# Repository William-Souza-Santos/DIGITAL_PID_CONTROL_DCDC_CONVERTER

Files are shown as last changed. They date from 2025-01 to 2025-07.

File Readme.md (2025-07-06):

# ⚡ FUZZY CONTROL APPLIED TO A BIDIRECTIONAL BUCK-BOOST DC-DC CONVERTER

This project presents the design and implementation of a four-switch bidirectional buck-boost DC-DC converter, featuring a fuzzy logic-based digital control system. The converter is designed for embedded and automotive power applications, ensuring stability, precision, and adaptability in bidirectional energy management.

---

## 🔍 Circuit Overview

<p align="center">
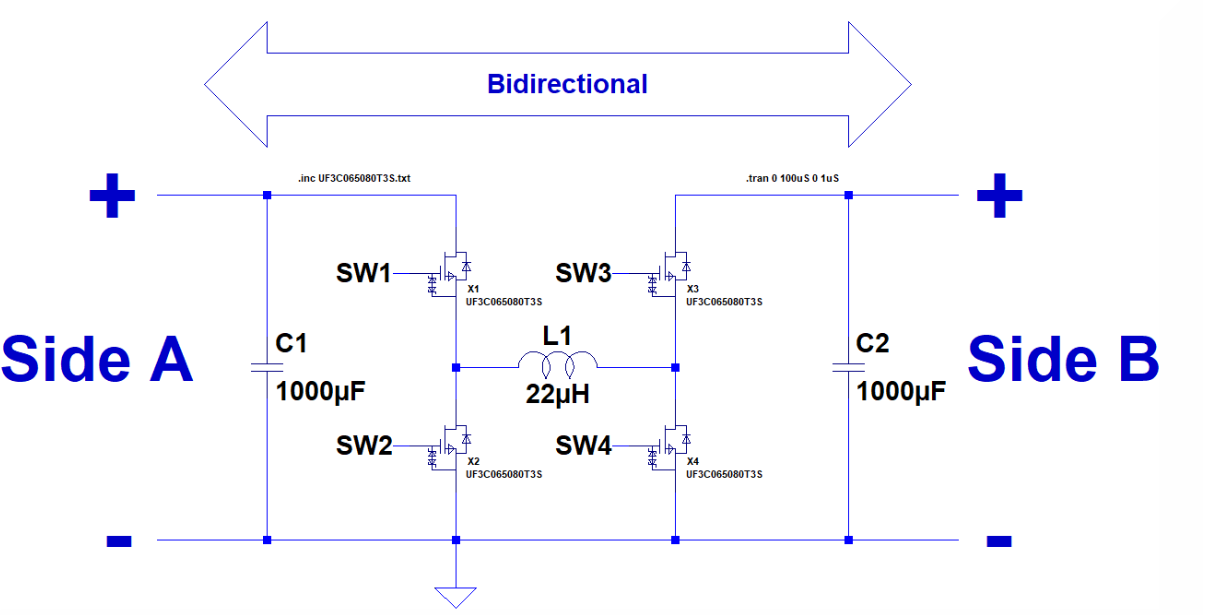
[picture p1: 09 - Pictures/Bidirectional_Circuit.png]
  
</p>

---

## 🔧 Project Highlights

- Implementation of a non-linear fuzzy logic controller to dynamically regulate the converter's duty cycle.
- Simulations conducted in **MATLAB/Simulink** and **Proteus**, covering both open-loop and closed-loop control strategies.
- Embedded firmware developed for the **ATmega328P** microcontroller to enable real-time control.
- Complete **PCB design**, including schematic capture, PCB layout, and 3D visualization.

---

## 🎯 Objective

To design and validate a high-efficiency bidirectional DC-DC converter capable of operating in buck, boost, and buck-boost modes, maintaining stable output voltage under varying load and input conditions.

---

## 🚗 Motivation: Automotive and Beyond

The primary motivation for this project lies in the growing demand for reliable DC-DC power converters in **automotive systems**, where multiple ECUs operate at different voltage levels. A bidirectional buck-boost converter ensures safe and efficient energy flow between these modules and energy storage systems such as batteries or supercapacitors.

Although tailored for automotive use, the converter is also applicable to:

- 🔋 Battery Management Systems (BMS)  
- ☀️ Renewable Energy Systems  
- 🏭 Industrial Automation  
- ✈️ Aerospace Power Electronics  

---

## 🧪 Simulation: Circuit in Proteus

<p align="center">
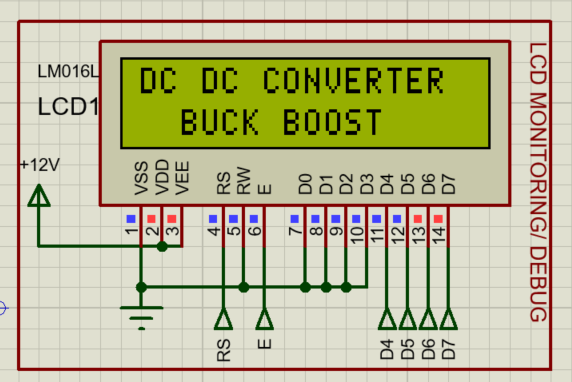
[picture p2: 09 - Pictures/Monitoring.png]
  
</p>

<p align="center">
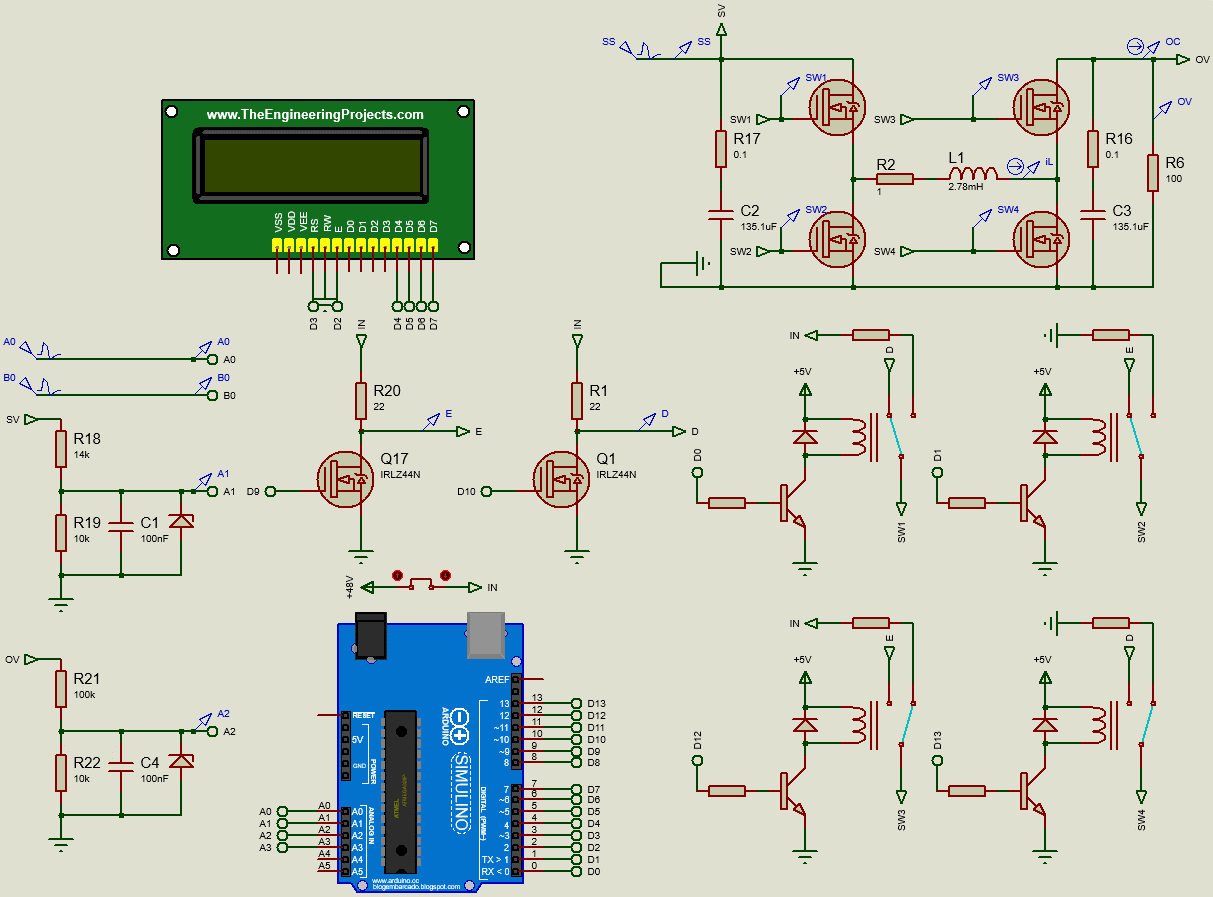
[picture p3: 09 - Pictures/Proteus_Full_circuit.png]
  
</p> 

---

## 📝 Theoretical Foundations

<p align="center">
  <strong>Operating Modes</strong><br>
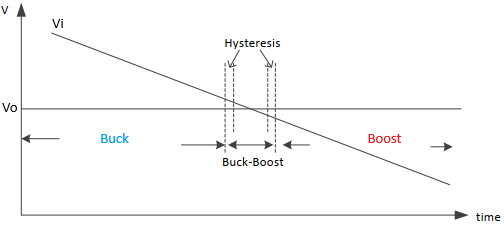
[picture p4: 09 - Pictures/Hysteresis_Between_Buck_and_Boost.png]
  <br>
</p>

<p align="center">
  <strong>BUCK</strong><br>
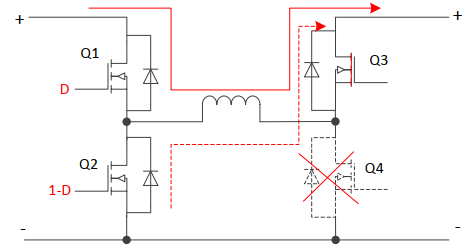
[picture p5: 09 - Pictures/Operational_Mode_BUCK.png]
  <br>
</p>

<p align="center">
  <strong>BUCK-BOOST (Transition Mode)</strong><br>
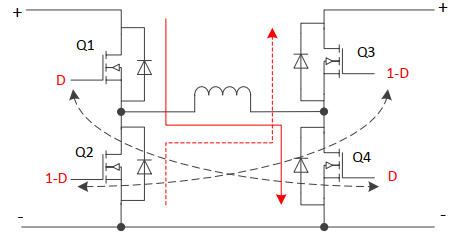
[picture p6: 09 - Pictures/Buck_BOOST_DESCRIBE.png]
  <br>
</p>

<p align="center">
  <strong>BOOST</strong><br>
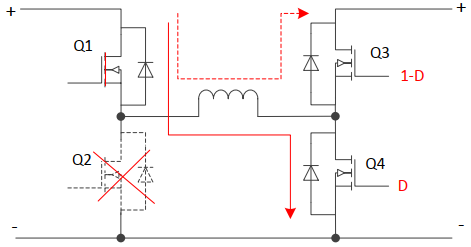
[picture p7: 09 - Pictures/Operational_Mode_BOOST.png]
  <br>
</p>

---

## 📝 Theoretical Foundations (Table Operating)

<p align="center">
  <strong>A-B OPERATING</strong><br>
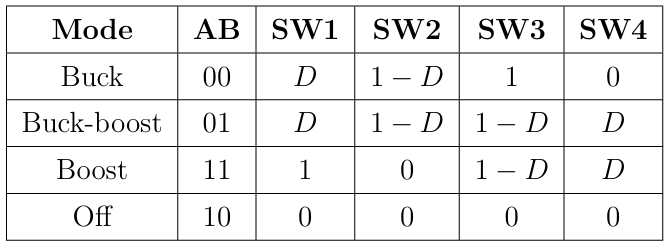
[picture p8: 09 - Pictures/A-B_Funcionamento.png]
  <br>
</p>

<p align="center">
  <strong>B-A OPERATING</strong><br>
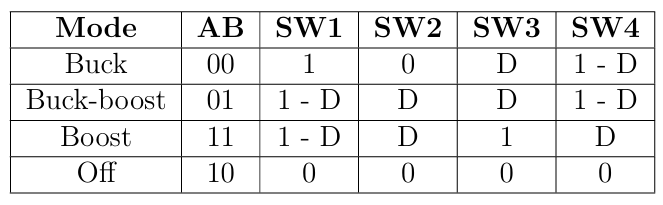
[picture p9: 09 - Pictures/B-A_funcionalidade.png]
  <br>
</p>

---

## 🔁 Bidirectional Operation (Open-Loop Tests)

<p align="center">
  <strong>A → B (Boost Mode)</strong><br>
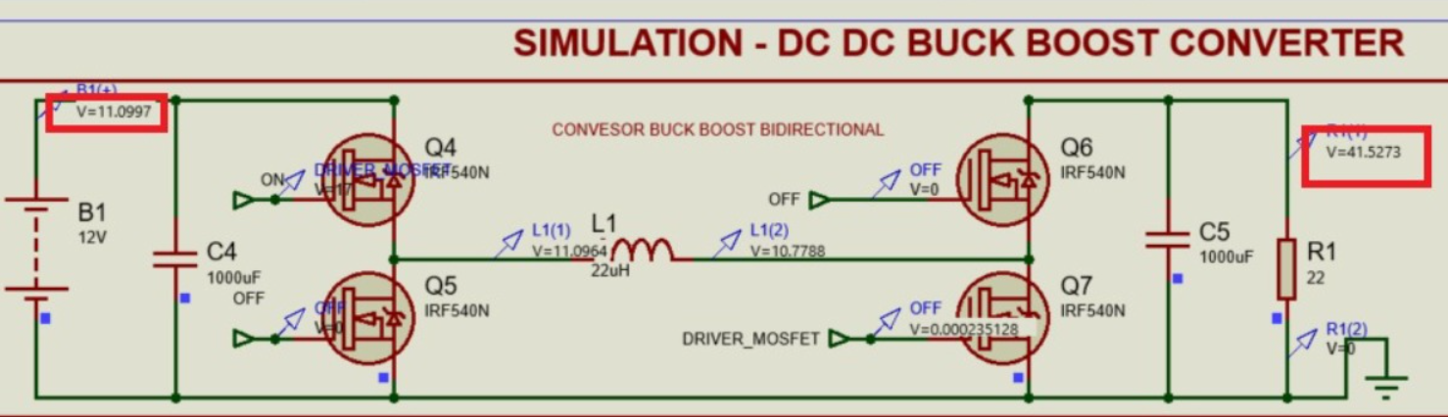
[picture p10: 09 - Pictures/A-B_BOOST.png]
  <br>
</p>

<p align="center">
  <strong>A → B (Buck Mode)</strong><br>
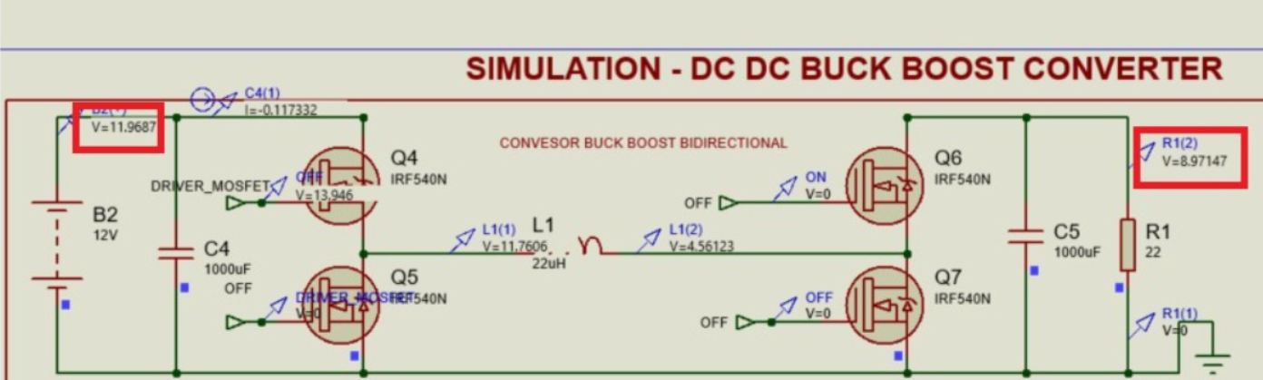
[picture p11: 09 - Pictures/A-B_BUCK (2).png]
  <br>
</p>

<p align="center">
  <strong>B → A (Boost Mode)</strong><br>
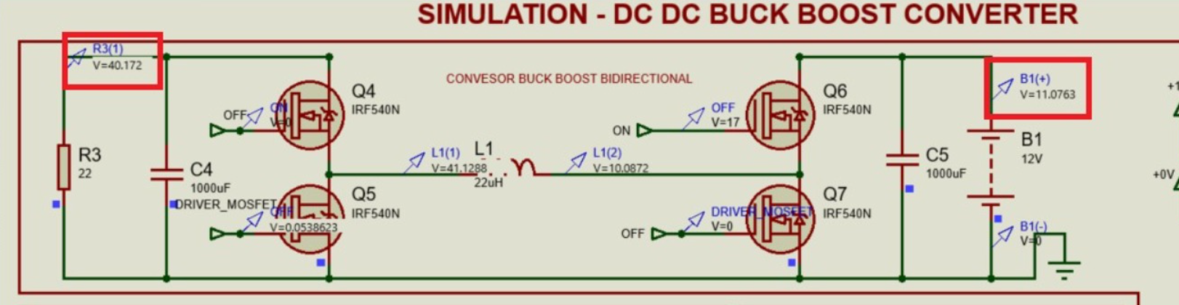
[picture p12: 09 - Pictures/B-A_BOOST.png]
  <br>
</p>

<p align="center">
  <strong>B → A (Buck Mode)</strong><br>
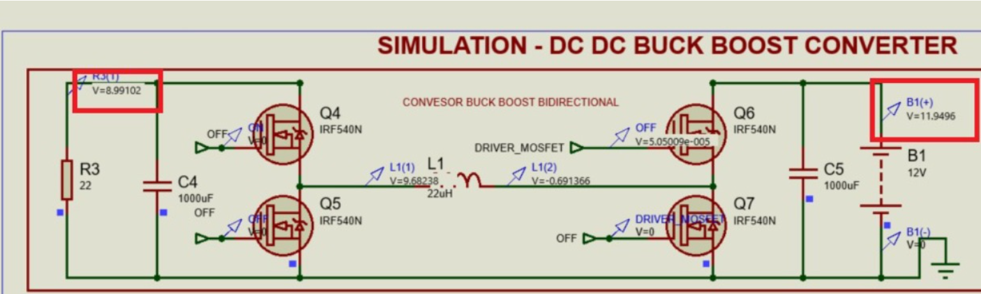
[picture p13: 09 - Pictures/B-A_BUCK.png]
  <br>
</p>

<!--
## 📉 Theorical Fundamentation and Transition Mode

<p align="center">
  <strong>Buck Waveform</strong><br>
  <img src="09 - Pictures/Curve_buck.bmp" width="800"><br>
</p>

<p align="center">
   <strong>Boost Waveform</strong><br>
  <img src="09 - Pictures/Curves_Boost.bmp" width="800">
</p>
-->

---
## 🖥️ Choosing a Microcontroller

<p align="center">
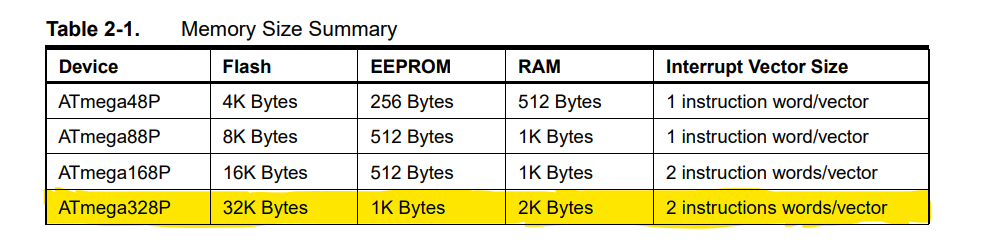
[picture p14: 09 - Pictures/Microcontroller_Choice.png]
  <br>
</p>

---

## 🤖 Fuzzy Control System (Closed-Loop in Simulink)

<p align="center">
  <strong>Closed-Loop Control Model</strong><br>
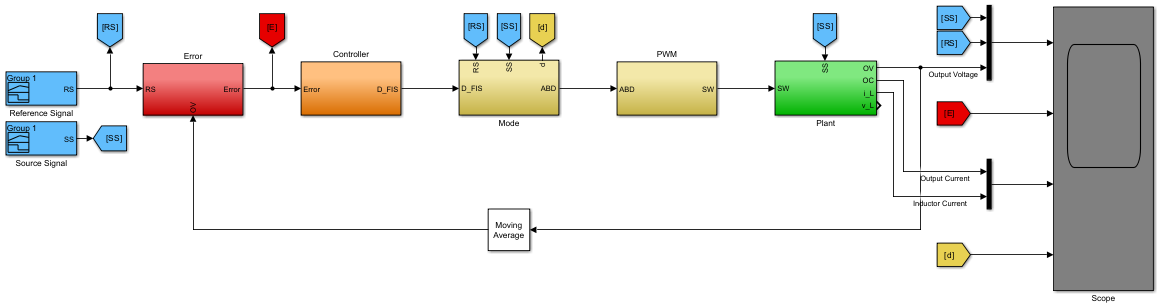
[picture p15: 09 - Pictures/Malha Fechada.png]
  <br>
</p>

---

## 🧩 Schematic

<p align="center">
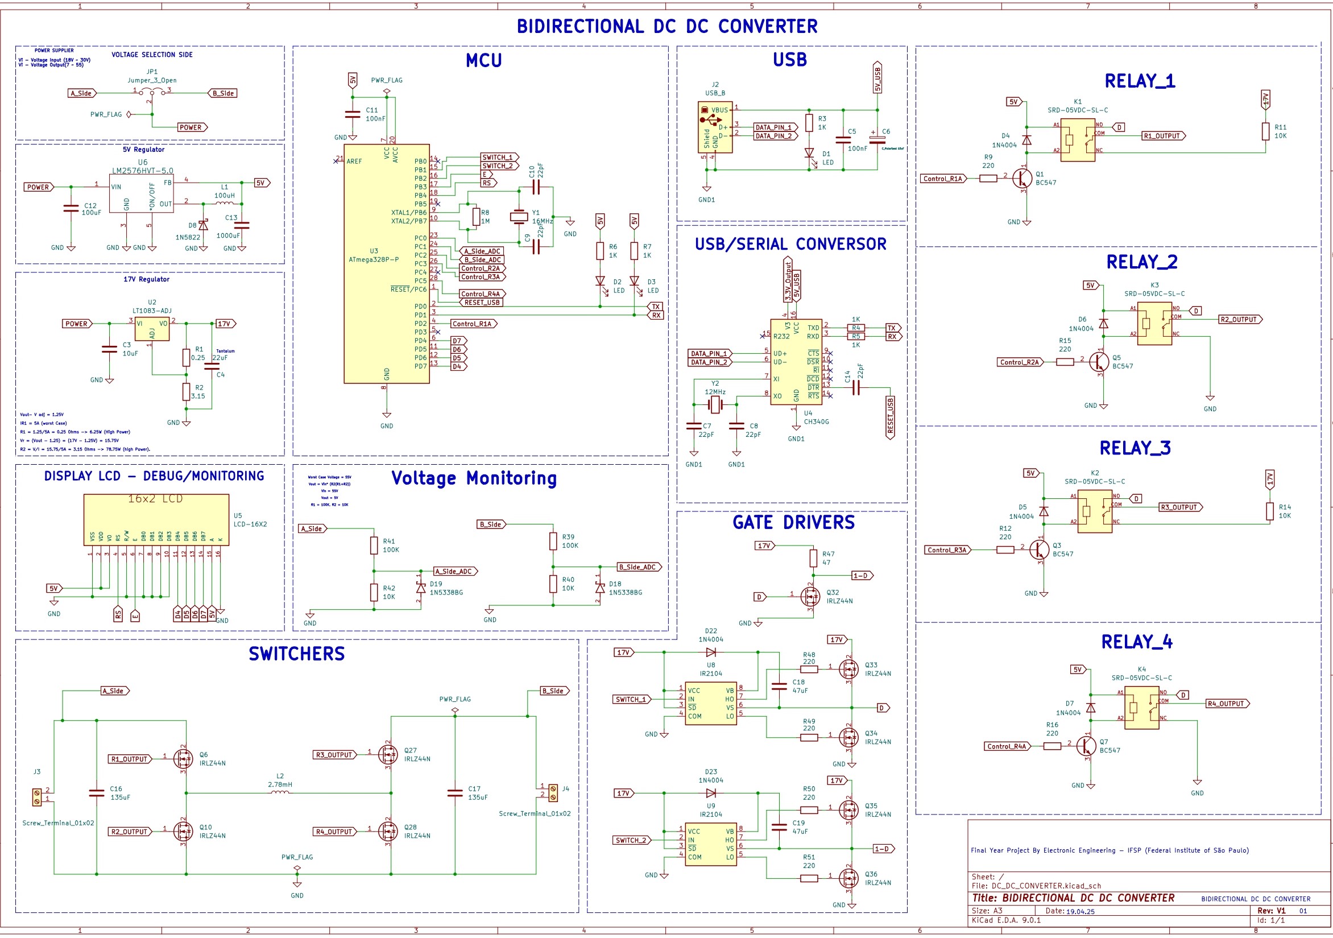
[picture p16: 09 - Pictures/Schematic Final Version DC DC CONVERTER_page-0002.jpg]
  <br>
</p>

---

## 🧱 3D PCB View

<p align="center">
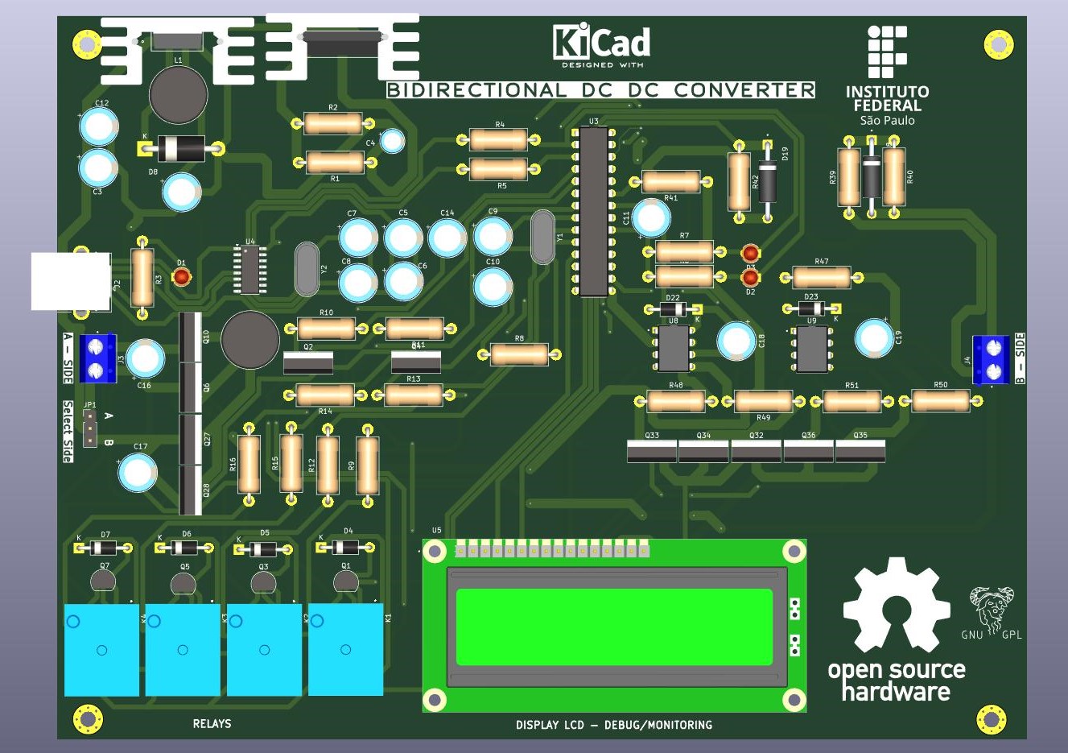
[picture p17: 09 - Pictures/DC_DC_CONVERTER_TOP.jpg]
  <br>
</p>

---

## 👨‍💻 Authors

- Marcelo Oliveira de Jesus Júnior  
- Victor Pereira dos Santos  
- William Souza Santos

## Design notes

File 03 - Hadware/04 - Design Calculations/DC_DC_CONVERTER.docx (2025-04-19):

Os cálculos a seguir foram referenciados no aplication notes da Texas Intruments:

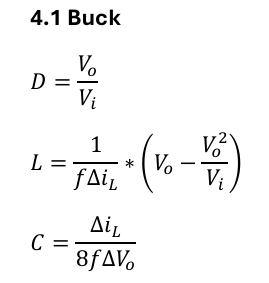
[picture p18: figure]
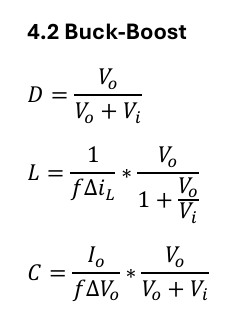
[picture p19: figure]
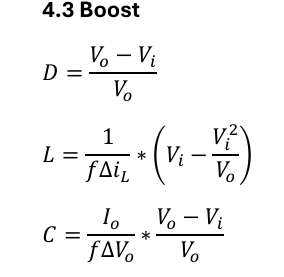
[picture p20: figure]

1. Design
- Input Voltage Range: Vi = [18,30] V
- Duty Cycle Range D = [0.2,0.85]
- Output Voltage: Vo = [1 – 55] V (Variável)
- Output Current: 2A
- Switching Frequency: f = 10kHz
- Inductor current ripple: 0.6 (30%)
- Output Voltage Ripple: 1V (variável)
2. Operating Mode

Mode | Vi | D | Vi/Vo
Buck | [25 - 30] | [Vo/Vi] | 25/Vo (1.10)
Buck-Bost | [22 - 25] | [Vo/(Vo+Vi)] | -
Boost | [18 - 22] | [(Vo-Vi)/Vo] | 22/Vo (0.9)

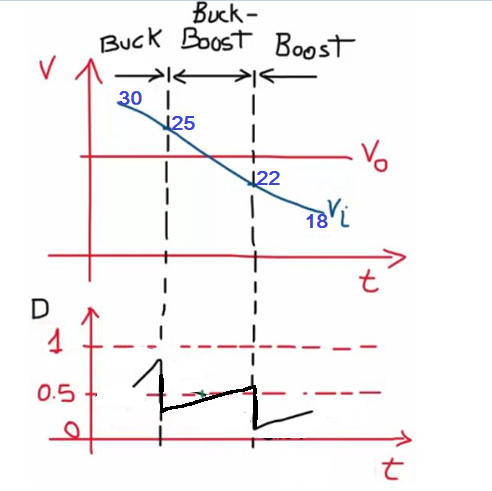
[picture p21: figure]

3. Inductor and capacitor Buck

Vomax = 27V

VoMin = 1V

Lmax = 0.00045

Lmin = 1.61x10^-4

  3.1 Inductor and capacitor Buck Boost

VoMax = 25

VoMin = 22

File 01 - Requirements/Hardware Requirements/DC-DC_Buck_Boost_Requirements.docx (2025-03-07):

# Requirements Document - DC-DC Buck-Boost Converter

## 1. Introduction

### 1.1 Objective

This document defines the technical and functional requirements for the development of a DC-DC Buck-Boost converter, detailing the electrical, mechanical, and environmental specifications of the system.

### 1.2 Scope

The converter will be designed for embedded applications, powering loads of sensitive electronic devices. The system must be efficient, compact, and reliable.

## 2. General Requirements

### 2.1 Electrical Specifications

- **Input Voltage (Vin):** 17V to 30V
- **Output Voltage (Vout):** 20V to 45V adjustable
- **Output Current (Iout):** Up to 5A
- **Efficiency:** >= 97% under nominal conditions
- **Switching Frequency:** 100kHz to 500kHz (to be defined in the future)
- **Output Voltage Ripple:** <= 50mVpp (to be defined in the future)
- **Protections:** Overcurrent, overvoltage, short-circuit, and overtemperature (to be defined in the future)

### 2.2 Mechanical Requirements

- Maximum dimensions: 50mm x 50mm x 20mm
- Weight: <= 50g
- Connection interface: Standard terminals or connectors

### 2.3 Environmental Conditions

- **Operating Temperature:** -40°C to 85°C
- **Relative Humidity:** 10% to 90% (non-condensing)
- **Vibration Resistance:** According to MIL-STD-810G standard

## 3. Functional Requirements

- Ability to operate in Buck, Boost, or Buck-Boost mode automatically
- PWM control with dynamic adjustment
- Voltage and current monitoring via digital interface (I2C, SPI, or UART)
- Closed-loop feedback for precise regulation

## 4. Reliability and Testing Requirements

- Maximum load and voltage variation tests
- Transient response test
- Thermal analysis for heat dissipation verification
- Electromagnetic immunity testing (EMI/EMC)

## 5. Documentation and Certification

- Electrical schematic and PCB layout
- Compliance analysis with IEC 60950-1 and CISPR 22 standards
- User and integration manual

## 6. Final Considerations

The design of the DC-DC Buck-Boost converter must follow the guidelines presented in this document to ensure an efficient and reliable product suitable for its intended applications.

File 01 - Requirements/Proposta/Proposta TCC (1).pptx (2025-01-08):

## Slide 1

CONTROLE PID DIGITAL APLICADO AO CONVERSOR DC DC BUCK BOOST

BACHARELADO EM ENGENHARIA ELETRÔNICA

PROPOSTA DE TCC

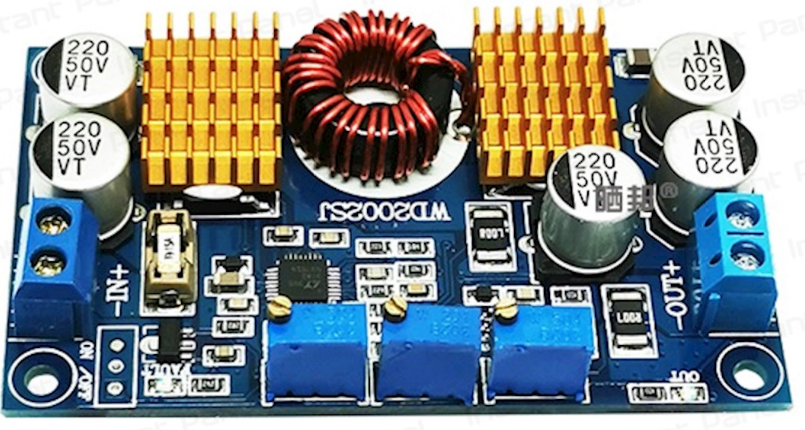
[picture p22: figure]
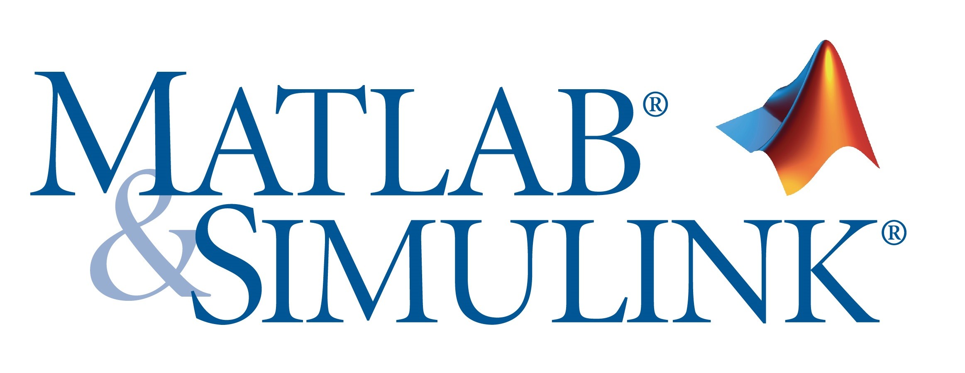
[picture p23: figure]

ALUNOS:
VICTOR PEREIRA – SP3060608
WILLIAM SOUZA SANTOS – SP3061418
(Obs: possivelmente será acrescentado mais pessoas).

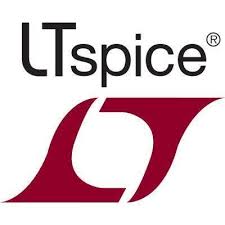
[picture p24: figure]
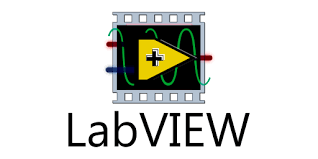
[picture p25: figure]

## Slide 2

MOTIVAÇÃO : APLICAÇÃO EM INTERFACE ENTRE MÓDULOS ELETRÔNICOS AUTOMOTIVOS DE DIFERENTE TENSÕES

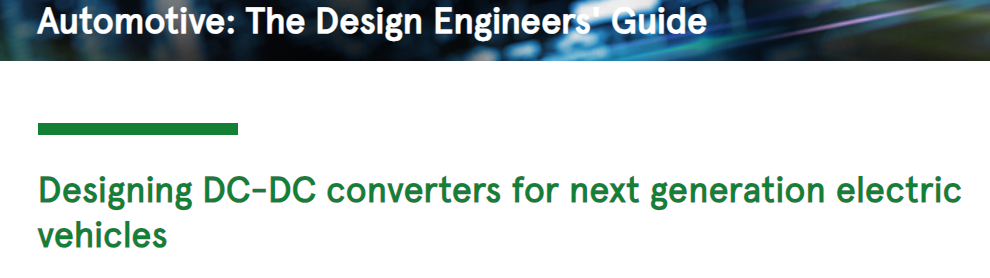
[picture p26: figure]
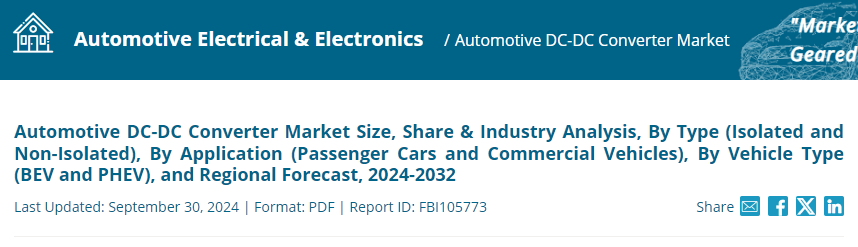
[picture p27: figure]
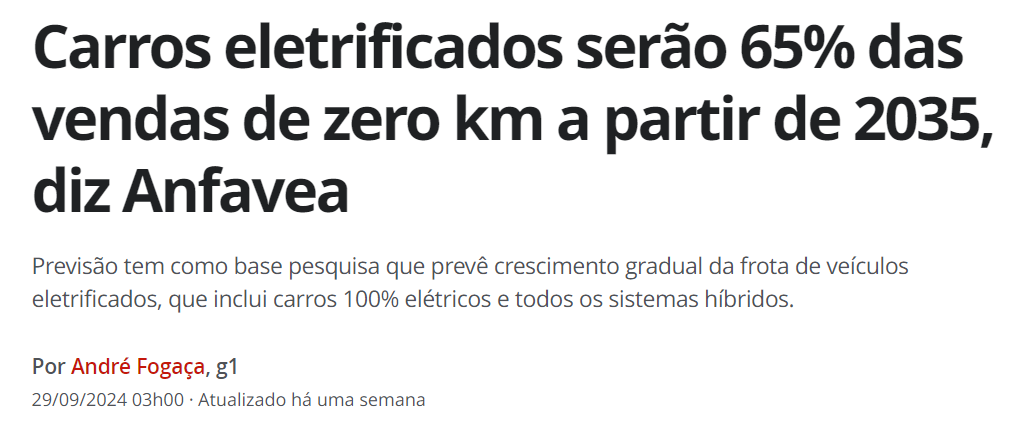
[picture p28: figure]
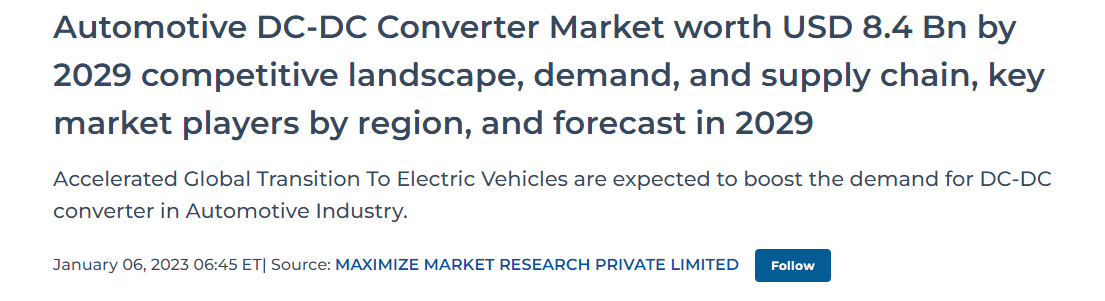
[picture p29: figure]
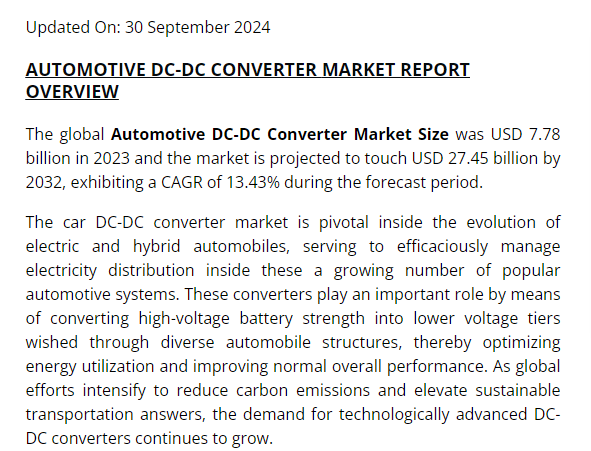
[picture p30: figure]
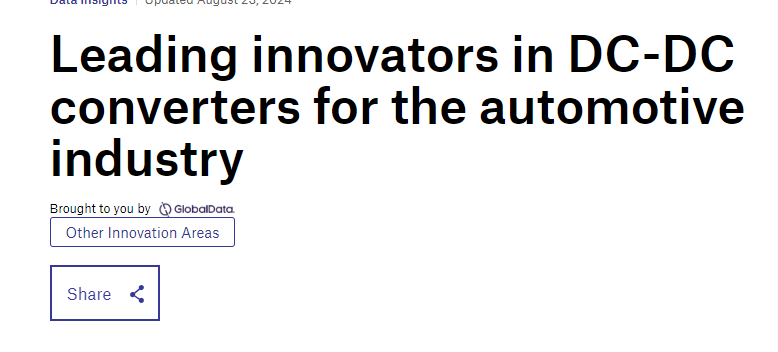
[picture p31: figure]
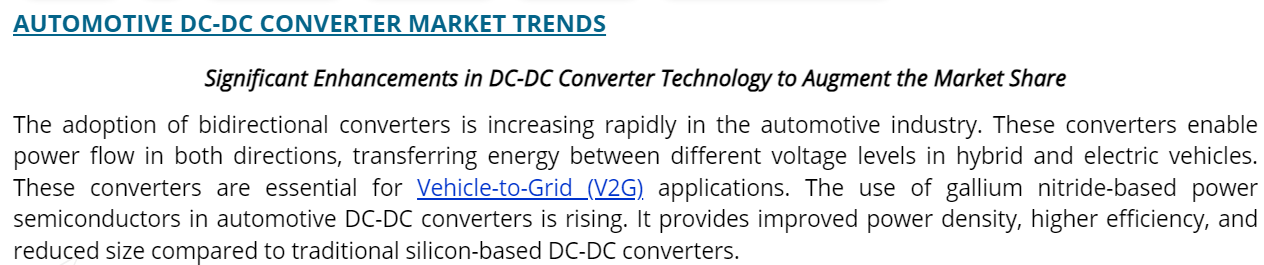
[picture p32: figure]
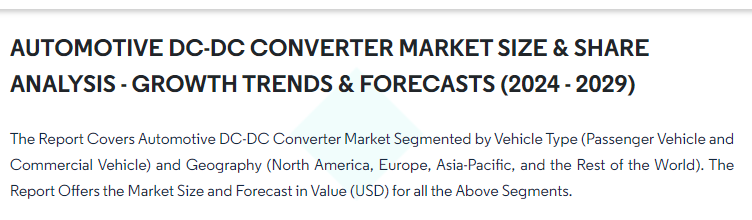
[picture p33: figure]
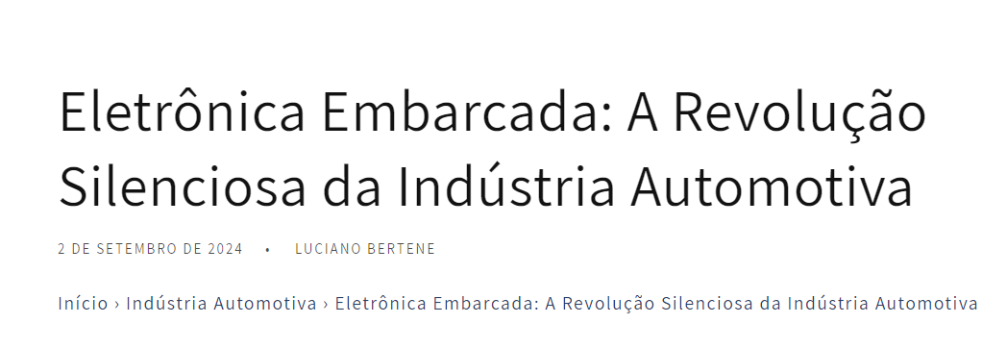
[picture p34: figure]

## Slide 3

EMPRESAS QUE TEM PROJETOS SIMILARES

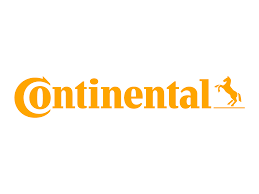
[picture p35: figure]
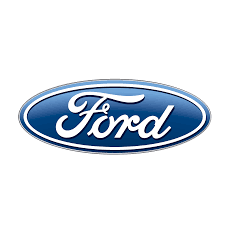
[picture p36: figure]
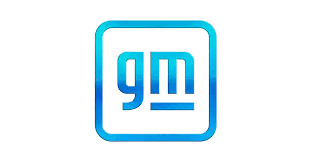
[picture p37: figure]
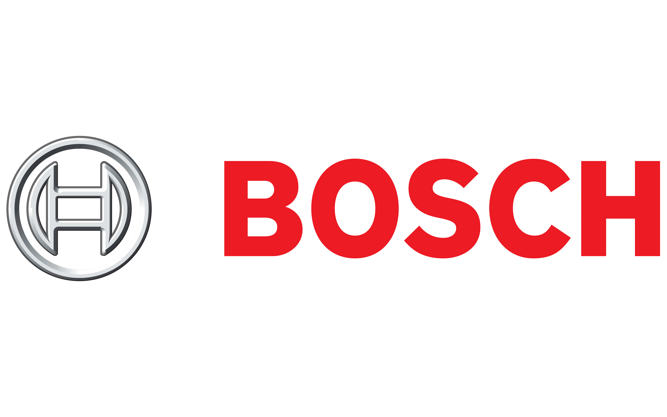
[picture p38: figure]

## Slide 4

EMPRESAS QUE TEM PROJETOS SIMILARES (PORTFÓLIO)

Portfólio das Empresas

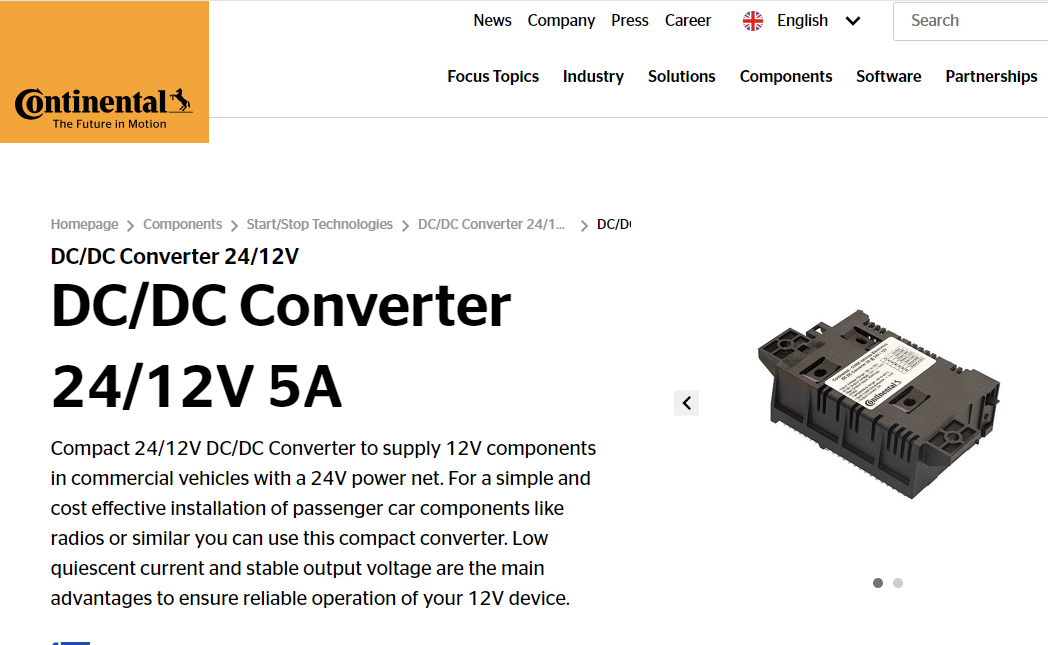
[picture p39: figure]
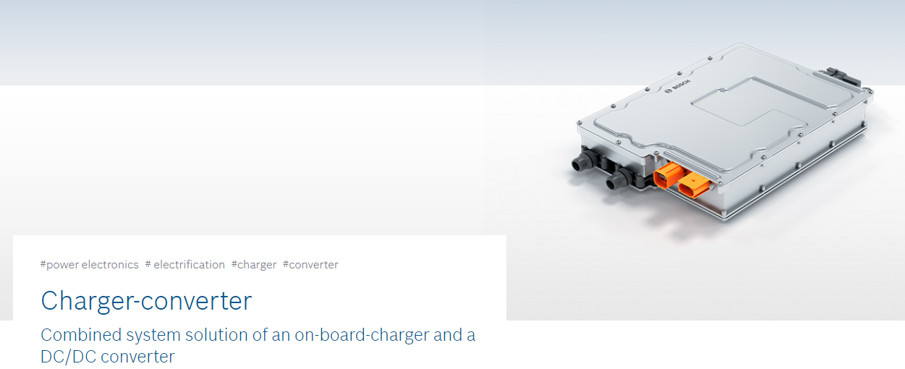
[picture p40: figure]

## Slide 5

OBJETIVO : DESENVOLVIMENTO DE UM CONVERSOR DC DC BUCK BOOST COM COMPONENTES DISCRETOS MICROCONTROLADO UTILIZANDO UM PID DIGITAL

HW (Hardware) Features:
Microcontrolador: Utilizar um microcontrolador com conversores ADC (Analog-to-Digital Converter) e DAC (Digital-to-Analog Converter) integrados.
Conversor Buck-Boost: Implementação de um conversor Buck-Boost com indutor, capacitor, MOSFETs e diodos
Sensores de tensão e corrente: Sensores como resistores de shunt para medir a corrente e divisores de tensão para a leitura da tensão de entrada e saída
Proteções: Implementar proteções como limitadores de corrente, proteção contra sobretensão e sobretemperatura.
Sistema de comunicação: Implementação de comunicação serial (I2C, SPI, UART) para monitoramento remoto ou integração com sistemas maiores.
*Operação Bidirecional: Capacidade de operar em ambos os sentidos de potência: O conversor pode transferir energia da entrada para a saída ou vice-versa (por exemplo, para sistemas de armazenamento de energia como baterias).

SW (Software) Features:
Ajuste automático dos parâmetros PID: Implementar métodos de auto-ajuste ou calibração automática dos parâmetros PID.
Filtros digitais: Uso de filtros digitais (ex: filtro de média móvel ou filtro passa-baixa) para suavizar leituras de sensores.
Interface gráfica (GUI): Desenvolvimento de uma interface gráfica simples para ajuste remoto de parâmetros PID e monitoramento dos valores do sistema.
Log de dados: Sistema de registro de dados para monitorar o comportamento do sistema ao longo do tempo e analisar o desempenho.
*Sistema de Telemetria: Monitoramento em Tempo Real, Ajustes Remotos, Registro e Análise de Dados.

*Feature avançada

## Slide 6

Fundamentação Científica (Alguns artigos que podem ser usados como consulta)

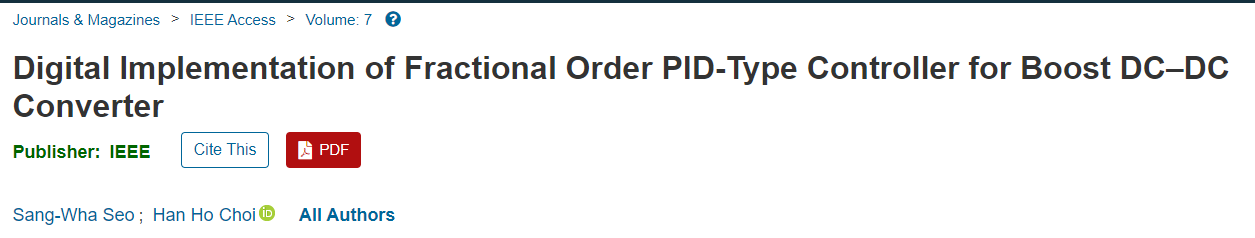
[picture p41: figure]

Link para o artigo: https://ieeexplore.ieee.org/document/8854776


Link para o artigo: https://pt.scribd.com/document/679721829/05744616


Link para o artigo: https://ieeexplore.ieee.org/document/8811451


Link para o artigo: https: https://theses.gla.ac.uk/82318/

Link para o artigo: https://www.sciencedirect.com/science/article/abs/pii/S0967066121001593


Link para o artigo: https://www.sciencedirect.com/science/article/pii/S1877050920310292

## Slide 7

Possíveis Orientadores (Com base no currículo lattes)

Possíveis Orientadores
DEL (Departamento de Engenharia Elétrica) – IFSP:
SARA DERESTE DOS SANTOS Lattes: http://lattes.cnpq.br/8110306745666405 (Microeletrônica)
RAFAEL CUERDA MONZANI Lattes: http://lattes.cnpq.br/7715420164654804 (Power Eletronics)
RICARDO PIRES Lattes: http://lattes.cnpq.br/7621984053230170 (Sistemas Automáticos/Microeletrônicos)
RODRIGO RECH Lattes: http://lattes.cnpq.br/8648052996681367 (Sistemas Embarcados)

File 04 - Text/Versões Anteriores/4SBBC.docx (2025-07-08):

1. Basic Configuration of a Buck-Boost Converter

2. Operating Principle

D=1-D

2.1 Synchronize Buck

D=(V_o)/(V_i)

V_i >V_o

Only two switches commutate.

Can’t operate with V_i =V_o or D=1 .

Q3 is fully turned on and Q4 is fully turned off. Q1 and Q2 are controlled by D and 1-D, respectively, the converter becomes a synchronize buck converter, as shown in Figure 4.


2.2 Synchronize Boost

D=1-(V_i)/(V_o)

Only two switches commutate.

Can’t operate with V_i =V_o or D=0 .

Q1 is fully turned on and Q2 is fully turned off. Q4 and Q3 are controlled by D and 1-D, respectively, the converter becomes a synchronize boost converter, as shown in Figure 5.


2.3 Synchronize Buck-Boost

D=(V_o)/(V_i +V_o)

V_i ≈V_o

Four switches commutate.

Can operate with V_i =V_o or D=0.5 .

Higher switches losses.

Lower efficiency.

Q1 and Q4 are controlled by D, Q2 and Q3 are controlled by 1-D. The converter becomes a synchronize buck-boost converter, as shown in Figure 6.


3. Operation mode

The 4-switch power stage changes its operation mode according to DC Bus and battery voltage, as shown in Figure 10. To prevent mode from bouncing, hysteresis is added between the buck and buck-boost modes and between the buck-boost and boost modes.


Closed-loop compensator must be designed for stable operation.

Transient perturbations during mode changes.

4. Implementation

MOSFETs used as switches.

High-side switches (S1, S3) need to be driven.

Dead time must be added to avoid shoot-through current.

Bootstrap cannot be used: it can’t keep high-side switches continuously on.

Typical solutions: transformer-based gate drivers, optocoupler-based gate drivers.

4.1 Buck

D=(V_o)/(V_i)

L=1/(fΔi_L)*(V_o -(V_o^2)/(V_i))

C=(Δi_L)/(8fΔV_o)

4.2 Buck-Boost

D=(V_o)/(V_o +V_i)

L=1/(fΔi_L)*(V_o)/(1+(V_o)/(V_i))

C=(I_o)/(fΔV_o)*(V_o)/(V_o +V_i)

4.3 Boost

D=(V_o -V_i)/(V_o)

L=1/(fΔi_L)*(V_i -(V_i^2)/(V_o))

C=(I_o)/(fΔV_o)*(V_o -V_i)/(V_o)

5. Design example

Input voltage range: V_i =[35,70] V

Duty cycle range: D=[0.1,0.85]

Output voltage: V_o =48 V

Output current: I_o =2 A

Switching frequency: f=100 kHz

Inductor current ripple: 0.6 A (30%)

Output voltage ripple: 1 V (2%)

Operating mode | Vi | D | Vi/Vo
Buck | [57-70] | [0.686,0.842] | 1.1875
Buck-boost | [43,57] | [0.457,0.527] | -
Boost | [35,43] | [0.104,0.271] | 0.8958


5.1 Inductor and Capacitor (Buck)

L_(max) =1/(fΔi_L)*(V_o -(V_o^2)/(V_i _(max)))=1/(100*10^3 *0.6)*(48-(48^2)/70)=0.251 mH

C=(Δi_L)/(8fΔV_o)=0.6/(8*100*10^3 *1)=0.75 uF

5.2 Inductor and Capacitor (Buck-Boost)

L_(max) =1/(fΔi_L)*(V_o)/(1+(V_o)/(V_i _(max)))=1/(100*10^3 *0.6)*48/(1+48/57)=0.434 mH

C_(max) =(I_o)/(fΔV_o)*(V_o)/(V_o +V_i _(min))=2/(100*10^3 *1)*48/(48+57)=10.6 uF

5.3 Inductor and Capacitor (Boost)

V_i >(V_o)/2

L_(max) =1/(fΔi_L)*(V_i _(min) -(V_i _(min)^2)/(V_o))=1/(100*10^3 *0.6)*(35-(35^2)/48)=0.158 mH

C_(max) =(I_o)/(fΔV_o)*(V_o -V_i _(min))/(V_o)=2/(100*10^3 *1)*(48-35)/48=5.42 uF

5.4 Verification

L=0.434 mH

C=10.6 uF

Operating mode | Vi (V) | D | Vi/Vo | Δi_L (A) | ΔV_o (V)
Buck | [57,70] | [0.686,0.842] | 1.1875 | [0.175,0.348] | 0.071
Buck-boost | [43,57] | [0.457,0.527] | - | [0.522,0.6] | [0.806,1]
Boost | [35,43] | [0.104,0.271] | 0.8958 | [0.103,1.218] | [0.196,0.511]

5.5 Simulink implementation

O circuito base do conversor é implementado no Simulink em um subsistema conforme abaixo.


O subsistema possui 5 entradas, sendo elas: Source Signal (SS), Switch 1, Switch 2, Switch 3 e Switch 4. E 4 saídas, sendo elas: Output Voltage (OV), Output Current (OC), Inductor Voltage (v_L) e Inductor Current (i_L).

Os 4 modos de funcionamento dependem do estado dos 4 Switches e do seu Duty Cycle respectivo. Como temos 4 modos diferentes, precisamos de 2 bits para representar os modos. A tabela abaixo resume a lógica da ativação de cada Switch usando A e B como entradas lógicas.

Mode | AB | SW1 | SW2 | SW3 | SW4
Buck | 00 | D | 1 - D | 1 | 0
Buck-boost | 01 | D | 1 - D | 1 - D | D
Boost | 11 | 1 | 0 | 1 - D | D
Off | 10 | 0 | 0 | 0 | 0

Usando conhecimentos de sistemas digitais, podemos simplificar a relação para cada Switch, chegando nas equações abaixo.

SW1=AD+AB

SW2=AD

SW3=AB+BD

SW4=BD

A partir das relações acima, podemos implementar no Simulink um subsistema para aplicar o funcionamento de cada Switch a partir das entradas A e B.


Agora precisamos de uma forma para calcular o modo de funcionamento atual e futuro do sistema. Uma forma direta seria a partir da relação entre Tensão de Entrada e Tensão de Referência, conforme a tabela abaixo.

Operating mode | Vi (V) | Vi/Vo
Buck | [57,70] | 1.1875
Buck-boost | [43,57] | -
Boost | [35,43] | 0.8958

A tabela indica que, enquanto a Tensão de Entrada estiver acima de 118.75% da Tensão de Referência, o modo de funcionamento será Buck. No nosso caso, enquanto a Tensão de Entrada for maior que 57 V. Seguindo a mesma lógica, enquanto a Tensão de Entrada estiver abaixo de 89.58% da Tensão de Referência, o modo de funcionamento será Boost. No nosso caso, enquanto a Tensão de Entrada for menor que 34 V. O meio termo, entre 118.75% e 89.58%, indicará o modo Buck-Boost.

Podemos escrever essa relação conforme abaixo.

X=(V_i)/(V_o)>1.1875

Y=(V_i)/(V_o)>0.8958

A tabela abaixo resume a lógica do modo de funcionamento acima.

XY | Buck | Buck-Boost | Boost
00 | 0 | 0 | 1
01 | 0 | 1 | 0
11 | 1 | 0 | 0
10 | X | X | X

Usando conhecimentos de sistemas digitais, podemos simplificar a relação, chegando nas equações abaixo.

Buck=X

Buck-Boost=XY

Boost=Y

A lógica acima pode ser implementada no Simulink usando o subsistema a seguir.


Agora que temos definido qual modo será ativado, precisamos do cálculo do Duty Cycle. Cada modo terá seu Duty Cycle calculado, porém somente aquele ativado no momento será usado no funcionamento dos Switches. Conforme vimos anteriormente, para o cálculo precisamos somente da Tensão de Entrada e Tensão de Referência, conforme a seguir.


O valor de A e B, escolhido anteriormente conforme a tabela abaixo, também é anexado junto ao seu respectivo D pelo MUX.

Mode | AB
Buck | 00
Buck-boost | 01
Boost | 11

Para definir qual valor será utilizado, usamos o resultado do subsistema anterior juntamente com comparadores lógicos para levar o valor até as variáveis A, B e D pelo DEMUX, conforme abaixo.


Como somente um dos comparadores estará ativo por vez, A e B pode ser calculado com uma porta OR enquanto D pode ser calculado como uma soma simples, conforme abaixo.


Por fim, para propósitos de controle, podemos somar a variável D com uma entrada externa (D_FIS). Também, como definido anteriormente, o Duty Cycle é saturado entre 0.1 e 0.85 e o PWM trabalha em uma frequência de 100 kHz, conforme abaixo.

Assim, obtemos nosso subsistema responsável por determinar a variável D (PWM) do sistema.


Com as variáveis A, B e D determinadas, o funcionamento dos Switches também estão determinados e, portanto, o sistema está pronto para funcionamento em malha aberta.

Para visualizar o erro e sua variação precisamos de um subsistema. O erro pode ser definido pelo quão distante está a Tensão de Saída da Tensão de Referência, por exemplo, se minha saída for 70 V e minha referência 48 V, temos um erro de 22 V. A variação do erro pode ser definida pela diferença entre o erro atual e anterior, assumindo o uso de valores discretos. Para facilitar a visualização do desempenho, vamos empregar um erro normalizado, conforme abaixo.

E[n]=(V_o -V_r)/(|V_o -V_r |+1)

dE[n]=E[n]-E[n-1]

O subsistema aplicado no Simulink pode ser visualizado abaixo.


O resultado final do sistema em malha aberta e visualização do erro a partir da união dos subsistemas, pode ser visualizado abaixo.


O sinal de entrada (SS) consiste em uma rampa definida pela função abaixo.

SS(t)=70-35/3t


O sinal de referência (RS) consiste em uma constante definida pela função abaixo.

RS(t)=48


O sistema será simulado durante 3 segundos.


Podemos identificar facilmente os pontos de transição do modo de operação pela falta de histerese. Também se observa um erro na tensão de saída (vermelho) pela falta de um compensador.


Nota-se uma taxa de variação inicial do erro (magenta) por causa da ativação do sistema até sua operação em estado estacionário, e outras variações durante a troca de operação. O erro (vermelho) indica que o sistema não atinge e fica abaixo da tensão de referência durante seu funcionamento pela falta de um compensador.


A corrente do indutor ficou entre 2 e 4 A, não levando em consideração o ripple de 0.6 A. A corrente de saída permaneceu em 2 A, mas com pequenas variações durante a troca de operação.


O valor do Duty Cycle obedece ao cálculo do modo de operação e se mantém no range designado anteriormente de 0.1 a 0.85. O valor do controle segue os mesmos valores pois não há um compensador implementado.

Usaremos um Fuzzy Inference System (FIS) como compensador e corrigir o erro do sistema. Sabemos que o comportamento do sistema depende do Duty Cycle, então iremos compensar esse valor e usá-la como variável manipulada.

A partir do subsistema de erro, temos que ele varia entre -1 e 1. Um erro negativo indica que a Tensão de Saída (variável controlada) está abaixo da Tensão de Referência e precisamos de uma compensação positiva no Duty Cycle, enquanto um erro positivo indica estar acima e precisamos de uma compensação negativa. A variação do erro é análoga, porém ajuda a observar o comportamento seguinte e ajustá-lo previamente.

Com as informações anteriores, podemos criar um FIS com duas entradas, uma para o Error e outra para o dError. Para determinar os pesos das entradas usaremos uma função membro em formato Z para erros negativos e uma função membro em formato S para erros positivos, conforme a abaixo.


O mesmo será feito para a entrada dError, conforme abaixo.


Para determinar o ajuste na saída

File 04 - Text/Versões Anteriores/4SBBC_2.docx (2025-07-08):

1. Configuração básica de um conversor Buck-Boost

O conversor DC-DC Buck-Boost, conforme a Figura X, é um tipo de conversor de potência que pode produzir uma tensão de saída maior ou menor que a tensão de entrada.

Figura X: Esquemático do Conversor Buck-Boost

Fonte: SLVA535B

Ele é composto pelos seguintes componentes principais:

- SW 1, SW 2, SW 3, SW 4: quatro comutadores, geralmente implementadas com MOSFETs. O chaveamento controlado dessas chaves determina o aumento ou redução da tensão.
- L: indutor responsável por armazenar a energia e realizar sua transferência a partir do funcionamento dos comutadores.
- CIN: capacitor de entrada para filtrar oscilações e fornecer uma tensão mais estável para o conversor.
- COUT: capacitor de saída para suavizar oscilações e fornecer uma tensão de saída mais estável para a carga.

2. Princípio de Operação

Ciclo de Trabalho é a fração de tempo em que um sinal ou uma chave está ligado dentro de um período fixo.

D=(T_(on))/T | (X)

Onde:

- D=ciclo de trabalho
- T_(on) =tempo que o sinal está ligado
- T=período do sinal

Ciclo de Trabalho Complementar é a fração de tempo em que o mesmo sinal está desligado dentro do mesmo período fixo.

1-D=(T_(off))/T | (X)

Onde:

- D=ciclo de trabalho complementar
- T_(off) =tempo que o sinal está desligado
- T=período do sinal

A Figura X descreve graficamente esse conceito e será útil futuramente, pois o ciclo de trabalho e seu complementar será necessário durante a aplicação do conversor.

Figura X: Ciclo de Trabalho Complementar


Fonte: Autor (Mathematica)

2.1 Buck Síncrono

A Figura X demonstra esse modo de funcionamento. O comutador Q3 é totalmente ligado e o comutador Q4 é totalmente desligado. Q1 e Q2 são controlados por D e 1 - D, respectivamente, e o sistema se torna um conversor Buck sincronizado.

Figura X: Buck Síncrono


Fonte: PMP21529

O ciclo de trabalho do modo Buck é calculado conforme a equação a seguir.

D=(V_o)/(V_i) | (X)

Onde:

- D=ciclo de trabalho
- V_o =tensão de saída
- V_i =tensão de entrada

Como nesse modo deseja-se reduzir a tensão de entrada, é necessário que esta seja maior que a tensão de saída ( V_i >V_o ). Apenas duas chaves são comutadas, e não é possível operar com V_i =V_o , pois nessas condições D=1 e o comutador Q1 fica ligado junto ao comutador Q3, causando um curto no sistema.

2.2 Boost Síncrono

A Figura X demonstra esse modo de funcionamento. O comutador Q1 é totalmente ligado e o comutador Q2 é totalmente desligado. Q3 e Q4 são controlados por 1 - D e D, respectivamente, e o sistema se torna um conversor Boost sincronizado.

Figura X: Bost Síncrono


Fonte: PMP21529

O ciclo de trabalho do modo Boost é calculado conforme a equação a seguir.

D=1-(V_i)/(V_o) | (X)

Onde:

- D=ciclo de trabalho
- V_o =tensão de saída
- V_i =tensão de entrada

Como nesse modo deseja-se aumentar a tensão de entrada, é necessário que esta seja menor que a tensão de saída ( V_i <V_o ). Apenas duas chaves são comutadas, e não é possível operar com V_i =V_o , pois nessas condições D=0 e o comutador Q1 fica ligado junto ao comutador Q3, causando um curto no sistema.

2.3 Buck-Boost Síncrono

A Figura X demonstra esse modo de funcionamento. O comutador Q1 e Q4 são controlados por D, enquanto Q2 e Q3 são controlados por 1 - D, e o sistema se torna um conversor Buck-Boost sincronizado.

Figura X: Buck-Bost Síncrono


Fonte: PMP21529

O ciclo de trabalho do modo Buck-Boost é calculado conforme a equação a seguir.

D=(V_o)/(V_i +V_o) | (X)

Onde:

- D=ciclo de trabalho
- V_o =tensão de saída
- V_i =tensão de entrada

Como nesse modo deseja-se reduzir ou aumentar a tensão de entrada, é possível utilizar durante a condição restrita dos modos anteriores, quando D=1 no modo Buck ou D=0 no modo Boost, pois na condição em que V_i =V_o no modo Buck-Boost, D≈0.5 . As quatros chaves são comutadas, reduzindo a eficiência em troca de operar nas condições restritas.

3. Modo de Operação

Os quatro interruptores alteram o modo de operação de acordo com a tensão de entrada e a tensão de saída, conforme mostrado na Figura X. Para evitar um salto entre as operações e evitar oscilações, uma histerese pode ser adicionada entre a transição dos modos.

Figura X: Modos de Operação com Base nas Tensões


Fonte: PMP21529

Durante a operação Buck, conforme a tensão de entrada diminui, o valor do ciclo de trabalho aproxima-se de 1, conforme a Equação X e o sistema realiza a troca de modo antes dessa ocorrência. O mesmo ocorre durante a operação Boost, conforme a tensão de entrada aumenta, o valor do ciclo de trabalho aproxima-se de 0, conforme a Equação X e o sistema troca de modo antes dessa ocorrência. Portanto, deve-se definir o limiar para a realização de trocas de modo, por exemplo, trocar de Buck para Buck-Boost quando D=0.8 .

4. Implementação

Os comutadores usados nessa aplicação serão MOSFETs. Um tempo de inatividade durante a comutação deve ser considerado para evitar correntes de disparo, evitando, por exemplo, que Q1 e Q2 estejam acionados ao mesmo tempo. Para acionamento dos comutadores, é necessário o uso de gate drives, pois as saídas dos circuitos de controle são de baixa potência, sendo incapazes de realizar o acionamento adequada dos comutaores.

Para o dimensionamento dos componentes em cada modo de operação, utiliza-se as equações a seguir.

4.1 Buck

L>1/(fΔi_L)*(V_o -(V_o^2)/(V_i)) | (X)

Onde:

- L=indutância do indutor
- f=frequência de comutação
- Δi_L =corrente ripple do inductor
- V_o =tensão de saída
- V_i =tensão de entrada

C=(Δi_L)/(8fΔV_o) | (X)

Onde:

- C=capacitância do capacitor
- f=frequência de comutação
- Δi_L =corrente ripple do inductor
- ΔV_o =tensão ripple de saída

4.2 Buck-Boost

L>1/(fΔi_L)*(V_o)/(1+(V_o)/(V_i)) | (X)

Onde:

- L=indutância do indutor
- f=frequência de comutação
- Δi_L =corrente ripple do inductor
- V_o =tensão de saída
- V_i =tensão de entrada

C=(I_o)/(fΔV_o)*(V_o)/(V_o +V_i) | (X)

Onde:

- C=capacitância do capacitor
- f=frequência de comutação
- I_o =corrente de saída
- ΔV_o =tensão ripple de saída
- V_o =tensão de saída
- V_i =tensão de entrada

4.3 Boost

L=1/(fΔi_L)*(V_i -(V_i^2)/(V_o)) | (X)

Onde:

- L=indutância do indutor
- f=frequência de comutação
- Δi_L =corrente ripple do inductor
- V_o =tensão de saída
- V_i =tensão de entrada

C=(I_o)/(fΔV_o)*(V_o -V_i)/(V_o) | (X)

Onde:

- C=capacitância do capacitor
- f=frequência de comutação
- I_o =corrente de saída
- ΔV_o =tensão ripple do capacitor

5. Design

Considerações iniciais:

- V_(i_(min)) =18 V
- V_(i_(max)) =30 V
- D_(min) =0.2
- D_(max) =0.8

A Tabela X a seguir resume o cálculo do ciclo de trabalho para cada modo de operação, para os cálculos das regiões de operação a seguir.

Tabela X: Ciclo de Trabalho por Modo de Operação

Modo de operação | Ciclo de trabalho
Buck | D=1/((V_i)/(V_o))
Buck-boost | D=1/(1+(V_i)/(V_o))
Boost | D=1-(V_i)/(V_o)

5.1 Região Buck

Utilizando a Equação X, calcula-se os valores mínimos e máximos da tensão de saída possíveis nessa região com base no ciclo de trabalho determinado.

D_(min) =1/((V_(i_(max)))/(V_(o_(min))))→V_(o_(min)) =D_(min) V_(i_(max)) =0.2*30=6 V

D_(max) =1/((V_(i_(max)))/(V_(o_(max))))→V_(o_(max)) =D_(max) V_(i_(max)) =0.8*30=24 V

Agora calcula-se uma relação entre entrada e saída que limitam essa região.

(V_(i_(max)))/(V_(o_(max)))<(V_i)/(V_o)<(V_(i_(max)))/(V_(o_(min)))→30/24<(V_i)/(V_o)<30/6→1.25<(V_i)/(V_o)<5

Assim, enquanto a relação estiver entre 1.25 e 5, o modo de operação será Buck.

Considera-se a região esquerda como Buck, central como Buck-Boost e direita como Boost para as definições seguintes.

Quando o limite esquerdo 1.25 é atingido, é possível calcular a tensão de saída mínima V_(o_1) e máxima V_(o_2) de transição com base na tensão de entrada mínima e máxima, determinando a fronteira da região Buck com a região central.

(V_(i_(max)))/(V_(o_(max)))=(V_(i_(min)))/(V_(o_1))→1.25=18/(V_(o_1))→V_(o_1) =18/1.25=14.4 V

(V_(i_(max)))/(V_(o_(max)))=(V_(i_(min)))/(V_(o_2))→1.25=30/(V_(o_2))→V_(o_2) =30/1.25=24 V

Obtém-se que a região Buck opera com tensões de entrada entre 18 e 30 V, e tensões de saída entre 6 e 24 V. A fronteira com a região central consiste em uma reta com tensões de saída entre 14.4 e 24 V.

5.2 Região Boost

Utilizando a Equação X, calcula-se os valores mínimos e máximos da tensão de saída possíveis nessa região com base no ciclo de trabalho determinado.

D_(min) =1-(V_(i_(min)))/(V_(o_(min)))→V_(o_(min)) =(V_(i_(min)))/(1-D_(min))=18/(1-0.2)=22.5 V

D_(max) =1-(V_(i_(max)))/(V_(o_(max)))→V_(o_(max)) =(V_(i_(max)))/(1-D_(max))=30/(1-0.8)=150 V

Agora calcula-se uma relação entre entrada e saída que limitam essa região.

(V_(i_(max)))/(V_(o_(max)))<(V_i)/(V_o)<(V_(i_(min)))/(V_(o_(min)))→30/150<(V_i)/(V_o)<18/22.5→0.2<(V_i)/(V_o)<0.8

Assim, enquanto a relação estiver entre 0.2 e 0.8, o modo de operação será Buck.

Quando o limite direito 0.8 é atingido, é possível calcular a tensão de saída mínima V_(o_1) e máxima V_(o_2) de transição com base na tensão de entrada mínima e máxima, determinando a fronteira da região Boost com a região central.

(V_(i_(max)))/(V_(o_(max)))=(V_(i_(min)))/(V_(o_1))→0.8=18/(V_(o_1))→V_(o_1) =18/0.8=22.5 V

(V_(i_(max)))/(V_(o_(max)))=(V_(i_(min)))/(V_(o_2))→0.8=30/(V_(o_2))→V_(o_2) =30/0.8=37.5 V

Obtém-se que a região Boost opera com tensões de entrada entre 18 e 30 V, e tensões de saída entre 22.5 e 150 V. A fronteira com a região central consiste em uma reta com tensões de saída entre 22.5 e 37.5 V.

5.2 Região Buck-Boost

A região central, é obtida automaticamente ao identificar-se as duas fronteiras. Portanto, obtém-se que a região Buck-Boost opera com tensões de entrada entre 18 e 30 V, e tensões de saída entre 14.4 e 37.5 V.

5.3 Regiões de operação

Novas considerações:

- V_(o_(min)) =6 V
- V_(o_(max)) =55 V

A Tabela X a seguir resume as novas informações obtidas para cada modo de operação.

Tabela X: Região de Operação/Tensão de Operação por Modo de Operação

Modo de operação | Região de operação | Tensão de operação
Buck | (V_i)/(V_o)>1.25 | V_i =[18,30]V_o =[6,24]
Buck-Boost | 0.80≤(V_i)/(V_o)≤1.25 | V_i =[18,30]V_o =[14.4,37.5]
Boost | (V_i)/(V_o)<0.80 | V_i =[18,30]V_o =[22.5,55]

5.3.1 Regiões de operação

A partir das informações obtidas anterioremente, é possível construir o


RegionPlot[

{y/x>1.25,0.8<=y/x<=1.25,y/x<0.8},

{x,6,55},

{y,18,30},

PlotStyle->{Blue,Yellow,Red},

BoundaryStyle->None,

FrameLabel->{"Tensão de Saída","Tensão de Entrada"},

PlotLabel->"Região de Operação",

PlotLegends->{"Buck","Buck-Boost","Boost"}]

Com as regiões limitadas, podemos determinar o valor mínimo e máximo da região de operação, conforme a seguir.

0.2≤(V_i)/(V_o)<0.8∩1.25<(V_i)/(V_o)≤5

0.2≤(V_i)/(V_o)≤5

Sabendo como calcular os valores do ciclo de trabalho para cada região, podemos criar o gráfico que relaciona o ciclo de trabalho com a região de operação, conforme a seguir.


Plot[{

Piecewise[{{1-x,x<0.8},{Indeterminate,True}}],

Piecewise[{{1/(1+x),0.8<=x<=1.25},{Indeterminate,True}}],

Piecewise[{{1/x,x>1.25},{Indeterminate,True}}]},

{x,0.2,5},

PlotStyle->{Red,Yellow,Blue},

AxesLabel->{"Vi/Vo","Duty Cycle"},

PlotLabel->"Duty Cycle por Região de Operação",

PlotLegends->{"Boost","Buck-Boost","Buck"}]

Também podemos calcular o ciclo de trabalho para cada região do gráfico “Região de Operação” e criar um gráfico de temperatura, conforme a seguir.

DensityPlot[

Piecewise[{

{x/y,y/x>1.25},

{x/(x+y),0.8<=y/x<=1.25},

{(x-y)/x,y/x<0.8}}],

{x,6,55},

{y,18,30},

ColorFunction->"TemperatureMap",

PlotLegends->BarLegend[{"TemperatureMap",{0.2,0.80}},

LegendLabel->"Duty Cycle",

Ticks->Range[0,1,0.1]],

FrameLabel->{"Tensão de Saída","Tensão de Entrada"},

PlotLabel->"Região de Operação com Duty Cycle",

RegionFunction->Function[{x,y},6<=x<=55&&18<=y<=30],

PlotPoints->64]

Plot3D[

Piecewise[{

{x/y,y/x>1.25},

{x/(x+y),0.80<=y/x<=1.25},

{(x-y)/x,y/x<0.8}}],

{x,6,55},{y,18,30},

AxesLabel->{"Tensão de Saída","Tensão de Entrada","Duty Cycle"},

ColorFunction->Function[{x,y,z},If[y/x>1.25,Blue,If[0.80<=y/x<=1.25,Yellow,Red]]],ColorFunctionScaling->False,BoxRatios->{1,1,1}]

5.4 Cálculo dos componentes

Output current: I_o =2 A

Switching frequency: f=10 kHz

Inductor current ripple: 0.6 A (30%)

Output voltage ripple: 1 V (2%)

Modo de operação | Tensão de operação
Buck | V_i =[18,30]V_o =[6,24]
Buck-Boost | V_i =[18,30]V_o =[14.4,37.5]
Boost | V_i =[18,30]V_o =[22.5,55]

5.4.1 Buck

L_(max) =1/(fΔi_L)*(V_o -(V_o^2)/(V_i _(max)))=1/(10*10^3 *0.6)*(V_o -(V_o^2)/30)

d/(dV_o)L_(max) =0→V_o =15 V

L_(max) =1/(10*10^3 *0.6)*(15-(15^2)/30)=1.25 mH

Io=2;

f=10*10^3;

Lr=0.6;

Vr=1;

Lmax[Vi_,Vo_]:=1/(f*Lr)(Vo-Vo^2/Vi);

NMaximize[{Lmax[Vi,Vo],18<=Vi<=30,6<=Vo<=24},{Vi,Vo}]

C=(Δi_L)/(8fΔV_o)=0.6/(8*10*10^3 *1)=7.5 uF

5.2 Buck-Boost

L_(max) =1/(fΔi_L)*(V_(o_(max)))/(1+(V_(o_(max)))/(V_i _(max)))=1/(10*10^3 *0.6)*37.5/(1+37.5/30)=2.78 mH

C_(max) =(I_o)/(fΔV_o)*(V_(o_(max)))/(V_(o_(max)) +V_i _(min))=2/(10*10^3 *1)*37.5/(37.5+18)=135.1 uF

5.3 Boost

L_(max) =1/(fΔi_L)*(V_i -(V_i^2)/(V_(o_(max))))=1/(10*10^3 *0.6)*(V_i -(V_i^2)/55)

d/(dV_i)L_(max) =0→V_i =27.5 V

L_(max) =1/(10*10^3 *0.6)*(27.5-(27.5^2)/55)=2.29 mH

Io=2;

f=10*10^3;

Lr=0.6;

Vr=1;

Lmax[Vi_,Vo_]:=1/(f*Lr)*(Vi-Vi^2/Vo);

NMaximize[{Lmax[Vi,Vo],18<=Vi<=30,22.5<=Vo<=55},{Vi,Vo}]

C_(max) =(I_o)/(fΔV_o)*(V_(o_(max)) -V_i _(min))/(V_(o_(max)))=2/(10*10^3 *1)*(55-18)/55=134.5 uF

5.4 Verification

L=2.78 mH

C=135.1 uF

5.4.1 Buck

2.78*10^(-3) =1/(10*10^3 *Δi_L)*(15-(15^2)/30)→Δi_L =0.27 A

135.1*10^(-6) =0.27/(8*10*10^3 *ΔV_o)→ΔV_o =0.025 V

5.4.2 Buck-Boost

2.78*10^(-3) =1/(10*10^3 *Δi_L)*37.5/(1+37.5/30)→Δi_L =0.6 A

135.1*10^(-6) =2/(10*10^3 *ΔV_o)*37.5/(37.5+18)→ΔV_o =1 V

5.4.2 Boost

2.78*10^(-3) =1/(10*10^3 *Δi_L)*(27.5-(27.5^2)/55)→Δi_L =0.49 A

135.1*10^(-6) =2/(10*10^3 *ΔV_o)*(55-18)/55→ΔV_o =1 V

Modo de operação | Faixa de operação (V) | Duty Cycle | Vi/Vo | Δi_L _(max) (A) | ΔV_o _(max) (V)
Buck | V_i =[18,30]V_o =[6,24] | D=[0.2,0.8] | 0.2≤(V_i)/(V_o)<0.8 | 0.27 | 0.025
Buck-Boost | V_i =[18,30]V_o =[14.4,37.5] | D=[0.4,0.5] | 0.8≤(V_i)/(V_o)≤1.25 | 0.6 | 1
Boost | V_i =[18,30]V_o =[22.5,55] | D=[0.2,0.8] | 1.25<(V_i)/(V_o)≤5 | 0.49 | 1

5.5 Simulink implementation

O circuito base do conversor é implementado no Simulink em um subsistema conforme abaixo.


O subsistema possui 2 entradas, sendo elas: Source Signal (SS) e SW ( 4 Switches multiplexados). E 4 saídas, sendo elas: Output Voltage (OV), Output Current (OC), Inductor Voltage (v_L) e Inductor Current (i_L).

Os 4 modos de funcionamento dependem do estado dos 4 Switches e do seu Duty Cycle respectivo. Como temos 4 modos diferentes, precisamos de 2 bits para representar os modos. A tabela abaixo resume a lógica da ativação de cada Switch usando A e B como entradas lógicas.

Mode | AB | SW1 | SW2 | SW3 | SW4
Buck | 00 | D | 1 - D | 1 | 0
Buck-boost | 01 | D | 1 - D | 1 - D | D
Boost | 11 | 1 | 0 | 1 - D | D
Off | 10 | 0 | 0 | 0 | 0

Usando conhecimentos de sistemas digitais, podemos simplificar a relação para cada Switch, chegando nas equações abaixo.

SW1=AD+AB

SW2=AD

SW3=AB+BD

SW4=BD

A partir das relações acima, podemos implementar no Simulink um subsistema para aplicar o funcionamento de cada Switch a partir das entradas A, B e D.


O modo de funcionamento atual e futuro do sistema é definido a partir da relação entre Tensão de Entrada e Tensão de Referência, conforme a tabela abaixo.

Modo de operação | Vi/Vo
Buck | 1.25<(V_i)/(V_o)≤5
Buck-Boost | 0.8≤(V_i)/(V_o)≤1.25
Boost | 0.2≤(V_i)/(V_o)<0.8

A tabela indica que, enquanto a Tensão de Entrada estiver acima de 125% da Tensão de Referência, o modo de funcionamento será Buck. E, enquanto a Tensão de Entrada estiver abaixo de 80% da Tensão de Referência, o modo de funcionamento será Boost.

Podemos escrever essa relação conforme abaixo.

X=(V_i)/(V_o)>1.25

Y=(V_i)/(V_o)>0.8

A tabela abaixo resume a lógica do modo de funcionamento acima.

XY | Buck | Buck-Boost | Boost
00 | 0 | 0 | 1
01 | 0 | 1 | 0
11 | 1 | 0 | 0
10 | X | X | X

Usando conhecimentos de sistemas digitais, podemos simplificar a relação, chegando nas equações abaixo.

Buck=X

Buck-Boost=XY

Boost=Y

A lógica acima pode ser implementada no Simulink usando o subsistema a seguir.

Agora que temos definido qual modo será ativado, precisamos do cálculo do Duty Cycle. Cada modo terá seu Duty Cycle calculado, porém somente aquele ativado no momento será usado no funcionamento dos Switches. Conforme vimos anteriormente, para o cálculo precisamos somente da Tensão de Entrada e Tensão de Referência, conforme a seguir.


O valor de A e B, escolhido anteriormente conforme a tabela abaixo, também é anexado junto ao seu respectivo D pelo MUX.

Mode | AB
Buck | 00
Buck-boost | 01
Boost | 11

Para definir qual valor será utilizado, usamos o resultado do subsistema anterior juntamente com comparadores lógicos para levar o valor até as variáveis A, B e D pelo DEMUX, conforme abaixo.


Como somente um dos comparadores estará ativo por vez, A e B pode ser calculado com uma porta OR enquanto D pode ser calculado como uma soma simples, conforme abaixo.


Por fim, para propósitos de controle, podemos somar a variável D com uma entrada externa (D_FIS). Também, como definido anteriormente, o Duty Cycle é saturado entre 0.2 e 0.8.

Assim, obtemos nosso subsistema responsável por determinar a variável D do sistema.

Com as variáveis A, B e D determinadas, o funcionamento dos Switches também estão determinados e, portanto, o sistema está pronto para funcionamento em malha aberta.

Para visualizar o erro e sua variação precisamos de um subsistema. O erro pode ser definido pelo quão distante está a Tensão de Saída da Tensão de Referência e a variação do erro pode ser definida pela diferença entre o erro atual e anterior, assumindo o uso de valores discretos. Para facilitar a visualização do desempenho, vamos empregar um erro normalizado, conforme abaixo.

E[n]=(V_o -V_r)/(|V_o -V_r |+1)

dE[n]=E[n]-E[n-1]

O subsistema aplicado no Simulink pode ser visualizado abaixo.


O resultado final do sistema em malha aberta e visualização do erro a partir da união dos subsistemas, pode ser visualizado abaixo.


Agora fazemos uma simulação que pegue todos as possíveis combinações de tensão de entrada e saída a seguir.

A tensão de entrada (SS) consistirá em duas rampas definidas pela função abaixo.

SS(t)=|12-6t|+18


O sinal de referência (RS) consistirá em duas rampas definidas pela função abaixo.

RS(t)=55-|49-24.5t|

O sistema será simulado durante 4 segundos.


Podemos identificar facilmente os pontos de transição do modo de operação pela falta de histerese. Também se observa um erro na tensão de saída (vermelho) pela falta de um compensador.

Nota-se uma taxa de variação inicial do erro (magenta) por causa da ativação do sistema até sua operação em estado estacionário, e outras variações durante a troca de operação. O erro (vermelho) indica que o sistema não atinge e fica abaixo da tensão de referência durante seu funcionamento pela falta de um compensador.


A corrente do indutor ficou abaixo de 6 A, não levando em consideração o ripple de 0.6 A. A corrente de saída permaneceu abaixo 2 A.


O valor do Duty Cycle obedece ao cálculo do modo de operação e se mantém no range designado anteriormente de 0.2 a 0.8. O valor do controle segue os mesmos valores pois não há um compensador implementado.

5.5.1 Controle

Usaremos um Fuzzy Inference System (FIS) como compensador e corrigir o erro do sistema. Sabemos que o comportamento do sistema depende do Duty Cycle, então iremos compensar esse valor e usá-la como variável manipulada.

A partir do subsistema de erro, temos que ele varia entre -1 e 1. Um erro negativo indica que a Tensão de Saída (variável controlada) está abaixo da Tensão de Referência e precisamos de uma compensação positiva no Duty Cycle, enquanto um erro positivo indica estar acima e precisamos de uma compensação negativa.

Com as informações anteriores, podemos criar um FIS com uma entrada, denominada Error, e uma saída, denominada Mode. Para determinar os pesos das entradas usaremos uma função membro em formato Z para erros negativos e uma função membro em formato S para erros positivos, conforme a abaixo.

Para determinar o ajuste na saída, usaremos uma função membro em formato de sino para saídas negativas e saídas positivas, conforme abaixo.


Com isso, obtemos uma superfície que descreve o comportamento do FIS.


Observando o gráfico acima, percebemos que erros próximos de 0 terão poucos ajustes, enquanto erros próximos de -0.5 e 0.5 terão seus ajustes máximos. Isso reflete o erro normalizado, que cresce muito quando se afaste de 0.

Agora criaremos uma tabela verdade que irá servir de consulta para determinar a saída com base na superfície anterior, a tabela verdade terá 32 pontos.

Com isso podemos criar o subsistema de controle que aplica a tabela verdade para compensar o Duty Cycle no sistema, conforme a seguir.


Para evitar ajustes instantâneos no sistema e instabilidade, adicionamos um integrador discreto que leva até o ponto de ajuste de forma suave. Também um saturador é utilizado para evitar acúmulo de esforço no integrador.

Por fim, temos o sistema completo no Simulink, conforme abaixo.

A simulação seguirá as mesmas condições anteriores, porém com a adição do controlador.


Podemos identificar facilmente os pontos de transição do modo de operação pela falta de histerese. Também se observa que a saída acompanhou a tensão de referência.

Nota-se uma taxa de variação inicial do erro (magenta) por causa da ativação do sistema até sua operação em estado estacionário, e outras variações durante a troca de operação. O erro (vermelho) indica que a saída do sistema fica próximo da tensão de referência, porém não exatamente 0, considerando o uso de um erro normalizado.


A corrente do indutor ficou abaixo de 8 A, não levando em consideração o ripple de 0.6 A. A corrente de saída permaneceu abaixo 2 A. Ou seja, pela ação do compensador houve um aumento na corrente de entrada.


O valor do Duty Cycle obedece ao cálculo do modo de operação e se mantém no range designado anteriormente de 0.2 a 0.8. O valor do controlado foi compensado, principalmente na parte com modo de operação Buck-Boost.

Com isso observamos que para realizar a correção houve um aumento na corrente de entrada, que deverá ser levado em conta no projeto.

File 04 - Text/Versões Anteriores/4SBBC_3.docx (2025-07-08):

1. Configuração básica de um conversor Buck-Boost

O conversor DC-DC Buck-Boost, conforme a Figura X, é um tipo de conversor de potência que pode produzir uma tensão de saída maior ou menor que a tensão de entrada.

Figura X: Esquemático do Conversor Buck-Boost

Fonte: SLVA535B

Ele é composto pelos seguintes componentes principais:

- SW 1, SW 2, SW 3, SW 4: quatro comutadores, geralmente implementadas com MOSFETs. O chaveamento controlado dessas chaves determina o aumento ou redução da tensão.
- L: indutor responsável por armazenar a energia e realizar sua transferência a partir do funcionamento dos comutadores.
- CIN: capacitor de entrada para filtrar oscilações e fornecer uma tensão mais estável para o conversor.
- COUT: capacitor de saída para suavizar oscilações e fornecer uma tensão de saída mais estável para a carga.

2. Princípio de Operação

Ciclo de Trabalho é a fração de tempo em que um sinal ou uma chave está ligado dentro de um período fixo.

D=(T_(on))/T | (X)

Onde:

- D=ciclo de trabalho
- T_(on) =tempo que o sinal está ligado
- T=período do sinal

Ciclo de Trabalho Complementar é a fração de tempo em que o mesmo sinal está desligado dentro do mesmo período fixo.

1-D=(T_(off))/T | (X)

Onde:

- D=ciclo de trabalho complementar
- T_(off) =tempo que o sinal está desligado
- T=período do sinal

A Figura X descreve graficamente esse conceito e será útil futuramente, pois o ciclo de trabalho e seu complementar será necessário durante a aplicação do conversor.

Figura X: Ciclo de Trabalho Complementar


Fonte: Autor (Mathematica)

2.1 Buck Síncrono

A Figura X demonstra esse modo de funcionamento. O comutador Q3 é totalmente ligado e o comutador Q4 é totalmente desligado. Q1 e Q2 são controlados por D e 1 - D, respectivamente, e o sistema se torna um conversor Buck sincronizado.

Figura X: Buck Síncrono

Fonte: PMP21529

O ciclo de trabalho do modo Buck é calculado conforme a equação a seguir.

D=(V_o)/(V_i) | (X)

Onde:

- D=ciclo de trabalho
- V_o =tensão de saída
- V_i =tensão de entrada

Como nesse modo deseja-se reduzir a tensão de entrada, é necessário que esta seja maior que a tensão de saída ( V_i >V_o ). Apenas duas chaves são comutadas, e não é possível operar com V_i =V_o , pois nessas condições D=1 e o comutador Q1 fica ligado junto ao comutador Q3, causando um curto no sistema.

2.2 Boost Síncrono

A Figura X demonstra esse modo de funcionamento. O comutador Q1 é totalmente ligado e o comutador Q2 é totalmente desligado. Q3 e Q4 são controlados por 1 - D e D, respectivamente, e o sistema se torna um conversor Boost sincronizado.

Figura X: Bost Síncrono


Fonte: PMP21529

O ciclo de trabalho do modo Boost é calculado conforme a equação a seguir.

D=1-(V_i)/(V_o) | (X)

Onde:

- D=ciclo de trabalho
- V_o =tensão de saída
- V_i =tensão de entrada

Como nesse modo deseja-se aumentar a tensão de entrada, é necessário que esta seja menor que a tensão de saída ( V_i <V_o ). Apenas duas chaves são comutadas, e não é possível operar com V_i =V_o , pois nessas condições D=0 e o comutador Q1 fica ligado junto ao comutador Q3, causando um curto no sistema.

2.3 Buck-Boost Síncrono

A Figura X demonstra esse modo de funcionamento. O comutador Q1 e Q4 são controlados por D, enquanto Q2 e Q3 são controlados por 1 - D, e o sistema se torna um conversor Buck-Boost sincronizado.

Figura X: Buck-Bost Síncrono


Fonte: PMP21529

O ciclo de trabalho do modo Buck-Boost é calculado conforme a equação a seguir.

D=(V_o)/(V_i +V_o) | (X)

Onde:

- D=ciclo de trabalho
- V_o =tensão de saída
- V_i =tensão de entrada

Como nesse modo deseja-se reduzir ou aumentar a tensão de entrada, é possível utilizar durante a condição restrita dos modos anteriores, quando D=1 no modo Buck ou D=0 no modo Boost, pois na condição em que V_i =V_o no modo Buck-Boost, D≈0.5 . As quatros chaves são comutadas, reduzindo a eficiência em troca de operar nas condições restritas.

3. Modo de Operação

Os quatro interruptores alteram o modo de operação de acordo com a tensão de entrada e a tensão de saída, conforme mostrado na Figura X. Para evitar um salto entre as operações e evitar oscilações, uma histerese pode ser adicionada entre a transição dos modos.

Figura X: Modos de Operação com Base nas Tensões


Fonte: PMP21529

Durante a operação Buck, conforme a tensão de entrada diminui, o valor do ciclo de trabalho aproxima-se de 1, conforme a Equação X e o sistema realiza a troca de modo antes dessa ocorrência. O mesmo ocorre durante a operação Boost, conforme a tensão de entrada aumenta, o valor do ciclo de trabalho aproxima-se de 0, conforme a Equação X e o sistema troca de modo antes dessa ocorrência. Portanto, deve-se definir o limiar para a realização de trocas de modo, por exemplo, trocar de Buck para Buck-Boost quando D=0.8 .

4. Implementação

Os comutadores usados nessa aplicação serão MOSFETs. Um tempo de inatividade durante a comutação deve ser considerado para evitar correntes de disparo, evitando, por exemplo, que Q1 e Q2 estejam acionados ao mesmo tempo. Para acionamento dos comutadores, é necessário o uso de gate drives, pois as saídas dos circuitos de controle são de baixa potência, sendo incapazes de realizar o acionamento adequada dos comutaores.

Para o dimensionamento dos componentes em cada modo de operação, utiliza-se as equações a seguir.

4.1 Buck

L>1/(fΔi_L)*(V_o -(V_o^2)/(V_i)) | (X)

Onde:

- L=indutância do indutor
- f=frequência de comutação
- Δi_L =corrente ripple do inductor
- V_o =tensão de saída
- V_i =tensão de entrada

C>(Δi_L)/(8fΔV_o) | (X)

Onde:

- C=capacitância do capacitor
- f=frequência de comutação
- Δi_L =corrente ripple do inductor
- ΔV_o =tensão ripple de saída

4.2 Buck-Boost

L>1/(fΔi_L)*(V_o)/(1+(V_o)/(V_i)) | (X)

Onde:

- L=indutância do indutor
- f=frequência de comutação
- Δi_L =corrente ripple do inductor
- V_o =tensão de saída
- V_i =tensão de entrada

C>(I_o)/(fΔV_o)*(V_o)/(V_o +V_i) | (X)

Onde:

- C=capacitância do capacitor
- f=frequência de comutação
- I_o =corrente de saída
- ΔV_o =tensão ripple de saída
- V_o =tensão de saída
- V_i =tensão de entrada

4.3 Boost

L>1/(fΔi_L)*(V_i -(V_i^2)/(V_o)) | (X)

Onde:

- L=indutância do indutor
- f=frequência de comutação
- Δi_L =corrente ripple do inductor
- V_o =tensão de saída
- V_i =tensão de entrada

C>(I_o)/(fΔV_o)*(V_o -V_i)/(V_o) | (X)

Onde:

- C=capacitância do capacitor
- f=frequência de comutação
- I_o =corrente de saída
- ΔV_o =tensão ripple do capacitor

5. Design

Considerações iniciais:

- V_(i_(min)) =18 V
- V_(i_(max)) =30 V
- D_(min) =0.2
- D_(max) =0.8

A Tabela X a seguir resume o cálculo do ciclo de trabalho para cada modo de operação, para os cálculos das regiões de operação a seguir.

Tabela X: Resumo do Ciclo de Trabalho por Modo de Operação

Modo de operação | Ciclo de trabalho
Buck | D=1/((V_i)/(V_o))
Buck-boost | D=1/(1+(V_i)/(V_o))
Boost | D=1-(V_i)/(V_o)

5.1 Região Buck

Utilizando a Equação X, calcula-se os valores mínimos e máximos da tensão de saída possíveis nessa região com base no ciclo de trabalho determinado.

D_(min) =1/((V_(i_(max)))/(V_(o_(min))))→V_(o_(min)) =D_(min) V_(i_(max)) =0.2*30=6 V

D_(max) =1/((V_(i_(max)))/(V_(o_(max))))→V_(o_(max)) =D_(max) V_(i_(max)) =0.8*30=24 V

Agora calcula-se uma relação entre entrada e saída que limitam essa região.

(V_(i_(max)))/(V_(o_(max)))<(V_i)/(V_o)<(V_(i_(max)))/(V_(o_(min)))→30/24<(V_i)/(V_o)<30/6→1.25<(V_i)/(V_o)<5

Assim, enquanto a relação estiver entre 1.25 e 5, o modo de operação será Buck.

Considera-se a região esquerda como Buck, central como Buck-Boost e direita como Boost para as definições seguintes.

Quando o limite esquerdo 1.25 é atingido, é possível calcular a tensão de saída mínima V_(o_1) e máxima V_(o_2) de transição com base na tensão de entrada mínima e máxima, determinando a fronteira da região Buck com a região central.

(V_(i_(max)))/(V_(o_(max)))=(V_(i_(min)))/(V_(o_1))→1.25=18/(V_(o_1))→V_(o_1) =18/1.25=14.4 V

(V_(i_(max)))/(V_(o_(max)))=(V_(i_(min)))/(V_(o_2))→1.25=30/(V_(o_2))→V_(o_2) =30/1.25=24 V

Obtém-se que a região Buck opera com tensões de entrada entre 18 e 30 V, e tensões de saída entre 6 e 24 V. A fronteira com a região central consiste em uma reta com tensões de saída entre 14.4 e 24 V.

5.2 Região Boost

Utilizando a Equação X, calcula-se os valores mínimos e máximos da tensão de saída possíveis nessa região com base no ciclo de trabalho determinado.

D_(min) =1-(V_(i_(min)))/(V_(o_(min)))→V_(o_(min)) =(V_(i_(min)))/(1-D_(min))=18/(1-0.2)=22.5 V

D_(max) =1-(V_(i_(max)))/(V_(o_(max)))→V_(o_(max)) =(V_(i_(max)))/(1-D_(max))=30/(1-0.8)=150 V

Agora calcula-se uma relação entre entrada e saída que limitam essa região.

(V_(i_(max)))/(V_(o_(max)))<(V_i)/(V_o)<(V_(i_(min)))/(V_(o_(min)))→30/150<(V_i)/(V_o)<18/22.5→0.2<(V_i)/(V_o)<0.8

Assim, enquanto a relação estiver entre 0.2 e 0.8, o modo de operação será Buck.

Quando o limite direito 0.8 é atingido, é possível calcular a tensão de saída mínima V_(o_1) e máxima V_(o_2) de transição com base na tensão de entrada mínima e máxima, determinando a fronteira da região Boost com a região central.

(V_(i_(max)))/(V_(o_(max)))=(V_(i_(min)))/(V_(o_1))→0.8=18/(V_(o_1))→V_(o_1) =18/0.8=22.5 V

(V_(i_(max)))/(V_(o_(max)))=(V_(i_(min)))/(V_(o_2))→0.8=30/(V_(o_2))→V_(o_2) =30/0.8=37.5 V

Obtém-se que a região Boost opera com tensões de entrada entre 18 e 30 V, e tensões de saída entre 22.5 e 150 V. A fronteira com a região central consiste em uma reta com tensões de saída entre 22.5 e 37.5 V.

5.2 Região Buck-Boost

A região central, é obtida automaticamente ao identificar-se as duas fronteiras. Portanto, obtém-se que a região Buck-Boost opera com tensões de entrada entre 18 e 30 V, e tensões de saída entre 14.4 e 37.5 V.

5.3 Regiões de operação

Novas considerações:

- V_(o_(min)) =6 V
- V_(o_(max)) =55 V

A Tabela X a seguir resume as novas informações obtidas para cada modo de operação.

Tabela X: Resumo da Região de Operação/Tensão de Operação por Modo de Operação

Modo de operação | Região de operação | Tensão de operação
Buck | (V_i)/(V_o)>1.25 | V_i =[18,30]V_o =[6,24]
Buck-Boost | 0.80≤(V_i)/(V_o)≤1.25 | V_i =[18,30]V_o =[14.4,37.5]
Boost | (V_i)/(V_o)<0.80 | V_i =[18,30]V_o =[22.5,55]

5.3.1 Regiões de operação

A partir das informações obtidas anteriormente, é possível calcular o ciclo de trabalho para cada combinação de entradas e saídas, e construir um gráfico de contorno que representa as regiões de operação, facilitando a visualização das fronteiras entre elas, conforme a Figura X.

Figura X: Gráfico de Contorno das Regiões de Operação

Fonte: Autor (Mathematica)

Para visualizar a profundidade, pode-se converter os eixos em uma variável única que represente tensão de entrada sobre tensão de saída no eixo horizontal e representar o Duty Cycle no eixo vertical, conforme a Figura X.

Figura X: Gráfico do Duty Cycle por Região de Operação


Fonte: Autor (Mathematica)

Vale comentar que, pela tensão máxima ter sido considerada 55 V, o valor de Duty Cycle teórico não atinge o valor de 0.8 na região Boost.

5.4 Cálculo dos Componentes

Novas considerações:

- I_(o_(max)) =2 A
- f=10 kHz
- Δi_(L_(max)) =0.6 A (30%)
- ΔV_(o_(max)) =1 V (2%)

5.4.1 Buck

A partir das Equações X e Y.

L>1/(fΔi_L)*(V_o -(V_o^2)/(V_i _(max)))>1/(10*10^3 *0.6)*(V_o -(V_o^2)/30)

d/(dV_o)L=0→V_o =15 V

L>1/(10*10^3 *0.6)*(15-(15^2)/30)>1.25 mH

C>(Δi_L)/(8fΔV_o)>0.6/(8*10*10^3 *1)>7.5 uF

5.2 Buck-Boost

A partir das Equações X e Y.

L>1/(fΔi_L)*(V_(o_(max)))/(1+(V_(o_(max)))/(V_i _(max)))>1/(10*10^3 *0.6)*37.5/(1+37.5/30)>2.78 mH

C>(I_o)/(fΔV_o)*(V_(o_(max)))/(V_(o_(max)) +V_i _(min))>2/(10*10^3 *1)*37.5/(37.5+18)>135.1 uF

5.3 Boost

A partir das Equações X e Y.

L>1/(fΔi_L)*(V_i -(V_i^2)/(V_(o_(max))))>1/(10*10^3 *0.6)*(V_i -(V_i^2)/55)

d/(dV_i)L=0→V_i =27.5 V

L>1/(10*10^3 *0.6)*(27.5-(27.5^2)/55)>2.29 mH

C>(I_o)/(fΔV_o)*(V_(o_(max)) -V_i _(min))/(V_(o_(max)))>2/(10*10^3 *1)*(55-18)/55>134.5 uF

5.4 Verficação

Com os componentes de cada modo de operação obtidos, utiliza-se aqueles com o maior valor para cobrir todo o funcionamento do sistema.

Novas considerações:

- L>2.78 mH
- C>135.1 uF

Calcula-se o ripple máximo da corrente do indutor e da tensão de saída com base nas equações anteriores.

5.4.1 Buck

2.78*10^(-3) =1/(10*10^3 *Δi_L)*(15-(15^2)/30)→Δi_(L_(max)) =0.27 A

135.1*10^(-6) =0.27/(8*10*10^3 *ΔV_o)→ΔV_(o_(max)) =0.025 V

5.4.2 Buck-Boost

2.78*10^(-3) =1/(10*10^3 *Δi_L)*37.5/(1+37.5/30)→Δi_(L_(max)) =0.6 A

135.1*10^(-6) =2/(10*10^3 *ΔV_o)*37.5/(37.5+18)→ΔV_(o_(max)) =1 V

5.4.2 Boost

2.78*10^(-3) =1/(10*10^3 *Δi_L)*(27.5-(27.5^2)/55)→Δi_(L_(max)) =0.49 A

135.1*10^(-6) =2/(10*10^3 *ΔV_o)*(55-18)/55→ΔV_(o_(max)) =1 V

Por fim, verificou-se que os valores estão dentro do considerado para esse design.

5.4.3 Resumo Final

As informações adquiridas do design até o momento são resumidas na Tabela X a seguir.

Tabela X: Gráfico do Duty Cycle por Região de Operação

Modo de operação | Faixa de operação (V) | Duty Cycle | Vi/Vo | Δi_L _(max) (A) | ΔV_o _(max) (V)
Buck | V_i =[18,30]V_o =[6,24] | D=[0.2,0.8] | 0.2≤(V_i)/(V_o)<0.8 | 0.27 | 0.025
Buck-Boost | V_i =[18,30]V_o =[14.4,37.5] | D=[0.4,0.5] | 0.8≤(V_i)/(V_o)≤1.25 | 0.6 | 1
Boost | V_i =[18,30]V_o =[22.5,55] | D=[0.2,0.8] | 1.25<(V_i)/(V_o)≤5 | 0.49 | 1

5.5 Implementação Simulink

O circuito base do conversor foi implementado em um subsistema no Simulink, conforme ilustrado na Figura X.

Figura X: Subsistema do Conversor Buck-Boost Implementada


Fonte: Autor (Simulink)

O subsistema possui duas entradas: o sinal de fonte (Source Signal - SS) e as quatro chaves multiplexadas (SW). Suas quatro saídas são: Tensão de Saída (Output Voltage - OV), Corrente de Saída (Output Current - OC), Tensão do Indutor (Inductor Voltage - v_L) e Corrente do Indutor (Inductor Current - i_L). Os quatro modos de funcionamento do conversor são definidos pelo estado das quatro chaves e seus respectivos ciclos de trabalho (Duty Cycle). Uma vez que existem quatro modos distintos, são necessários dois bits para representá-los. A Tabela X, a seguir, sumariza a lógica de ativação de cada chave, utilizando A e B como entradas lógicas.

Tabela X: Lógica de Ativação dos Switches

Mode | AB | SW1 | SW2 | SW3 | SW4
Buck | 00 | D | 1 - D | 1 | 0
Buck-boost | 01 | D | 1 - D | 1 - D | D
Boost | 11 | 1 | 0 | 1 - D | D
Off | 10 | 0 | 0 | 0 | 0

Com base nos princípios de sistemas digitais, é possível simplificar a lógica de acionamento de cada chave, resultando nas equações apresentadas a seguir.

SW1=AD+AB SW2=AD SW3=AB+BD SW4=BD | (X)

Onde:

- SWx=lógica de ativação do switch
- A=entrada lógica
- B=entrada lógica
- D=saída do PWM
- D=saída complementar do PWM

Com base nas relações apresentadas, é possível implementar um subsistema no Simulink para controlar o funcionamento de cada chave, utilizando as entradas A, B e D, conforme a Figura X.

Figura X: Subsistema de Ativação dos Switches Implementada


Fonte: Autor (Simulink)

O modo de operação, tanto o atual quanto o futuro, é determinado pela relação entre a Tensão de Entrada e a Tensão de Referência. Essa relação é detalhada na Tabela X a seguir.

Tabela X: Lógica do Modo de Operação

Modo de operação | Vi/Vo
Buck | 1.25<(V_i)/(V_o)≤5
Buck-Boost | 0.8≤(V_i)/(V_o)≤1.25
Boost | 0.2≤(V_i)/(V_o)<0.8

A Tabela X indica que o modo de funcionamento será Buck quando a Tensão de Entrada exceder 125% da Tensão de Referência. Por outro lado, o modo de funcionamento será Boost quando a Tensão de Entrada estiver abaixo de 80% da Tensão de Referência. Essa relação pode ser expressa conforme a equação lógica abaixo.

X=(V_i)/(V_o)>1.25 Y=(V_i)/(V_o)>0.8 | (X)

Onde:

- X,Y=saída lógica do modo de operação
- V_i =tensão de entrada
- V_o =tensão de saída

A Tabela X, a seguir, sumariza a lógica dos modos de funcionamento conforme as saídas lógicas da Equação X.

Tabela X: Lógica de Escolha dos Modos de Operação

XY | Buck | Buck-Boost | Boost
00 | 0 | 0 | 1
01 | 0 | 1 | 0
11 | 1 | 0 | 0
10 | X | X | X

Com a aplicação de conceitos de sistemas digitais, é possível simplificar essa relação, resultando nas equações lógicas apresentadas a seguir.

Buck=X Buck-Boost=XY Boost=Y | (X)

A lógica descrita pode ser implementada no Simulink por meio do subsistema ilustrado na Figura X.

Figura X: Subsistema de Escolha de Modos Implementada

Fonte: Autor (Simulink)

Com a determinação do modo de operação, o próximo passo é o cálculo do Ciclo de Trabalho (Duty Cycle). Embora cada modo possua seu Duty Cycle calculado, apenas o valor correspondente ao modo ativo será empregado no acionamento das chaves. Conforme previamente estabelecido nas Equações X, Y e Z, o cálculo requer apenas a Tensão de Entrada e a Tensão de Referência, conforme a Figura X.

Figura X: Equações do Ciclo de Trabalho Implementada


Fonte: Autor (Simulink)

Os valores de A e B, previamente definidos na Tabela X, são anexados juntamente ao respectivo valor de D por meio de um multiplexador (MUX). Para determinar qual valor será utilizado, o resultado do subsistema anterior é empregado em conjunto com comparadores lógicos, direcionando o valor para as variáveis A, B e D através de um demultiplexador (DEMUX), conforme ilustrado abaixo.

Figura X: Direcionamento dos Valores A, B e D Implementada


Fonte: Autor (Simulink)

Dado que apenas um dos comparadores estará ativo em determinado momento, A e B podem ser calculados por meio de uma porta OR, enquanto D pode ser obtido por uma soma simples, conforme a Figura X

Figura X: Valor Final de A e B Implementada

Fonte: Autor (Simulink)

Para fins de controle, a variável D pode ser somada a uma entrada externa (D_FIS), conforme a Figura X. Adicionalmente, o ciclo de trabalho (Duty Cycle) é limitado entre 0.2 e 0.8.

Figura X: Valor Final de D Implementada

Fonte: Autor (Simulink)

Desse modo, conforme ilustrado na Figura X, obtém-se o subsistema responsável pela determinação da variável D do sistema.

Figura X: Subsistema Final para o Cálculo do Ciclo de Trabalho Implementada


Fonte: Autor (Simulink)

Com as variáveis A, B e D devidamente determinadas, o funcionamento das chaves (Switches) também é definido, tornando o sistema apto para operação em malha aberta.

Para a visualização do erro e de sua variação, é necessário um subsistema. O erro pode ser caracterizado pela diferença entre a Tensão de Saída e a Tensão de Referência, e sua variação, pela diferença entre o erro atual e o anterior, considerando o uso de valores discretos. Para otimizar a visualização do desempenho, será empregado um erro normalizado, conforme as equações a seguir.

E[n]=(V_o -V_r)/(|V_o -V_r |+1) | (X)
dE[n]=E[n]-E[n-1] | (X)

Onde:

- E[n]=erro atual
- V_o =tensão de saída atual
- V_r =tensão de referência atual
- dE[n]=variação do erro
- E[n-1]=erro anterior

O subsistema implementado no Simulink pode ser visualizado na Figura X abaixo.

Figura X: Subsistema do Erro Normalizado Implementado


Fonte: Autor (Simulink)

O resultado final do sistema em malha aberta, bem como a visualização do erro obtida a partir da união dos subsistemas, pode ser observado na Figura X.

Figura X: Sistema em Malha Aberta Implementado


Fonte: Autor (Simulink)

Agora é possível realizar uma simulação contemplando todas as combinações possíveis de tensão de entrada e saída, descritas a seguir.

A tensão de entrada (SS), conforme a Figura X, consistirá em duas rampas definidas pela Equação X abaixo.

SS(t)=|12-6t|+18 | (X)

Onde:

- SS=tensão de entrada
- t=tempo em segundos

Figura X: Gráfico da Tensão de Entrada (SS)

Fonte: Autor (Simulink)

O sinal de referência (RS) consistirá em duas rampas definidas pela Equação X abaixo.

RS(t)=55-|49-24.5t| | (X)

Onde:

- RS=tensão de referência
- t=tempo em segundos

Figura X: Gráfico da Tensão de Referência (RS)


Fonte: Autor (Simulink)

5.5.1 Simulação em Malha Aberta Simulink

A simulação do sistema teve uma duração total de 4 segundos.

A Figura X ilustra a curva dos sinais Source Signal (SS) em amarelo, Reference Signal (RS) em verde e Output Voltage (OV) em vermelho para comparação, resultante do sistema em malha aberta.

Figura X: Gráfico Resultante da Tensão de Saída do Sistema em Malha Aberta


Fonte: Autor (Simulink)

É possível identificar facilmente os pontos de transição do modo de operação, dada a ausência de histerese. Também se observa um erro na tensão de saída (representada em vermelho), atribuível à falta de um compensador.

A Figura X ilustra a curva dos sinais do Erro em vermelho e Variação do Erro em magenta, resultante do sistema em malha aberta.

Figura X: Gráfico Resultante do Erro e Variação do Erro do Sistema em Malha Aberta


Fonte: Autor (Simulink)

É perceptível uma taxa de variação inicial do erro (na cor magenta) provocada pela energização do sistema até sua entrada em regime estacionário, e subsequentes variações durante as alternâncias de modo de operação. O erro (na cor vermelha) sinaliza que o sistema não atinge e opera abaixo da tensão de referência, justificando-se tal comportamento pela ausência de um compensador.

A Figura X ilustra a curva dos sinais Inductor Current (IC) em ciano e Output Current (OC) em vermelho, resultante do sistema em malha aberta.

Figura X: Gráfico Resultante da Corrente de Saída do Sistema em Malha Aberta

Fonte: Autor (Simulink)

A corrente do indutor manteve-se abaixo de 6 A, sem considerar o ripple de 0.6 A. A corrente de saída, por sua vez, permaneceu inferior a 2 A.

A Figura X ilustra a curva dos sinais do Ciclo de Trabalho em verde e Ciclo de Trabalho Compensado em vermelho, resultante do sistema em malha aberta.

Figura X: Gráfico Resultante do Ciclo de Trabalho do Sistema em Malha Aberta


Fonte: Autor (Simulink)

O valor do ciclo de trabalho (Duty Cycle) está em conformidade com o cálculo do modo de operação e se mantém dentro da faixa previamente estabelecida de 0.2 a 0.8. O valor de controle, por sua vez, acompanha esses mesmos valores devido à ausência de um compensador que será implementado a seguir.

5.5.2 Controle

Um Sistema de Inferência Fuzzy (FIS) será empregado no MATLAB como compensador para corrigir o erro do sistema. Sabendo que o comportamento do sistema é dependente do Ciclo de Trabalho (Duty Cycle), este valor será compensado e utilizado como variável manipulada.

A partir do subsistema de erro, constata-se que sua variação ocorre entre -1 e 1. Um erro negativo indica que a Tensão de Saída (variável controlada) está abaixo da Tensão de Referência, requerendo uma compensação positiva no Duty Cycle, enquanto um erro positivo sinaliza que a tensão está acima, necessitando de uma compensação negativa. Observa-se também que a Variação do Erro obtida na simulação permanece próximo de zero, indicando que o sistema só possui erro de estado estacionário e que não há oscilações.

Com base nessas informações, um FIS será desenvolvido somente com uma entrada, denominada 'Error', e uma saída, denominada 'Mode'. Para a definição dos pesos das entradas, serão utilizadas funções de pertinência no formato Z para erros negativos e no formato S para erros positivos, conforme a Figura X. Pelo cálculo do erro utilizado ser normalizado, as funções de pertinência estão com um desvio para suavizar o peso de erros menores.

Figura X: Funções de Pertinência da Entrada do FIS


Fonte: Autor (MATLAB)

Para determinar o ajuste na saída, será empregada uma função de pertinência em formato de sino para saídas negativas e positivas, conforme a Figura X.

Figura X: Funções de Pertinência da Saída do FIS

Fonte: Autor (MATLAB)

Assim, obtém-se a superfície da Figura X que descreve o comportamento do FIS.

Figura X: Superfície de Comportamento do FIS


Fonte: Autor (MATLAB)

Analisando o gráfico, verifica-se que erros próximos de zero resultarão em pequenos ajustes, enquanto erros próximos de -0.5 e 0.5 produzirão ajustes máximos. Tal comportamento compensa a natureza do erro normalizado, que apresenta um crescimento acentuado à medida que se distancia de zero.

Para determinar a saída com base na superfície previamente definida, será criada uma tabela verdade que servirá como consulta, contendo 128 pontos amostrados da superfície do FIS conforme a Figura X.

Figura X: Superfície de Comportamento do FIS Amostrado


Fonte: Autor (MATLAB)

Assim, é possível criar o subsistema de controle no Simulink que aplica a tabela verdade para compensar o ciclo de trabalho (Duty Cycle) no sistema, conforme a Figura X abaixo.

Figura X: Subsitema do FIS Implementado


Fonte: Autor (MATLAB)

Para prevenir ajustes instantâneos e instabilidades no sistema, um integrador discreto foi adicionado, garantindo uma transição suave até o ponto de ajuste. Adicionalmente, um saturador é empregado para evitar o acúmulo de esforço no integrador.

Por fim, na Figura X, tem-se o sistema completo implementado no Simulink.

Figura X: Sistema em Malha Fechada Implementado

Fonte: Autor (Simulink)

5.5.3 Simulação em Malha Fechada Simulink

A simulação seguirá as mesmas condições anteriores, porém com a adição do controlador.

A Figura X ilustra a curva dos sinais Source Signal (SS) em amarelo, Reference Signal (RS) em verde e Output Voltage (OV) em vermelho para comparação, resultante do sistema em malha fechada.

Figura X: Gráfico Resultante da Tensão de Saída do Sistema em Malha Fechada


Fonte: Autor (Simulink)

É possível identificar facilmente os pontos de transição do modo de operação, dada a ausência de histerese. Também se observa que a tensão de saída (representada em vermelho), seguiu a tensão de referência devido a adição do compensador.

A Figura X ilustra a curva dos sinais do Erro em vermelho e Variação do Erro em magenta, resultante do sistema em malha fechada.

Figura X: Gráfico Resultante do Erro e Variação do Erro do Sistema em Malha Fechada


Fonte: Autor (Simulink)

Observa-se uma taxa de variação inicial do erro (curva magenta) devido à ativação do sistema até o alcance de seu estado estacionário, bem como outras variações durante as transições de modo de operação. O erro (curva vermelha) indica que a saída do sistema se aproxima da tensão de referência, mas não atinge exatamente zero. Considerando a utilização de um erro normalizado, pode-se deduzir que o erro é bem pequeno, conforme observado na Figura X, onde a tensão de saída está praticamente em cima da tensão de referência.

A Figura X ilustra a curva dos sinais Inductor Current (IC) em ciano e Output Current (OC) em vermelho, resultante do sistema em malha fechada.

Figura X: Gráfico Resultante da Corrente de Saída do Sistema em Malha Fechada


Fonte: Autor (Simulink)

A corrente do indutor manteve-se abaixo de 8 A, desconsiderando o ripple de 0.6 A. A corrente de saída, por sua vez, permaneceu inferior a 2 A. Infere-se, portanto, que a ação do compensador resultou em um aumento na corrente de entrada.

A Figura X ilustra a curva dos sinais do Ciclo de Trabalho em verde e Ciclo de Trabalho Compensado em vermelho, resultante do sistema em malha fechada.

Figura X: Gráfico Resultante do Ciclo de Trabalho do Sistema em Malha Fechada

Fonte: Autor (Simulink)

O valor do Ciclo de Trabalho (Duty Cycle) está em conformidade com o cálculo do modo de operação e se mantém dentro da faixa previamente estabelecida de 0.2 a 0.8. O valor controlado foi compensado e pode ser observado acima da curva verde principalmente na seção correspondente ao modo de operação Buck-Boost.

Em virtude da correção, verificou-se um incremento na corrente de entrada, o qual deverá ser devidamente levado em consideração no design do projeto.

5.6 Implementação Proteus (ATmega328P)

Agora que foi realizado a implementação teórica, para a validação e verificação do comportamento do conversor Buck-Boost em um ambiente mais próximo da realidade prática, esta seção detalha a implementação do sistema em um ambiente de simulação e desenvolvimento de hardware.

Será utilizada a ferramenta Proteus para a concepção e simulação do circuito eletrônico, enquanto a plataforma Arduino, centrada no microcontrolador ATmega328P, será empregada para o desenvolvimento e teste do firmware.

O circuito base do conversor foi implementado em um subsistema no Simulink, conforme ilustrado na Figura X.

Figura X: Conversor Buck-Boost Proteus


Fonte: Autor (Proteus)

O circuito possui cinco entradas: o sinal de fonte (Source Signal - SS) e as quatro chaves (SW). Suas duas saídas são: Tensão de Entrada (SV) e Tensão de Saída (OV), além de pontos de prova para a Corrente do Indutor (iL) e Corrente de Saída (OC). Os quatro modos de funcionamento do conversor são definidos pelo estado das quatro chaves e seus respectivos ciclos de trabalho (Duty Cycle). Uma vez que existem quatro modos distintos, são necessários dois bits para representá-los. A Tabela X, a seguir, sumariza a lógica de ativação de cada chave, utilizando A e B como entradas lógicas.

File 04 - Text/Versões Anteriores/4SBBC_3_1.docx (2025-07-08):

1. Configuração básica de um conversor Buck-Boost

O conversor DC-DC Buck-Boost, conforme a Figura X, é um tipo de conversor de potência que pode produzir uma tensão de saída maior ou menor que a tensão de entrada.

Figura X: Esquemático do Conversor Buck-Boost

Fonte: SLVA535B

Ele é composto pelos seguintes componentes principais:

- SW 1, SW 2, SW 3, SW 4: quatro comutadores, geralmente implementadas com MOSFETs. O chaveamento controlado dessas chaves determina o aumento ou redução da tensão.
- L: indutor responsável por armazenar a energia e realizar sua transferência a partir do funcionamento dos comutadores.
- CIN: capacitor de entrada para filtrar oscilações e fornecer uma tensão mais estável para o conversor.
- COUT: capacitor de saída para suavizar oscilações e fornecer uma tensão de saída mais estável para a carga.

2. Princípio de Operação

Ciclo de Trabalho é a fração de tempo em que um sinal ou uma chave está ligado dentro de um período fixo.

D=(T_(on))/T | (X)

Onde:

- D=ciclo de trabalho
- T_(on) =tempo que o sinal está ligado
- T=período do sinal

Ciclo de Trabalho Complementar é a fração de tempo em que o mesmo sinal está desligado dentro do mesmo período fixo.

1-D=(T_(off))/T | (X)

Onde:

- D=ciclo de trabalho complementar
- T_(off) =tempo que o sinal está desligado
- T=período do sinal

A Figura X descreve graficamente esse conceito e será útil futuramente, pois o ciclo de trabalho e seu complementar será necessário durante a aplicação do conversor.

Figura X: Ciclo de Trabalho Complementar


Fonte: Autor (Mathematica)

2.1 Buck Síncrono

A Figura X demonstra esse modo de funcionamento. O comutador Q3 é totalmente ligado e o comutador Q4 é totalmente desligado. Q1 e Q2 são controlados por D e 1 - D, respectivamente, e o sistema se torna um conversor Buck sincronizado.

Figura X: Buck Síncrono


Fonte: PMP21529

O ciclo de trabalho do modo Buck é calculado conforme a equação a seguir.

D=(V_o)/(V_i) | (X)

Onde:

- D=ciclo de trabalho
- V_o =tensão de saída
- V_i =tensão de entrada

Como nesse modo deseja-se reduzir a tensão de entrada, é necessário que esta seja maior que a tensão de saída ( V_i >V_o ). Apenas duas chaves são comutadas, e não é possível operar com V_i =V_o , pois nessas condições D=1 e o comutador Q1 fica ligado junto ao comutador Q3, causando um curto no sistema.

2.2 Boost Síncrono

A Figura X demonstra esse modo de funcionamento. O comutador Q1 é totalmente ligado e o comutador Q2 é totalmente desligado. Q3 e Q4 são controlados por 1 - D e D, respectivamente, e o sistema se torna um conversor Boost sincronizado.

Figura X: Bost Síncrono


Fonte: PMP21529

O ciclo de trabalho do modo Boost é calculado conforme a equação a seguir.

D=1-(V_i)/(V_o) | (X)

Onde:

- D=ciclo de trabalho
- V_o =tensão de saída
- V_i =tensão de entrada

Como nesse modo deseja-se aumentar a tensão de entrada, é necessário que esta seja menor que a tensão de saída ( V_i <V_o ). Apenas duas chaves são comutadas, e não é possível operar com V_i =V_o , pois nessas condições D=0 e o comutador Q1 fica ligado junto ao comutador Q3, causando um curto no sistema.

2.3 Buck-Boost Síncrono

A Figura X demonstra esse modo de funcionamento. O comutador Q1 e Q4 são controlados por D, enquanto Q2 e Q3 são controlados por 1 - D, e o sistema se torna um conversor Buck-Boost sincronizado.

Figura X: Buck-Bost Síncrono


Fonte: PMP21529

O ciclo de trabalho do modo Buck-Boost é calculado conforme a equação a seguir.

D=(V_o)/(V_i +V_o) | (X)

Onde:

- D=ciclo de trabalho
- V_o =tensão de saída
- V_i =tensão de entrada

Como nesse modo deseja-se reduzir ou aumentar a tensão de entrada, é possível utilizar durante a condição restrita dos modos anteriores, quando D=1 no modo Buck ou D=0 no modo Boost, pois na condição em que V_i =V_o no modo Buck-Boost, D≈0.5 . As quatros chaves são comutadas, reduzindo a eficiência em troca de operar nas condições restritas.

3. Modo de Operação

Os quatro interruptores alteram o modo de operação de acordo com a tensão de entrada e a tensão de saída, conforme mostrado na Figura X. Para evitar um salto entre as operações e evitar oscilações, uma histerese pode ser adicionada entre a transição dos modos.

Figura X: Modos de Operação com Base nas Tensões


Fonte: PMP21529

Durante a operação Buck, conforme a tensão de entrada diminui, o valor do ciclo de trabalho aproxima-se de 1, conforme a Equação X e o sistema realiza a troca de modo antes dessa ocorrência. O mesmo ocorre durante a operação Boost, conforme a tensão de entrada aumenta, o valor do ciclo de trabalho aproxima-se de 0, conforme a Equação X e o sistema troca de modo antes dessa ocorrência. Portanto, deve-se definir o limiar para a realização de trocas de modo, por exemplo, trocar de Buck para Buck-Boost quando D=0.8 .

4. Implementação

Os comutadores usados nessa aplicação serão MOSFETs. Um tempo de inatividade durante a comutação deve ser considerado para evitar correntes de disparo, evitando, por exemplo, que Q1 e Q2 estejam acionados ao mesmo tempo. Para acionamento dos comutadores, é necessário o uso de gate drives, pois as saídas dos circuitos de controle são de baixa potência, sendo incapazes de realizar o acionamento adequada dos comutaores.

Para o dimensionamento dos componentes em cada modo de operação, utiliza-se as equações a seguir.

4.1 Buck

L>1/(fΔi_L)*(V_o -(V_o^2)/(V_i)) | (X)

Onde:

- L=indutância do indutor
- f=frequência de comutação
- Δi_L =corrente ripple do inductor
- V_o =tensão de saída
- V_i =tensão de entrada

C>(Δi_L)/(8fΔV_o) | (X)

Onde:

- C=capacitância do capacitor
- f=frequência de comutação
- Δi_L =corrente ripple do inductor
- ΔV_o =tensão ripple de saída

4.2 Buck-Boost

L>1/(fΔi_L)*(V_o)/(1+(V_o)/(V_i)) | (X)

Onde:

- L=indutância do indutor
- f=frequência de comutação
- Δi_L =corrente ripple do inductor
- V_o =tensão de saída
- V_i =tensão de entrada

C>(I_o)/(fΔV_o)*(V_o)/(V_o +V_i) | (X)

Onde:

- C=capacitância do capacitor
- f=frequência de comutação
- I_o =corrente de saída
- ΔV_o =tensão ripple de saída
- V_o =tensão de saída
- V_i =tensão de entrada

4.3 Boost

L>1/(fΔi_L)*(V_i -(V_i^2)/(V_o)) | (X)

Onde:

- L=indutância do indutor
- f=frequência de comutação
- Δi_L =corrente ripple do inductor
- V_o =tensão de saída
- V_i =tensão de entrada

C>(I_o)/(fΔV_o)*(V_o -V_i)/(V_o) | (X)

Onde:

- C=capacitância do capacitor
- f=frequência de comutação
- I_o =corrente de saída
- ΔV_o =tensão ripple do capacitor

5. Design

Para esse projeto, as considerações iniciais para desenvolvimento são:

- V_(i_(min)) =18 V
- V_(i_(max)) =30 V
- D_(min) =0.2
- D_(max) =0.8

A Tabela X a seguir resume o cálculo do ciclo de trabalho para cada modo de operação, para os cálculos das regiões de operação a seguir.

Tabela X: Resumo do Ciclo de Trabalho por Modo de Operação

Modo de operação | Ciclo de trabalho
Buck | D=1/((V_i)/(V_o))
Buck-boost | D=1/(1+(V_i)/(V_o))
Boost | D=1-(V_i)/(V_o)

5.1 Região Buck

Utilizando a Equação X, calcula-se os valores mínimos e máximos da tensão de saída possíveis nessa região com base no ciclo de trabalho determinado.

D_(min) =1/((V_(i_(max)))/(V_(o_(min))))→V_(o_(min)) =D_(min) V_(i_(max)) =0.2*30=6 V

D_(max) =1/((V_(i_(max)))/(V_(o_(max))))→V_(o_(max)) =D_(max) V_(i_(max)) =0.8*30=24 V

Agora calcula-se uma relação entre entrada e saída que limitam essa região.

(V_(i_(max)))/(V_(o_(max)))<(V_i)/(V_o)<(V_(i_(max)))/(V_(o_(min)))→30/24<(V_i)/(V_o)<30/6→1.25<(V_i)/(V_o)<5

Assim, enquanto a relação estiver entre 1.25 e 5, o modo de operação será Buck.

Considera-se a região esquerda como Buck, central como Buck-Boost e direita como Boost para as definições seguintes.

Quando o limite esquerdo 1.25 é atingido, é possível calcular a tensão de saída mínima V_(o_1) e máxima V_(o_2) de transição com base na tensão de entrada mínima e máxima, determinando a fronteira da região Buck com a região central.

(V_(i_(max)))/(V_(o_(max)))=(V_(i_(min)))/(V_(o_1))→1.25=18/(V_(o_1))→V_(o_1) =18/1.25=14.4 V

(V_(i_(max)))/(V_(o_(max)))=(V_(i_(min)))/(V_(o_2))→1.25=30/(V_(o_2))→V_(o_2) =30/1.25=24 V

Obtém-se que a região Buck opera com tensões de entrada entre 18 e 30 V, e tensões de saída entre 6 e 24 V. A fronteira com a região central consiste em uma reta com tensões de saída entre 14.4 e 24 V.

5.2 Região Boost

Utilizando a Equação X, calcula-se os valores mínimos e máximos da tensão de saída possíveis nessa região com base no ciclo de trabalho determinado.

D_(min) =1-(V_(i_(min)))/(V_(o_(min)))→V_(o_(min)) =(V_(i_(min)))/(1-D_(min))=18/(1-0.2)=22.5 V

D_(max) =1-(V_(i_(max)))/(V_(o_(max)))→V_(o_(max)) =(V_(i_(max)))/(1-D_(max))=30/(1-0.8)=150 V

Agora calcula-se uma relação entre entrada e saída que limitam essa região.

(V_(i_(max)))/(V_(o_(max)))<(V_i)/(V_o)<(V_(i_(min)))/(V_(o_(min)))→30/150<(V_i)/(V_o)<18/22.5→0.2<(V_i)/(V_o)<0.8

Assim, enquanto a relação estiver entre 0.2 e 0.8, o modo de operação será Buck.

Quando o limite direito 0.8 é atingido, é possível calcular a tensão de saída mínima V_(o_1) e máxima V_(o_2) de transição com base na tensão de entrada mínima e máxima, determinando a fronteira da região Boost com a região central.

(V_(i_(max)))/(V_(o_(max)))=(V_(i_(min)))/(V_(o_1))→0.8=18/(V_(o_1))→V_(o_1) =18/0.8=22.5 V

(V_(i_(max)))/(V_(o_(max)))=(V_(i_(min)))/(V_(o_2))→0.8=30/(V_(o_2))→V_(o_2) =30/0.8=37.5 V

Obtém-se que a região Boost opera com tensões de entrada entre 18 e 30 V, e tensões de saída entre 22.5 e 150 V. A fronteira com a região central consiste em uma reta com tensões de saída entre 22.5 e 37.5 V.

5.2 Região Buck-Boost

A região central, é obtida automaticamente ao identificar-se as duas fronteiras. Portanto, obtém-se que a região Buck-Boost opera com tensões de entrada entre 18 e 30 V, e tensões de saída entre 14.4 e 37.5 V.

5.3 Regiões de operação

Novas considerações:

- V_(o_(min)) =6 V
- V_(o_(max)) =55 V

A Tabela X a seguir resume as novas informações obtidas para cada modo de operação.

Tabela X: Resumo da Região de Operação/Tensão de Operação por Modo de Operação

Modo de operação | Região de operação | Tensão de operação
Buck | (V_i)/(V_o)>1.25 | V_i =[18,30]V_o =[6,24]
Buck-Boost | 0.80≤(V_i)/(V_o)≤1.25 | V_i =[18,30]V_o =[14.4,37.5]
Boost | (V_i)/(V_o)<0.80 | V_i =[18,30]V_o =[22.5,55]

5.3.1 Regiões de operação

A partir das informações obtidas anteriormente, é possível calcular o ciclo de trabalho para cada combinação de entradas e saídas, e construir um gráfico de contorno que representa as regiões de operação, facilitando a visualização das fronteiras entre elas, conforme a Figura X.

Figura X: Gráfico de Contorno das Regiões de Operação


Fonte: Autor (Mathematica)

Para visualizar a profundidade, pode-se converter os eixos em uma variável única que represente tensão de entrada sobre tensão de saída no eixo horizontal e representar o Duty Cycle no eixo vertical, conforme a Figura X.

Figura X: Gráfico do Duty Cycle por Região de Operação


Fonte: Autor (Mathematica)

Vale comentar que, pela tensão máxima ter sido considerada 55 V, o valor de Duty Cycle teórico não atinge o valor de 0.8 na região Boost.

5.4 Cálculo dos Componentes

Novas considerações:

- I_(o_(max)) =2 A
- f=10 kHz
- Δi_(L_(max)) =0.6 A (30%)
- ΔV_(o_(max)) =1 V (2%)

5.4.1 Buck

A partir das Equações X e Y.

L>1/(fΔi_L)*(V_o -(V_o^2)/(V_i _(max)))>1/(10*10^3 *0.6)*(V_o -(V_o^2)/30)

d/(dV_o)L=0→V_o =15 V

L>1/(10*10^3 *0.6)*(15-(15^2)/30)>1.25 mH

C>(Δi_L)/(8fΔV_o)>0.6/(8*10*10^3 *1)>7.5 uF

5.2 Buck-Boost

A partir das Equações X e Y.

L>1/(fΔi_L)*(V_(o_(max)))/(1+(V_(o_(max)))/(V_i _(max)))>1/(10*10^3 *0.6)*37.5/(1+37.5/30)>2.78 mH

C>(I_o)/(fΔV_o)*(V_(o_(max)))/(V_(o_(max)) +V_i _(min))>2/(10*10^3 *1)*37.5/(37.5+18)>135.1 uF

5.3 Boost

A partir das Equações X e Y.

L>1/(fΔi_L)*(V_i -(V_i^2)/(V_(o_(max))))>1/(10*10^3 *0.6)*(V_i -(V_i^2)/55)

d/(dV_i)L=0→V_i =27.5 V

L>1/(10*10^3 *0.6)*(27.5-(27.5^2)/55)>2.29 mH

C>(I_o)/(fΔV_o)*(V_(o_(max)) -V_i _(min))/(V_(o_(max)))>2/(10*10^3 *1)*(55-18)/55>134.5 uF

5.4 Verficação

Com os componentes de cada modo de operação obtidos, utiliza-se aqueles com o maior valor para cobrir todo o funcionamento do sistema.

Novas considerações:

- L>2.78 mH
- C>135.1 uF

Calcula-se o ripple máximo da corrente do indutor e da tensão de saída com base nas equações anteriores.

5.4.1 Buck

2.78*10^(-3) =1/(10*10^3 *Δi_L)*(15-(15^2)/30)→Δi_(L_(max)) =0.27 A

135.1*10^(-6) =0.27/(8*10*10^3 *ΔV_o)→ΔV_(o_(max)) =0.025 V

5.4.2 Buck-Boost

2.78*10^(-3) =1/(10*10^3 *Δi_L)*37.5/(1+37.5/30)→Δi_(L_(max)) =0.6 A

135.1*10^(-6) =2/(10*10^3 *ΔV_o)*37.5/(37.5+18)→ΔV_(o_(max)) =1 V

5.4.2 Boost

2.78*10^(-3) =1/(10*10^3 *Δi_L)*(27.5-(27.5^2)/55)→Δi_(L_(max)) =0.49 A

135.1*10^(-6) =2/(10*10^3 *ΔV_o)*(55-18)/55→ΔV_(o_(max)) =1 V

Por fim, verificou-se que os valores estão dentro do considerado para esse design.

5.4.3 Resumo Final

As informações adquiridas do design até o momento são resumidas na Tabela X a seguir.

Tabela X: Gráfico do Duty Cycle por Região de Operação

Modo de operação | Faixa de operação (V) | Duty Cycle | Vi/Vo | Δi_L _(max) (A) | ΔV_o _(max) (V)
Buck | V_i =[18,30]V_o =[6,24] | D=[0.2,0.8] | 0.2≤(V_i)/(V_o)<0.8 | 0.27 | 0.025
Buck-Boost | V_i =[18,30]V_o =[14.4,37.5] | D=[0.4,0.5] | 0.8≤(V_i)/(V_o)≤1.25 | 0.6 | 1
Boost | V_i =[18,30]V_o =[22.5,55] | D=[0.2,0.8] | 1.25<(V_i)/(V_o)≤5 | 0.49 | 1

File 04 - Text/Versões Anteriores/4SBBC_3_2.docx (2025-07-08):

1. Configuração básica de um conversor Buck-Boost

O conversor DC-DC Buck-Boost, conforme a Figura X, é um tipo de conversor de potência que pode produzir uma tensão de saída maior ou menor que a tensão de entrada.

Figura X: Esquemático do Conversor Buck-Boost

Fonte: SLVA535B

Ele é composto pelos seguintes componentes principais:

- SW 1, SW 2, SW 3, SW 4: quatro comutadores, geralmente implementadas com MOSFETs. O chaveamento controlado dessas chaves determina o aumento ou redução da tensão.
- L: indutor responsável por armazenar a energia e realizar sua transferência a partir do funcionamento dos comutadores.
- CIN: capacitor de entrada para filtrar oscilações e fornecer uma tensão mais estável para o conversor.
- COUT: capacitor de saída para suavizar oscilações e fornecer uma tensão de saída mais estável para a carga.

2. Princípio de Operação

Ciclo de Trabalho é a fração de tempo em que um sinal ou uma chave está ligado dentro de um período fixo.

D=(T_(on))/T | (X)

Onde:

- D=ciclo de trabalho
- T_(on) =tempo que o sinal está ligado
- T=período do sinal

Ciclo de Trabalho Complementar é a fração de tempo em que o mesmo sinal está desligado dentro do mesmo período fixo.

1-D=(T_(off))/T | (X)

Onde:

- D=ciclo de trabalho complementar
- T_(off) =tempo que o sinal está desligado
- T=período do sinal

A Figura X descreve graficamente esse conceito e será útil futuramente, pois o ciclo de trabalho e seu complementar será necessário durante a aplicação do conversor.

Figura X: Ciclo de Trabalho Complementar


Fonte: Autor (Mathematica)

2.1 Buck Síncrono

A Figura X demonstra esse modo de funcionamento. O comutador Q3 é totalmente ligado e o comutador Q4 é totalmente desligado. Q1 e Q2 são controlados por D e 1 - D, respectivamente, e o sistema se torna um conversor Buck sincronizado.

Figura X: Buck Síncrono

Fonte: PMP21529

O ciclo de trabalho do modo Buck é calculado conforme a equação a seguir.

D=(V_o)/(V_i) | (X)

Onde:

- D=ciclo de trabalho
- V_o =tensão de saída
- V_i =tensão de entrada

Como nesse modo deseja-se reduzir a tensão de entrada, é necessário que esta seja maior que a tensão de saída ( V_i >V_o ). Apenas duas chaves são comutadas, e não é possível operar com V_i =V_o , pois nessas condições D=1 e o comutador Q1 fica ligado junto ao comutador Q3, causando um curto no sistema.

2.2 Boost Síncrono

A Figura X demonstra esse modo de funcionamento. O comutador Q1 é totalmente ligado e o comutador Q2 é totalmente desligado. Q3 e Q4 são controlados por 1 - D e D, respectivamente, e o sistema se torna um conversor Boost sincronizado.

Figura X: Bost Síncrono


Fonte: PMP21529

O ciclo de trabalho do modo Boost é calculado conforme a equação a seguir.

D=1-(V_i)/(V_o) | (X)

Onde:

- D=ciclo de trabalho
- V_o =tensão de saída
- V_i =tensão de entrada

Como nesse modo deseja-se aumentar a tensão de entrada, é necessário que esta seja menor que a tensão de saída ( V_i <V_o ). Apenas duas chaves são comutadas, e não é possível operar com V_i =V_o , pois nessas condições D=0 e o comutador Q1 fica ligado junto ao comutador Q3, causando um curto no sistema.

2.3 Buck-Boost Síncrono

A Figura X demonstra esse modo de funcionamento. O comutador Q1 e Q4 são controlados por D, enquanto Q2 e Q3 são controlados por 1 - D, e o sistema se torna um conversor Buck-Boost sincronizado.

Figura X: Buck-Bost Síncrono

Fonte: PMP21529

O ciclo de trabalho do modo Buck-Boost é calculado conforme a equação a seguir.

D=(V_o)/(V_i +V_o) | (X)

Onde:

- D=ciclo de trabalho
- V_o =tensão de saída
- V_i =tensão de entrada

Como nesse modo deseja-se reduzir ou aumentar a tensão de entrada, é possível utilizar durante a condição restrita dos modos anteriores, quando D=1 no modo Buck ou D=0 no modo Boost, pois na condição em que V_i =V_o no modo Buck-Boost, D≈0.5 . As quatros chaves são comutadas, reduzindo a eficiência em troca de operar nas condições restritas.

3. Modo de Operação

Os quatro interruptores alteram o modo de operação de acordo com a tensão de entrada e a tensão de saída, conforme mostrado na Figura X. Para evitar um salto entre as operações e evitar oscilações, uma histerese pode ser adicionada entre a transição dos modos.

Figura X: Modos de Operação com Base nas Tensões


Fonte: PMP21529

Durante a operação Buck, conforme a tensão de entrada diminui, o valor do ciclo de trabalho aproxima-se de 1, conforme a Equação X e o sistema realiza a troca de modo antes dessa ocorrência. O mesmo ocorre durante a operação Boost, conforme a tensão de entrada aumenta, o valor do ciclo de trabalho aproxima-se de 0, conforme a Equação X e o sistema troca de modo antes dessa ocorrência. Portanto, deve-se definir o limiar para a realização de trocas de modo, por exemplo, trocar de Buck para Buck-Boost quando D=0.8 .

4. Implementação

Os comutadores usados nessa aplicação serão MOSFETs. Um tempo de inatividade durante a comutação deve ser considerado para evitar correntes de disparo, evitando, por exemplo, que Q1 e Q2 estejam acionados ao mesmo tempo. Para acionamento dos comutadores, é necessário o uso de gate drives, pois as saídas dos circuitos de controle são de baixa potência, sendo incapazes de realizar o acionamento adequada dos comutaores.

Para o dimensionamento dos componentes em cada modo de operação, utiliza-se as equações a seguir.

4.1 Buck

L>1/(fΔi_L)*(V_o -(V_o^2)/(V_i)) | (X)

Onde:

- L=indutância do indutor
- f=frequência de comutação
- Δi_L =corrente ripple do inductor
- V_o =tensão de saída
- V_i =tensão de entrada

C>(Δi_L)/(8fΔV_o) | (X)

Onde:

- C=capacitância do capacitor
- f=frequência de comutação
- Δi_L =corrente ripple do inductor
- ΔV_o =tensão ripple de saída

4.2 Buck-Boost

L>1/(fΔi_L)*(V_o)/(1+(V_o)/(V_i)) | (X)

Onde:

- L=indutância do indutor
- f=frequência de comutação
- Δi_L =corrente ripple do inductor
- V_o =tensão de saída
- V_i =tensão de entrada

C>(I_o)/(fΔV_o)*(V_o)/(V_o +V_i) | (X)

Onde:

- C=capacitância do capacitor
- f=frequência de comutação
- I_o =corrente de saída
- ΔV_o =tensão ripple de saída
- V_o =tensão de saída
- V_i =tensão de entrada

4.3 Boost

L>1/(fΔi_L)*(V_i -(V_i^2)/(V_o)) | (X)

Onde:

- L=indutância do indutor
- f=frequência de comutação
- Δi_L =corrente ripple do inductor
- V_o =tensão de saída
- V_i =tensão de entrada

C>(I_o)/(fΔV_o)*(V_o -V_i)/(V_o) | (X)

Onde:

- C=capacitância do capacitor
- f=frequência de comutação
- I_o =corrente de saída
- ΔV_o =tensão ripple do capacitor

5. Design

Considerações iniciais:

- V_(i_(min)) =18 V
- V_(i_(max)) =30 V
- D_(min) =0.2
- D_(max) =0.8

A Tabela X a seguir resume o cálculo do ciclo de trabalho para cada modo de operação, para os cálculos das regiões de operação a seguir.

Tabela X: Resumo do Ciclo de Trabalho por Modo de Operação

Modo de operação | Ciclo de trabalho
Buck | D=1/((V_i)/(V_o))
Buck-boost | D=1/(1+(V_i)/(V_o))
Boost | D=1-(V_i)/(V_o)

5.1 Região Buck

Utilizando a Equação X, calcula-se os valores mínimos e máximos da tensão de saída possíveis nessa região com base no ciclo de trabalho determinado.

D_(min) =1/((V_(i_(max)))/(V_(o_(min))))→V_(o_(min)) =D_(min) V_(i_(max)) =0.2*30=6 V

D_(max) =1/((V_(i_(max)))/(V_(o_(max))))→V_(o_(max)) =D_(max) V_(i_(max)) =0.8*30=24 V

Agora calcula-se uma relação entre entrada e saída que limitam essa região.

(V_(i_(max)))/(V_(o_(max)))<(V_i)/(V_o)<(V_(i_(max)))/(V_(o_(min)))→30/24<(V_i)/(V_o)<30/6→1.25<(V_i)/(V_o)<5

Assim, enquanto a relação estiver entre 1.25 e 5, o modo de operação será Buck.

Considera-se a região esquerda como Buck, central como Buck-Boost e direita como Boost para as definições seguintes.

Quando o limite esquerdo 1.25 é atingido, é possível calcular a tensão de saída mínima V_(o_1) e máxima V_(o_2) de transição com base na tensão de entrada mínima e máxima, determinando a fronteira da região Buck com a região central.

(V_(i_(max)))/(V_(o_(max)))=(V_(i_(min)))/(V_(o_1))→1.25=18/(V_(o_1))→V_(o_1) =18/1.25=14.4 V

(V_(i_(max)))/(V_(o_(max)))=(V_(i_(min)))/(V_(o_2))→1.25=30/(V_(o_2))→V_(o_2) =30/1.25=24 V

Obtém-se que a região Buck opera com tensões de entrada entre 18 e 30 V, e tensões de saída entre 6 e 24 V. A fronteira com a região central consiste em uma reta com tensões de saída entre 14.4 e 24 V.

5.2 Região Boost

Utilizando a Equação X, calcula-se os valores mínimos e máximos da tensão de saída possíveis nessa região com base no ciclo de trabalho determinado.

D_(min) =1-(V_(i_(min)))/(V_(o_(min)))→V_(o_(min)) =(V_(i_(min)))/(1-D_(min))=18/(1-0.2)=22.5 V

D_(max) =1-(V_(i_(max)))/(V_(o_(max)))→V_(o_(max)) =(V_(i_(max)))/(1-D_(max))=30/(1-0.8)=150 V

Agora calcula-se uma relação entre entrada e saída que limitam essa região.

(V_(i_(max)))/(V_(o_(max)))<(V_i)/(V_o)<(V_(i_(min)))/(V_(o_(min)))→30/150<(V_i)/(V_o)<18/22.5→0.2<(V_i)/(V_o)<0.8

Assim, enquanto a relação estiver entre 0.2 e 0.8, o modo de operação será Buck.

Quando o limite direito 0.8 é atingido, é possível calcular a tensão de saída mínima V_(o_1) e máxima V_(o_2) de transição com base na tensão de entrada mínima e máxima, determinando a fronteira da região Boost com a região central.

(V_(i_(max)))/(V_(o_(max)))=(V_(i_(min)))/(V_(o_1))→0.8=18/(V_(o_1))→V_(o_1) =18/0.8=22.5 V

(V_(i_(max)))/(V_(o_(max)))=(V_(i_(min)))/(V_(o_2))→0.8=30/(V_(o_2))→V_(o_2) =30/0.8=37.5 V

Obtém-se que a região Boost opera com tensões de entrada entre 18 e 30 V, e tensões de saída entre 22.5 e 150 V. A fronteira com a região central consiste em uma reta com tensões de saída entre 22.5 e 37.5 V.

5.2 Região Buck-Boost

A região central, é obtida automaticamente ao identificar-se as duas fronteiras. Portanto, obtém-se que a região Buck-Boost opera com tensões de entrada entre 18 e 30 V, e tensões de saída entre 14.4 e 37.5 V.

5.3 Regiões de operação

Novas considerações:

- V_(o_(min)) =6 V
- V_(o_(max)) =55 V

A Tabela X a seguir resume as novas informações obtidas para cada modo de operação.

Tabela X: Resumo da Região de Operação/Tensão de Operação por Modo de Operação

Modo de operação | Região de operação | Tensão de operação
Buck | (V_i)/(V_o)>1.25 | V_i =[18,30]V_o =[6,24]
Buck-Boost | 0.80≤(V_i)/(V_o)≤1.25 | V_i =[18,30]V_o =[14.4,37.5]
Boost | (V_i)/(V_o)<0.80 | V_i =[18,30]V_o =[22.5,55]

5.3.1 Regiões de operação

A partir das informações obtidas anteriormente, é possível calcular o ciclo de trabalho para cada combinação de entradas e saídas, e construir um gráfico de contorno que representa as regiões de operação, facilitando a visualização das fronteiras entre elas, conforme a Figura X.

Figura X: Gráfico de Contorno das Regiões de Operação

Fonte: Autor (Mathematica)

Para visualizar a profundidade, pode-se converter os eixos em uma variável única que represente tensão de entrada sobre tensão de saída no eixo horizontal e representar o Duty Cycle no eixo vertical, conforme a Figura X.

Figura X: Gráfico do Duty Cycle por Região de Operação


Fonte: Autor (Mathematica)

Vale comentar que, pela tensão máxima ter sido considerada 55 V, o valor de Duty Cycle teórico não atinge o valor de 0.8 na região Boost.

5.4 Cálculo dos Componentes

Novas considerações:

- I_(o_(max)) =2 A
- f=10 kHz
- Δi_(L_(max)) =0.6 A (30%)
- ΔV_(o_(max)) =1 V (2%)

5.4.1 Buck

A partir das Equações X e Y.

L>1/(fΔi_L)*(V_o -(V_o^2)/(V_i _(max)))>1/(10*10^3 *0.6)*(V_o -(V_o^2)/30)

d/(dV_o)L=0→V_o =15 V

L>1/(10*10^3 *0.6)*(15-(15^2)/30)>1.25 mH

C>(Δi_L)/(8fΔV_o)>0.6/(8*10*10^3 *1)>7.5 uF

5.2 Buck-Boost

A partir das Equações X e Y.

L>1/(fΔi_L)*(V_(o_(max)))/(1+(V_(o_(max)))/(V_i _(max)))>1/(10*10^3 *0.6)*37.5/(1+37.5/30)>2.78 mH

C>(I_o)/(fΔV_o)*(V_(o_(max)))/(V_(o_(max)) +V_i _(min))>2/(10*10^3 *1)*37.5/(37.5+18)>135.1 uF

5.3 Boost

A partir das Equações X e Y.

L>1/(fΔi_L)*(V_i -(V_i^2)/(V_(o_(max))))>1/(10*10^3 *0.6)*(V_i -(V_i^2)/55)

d/(dV_i)L=0→V_i =27.5 V

L>1/(10*10^3 *0.6)*(27.5-(27.5^2)/55)>2.29 mH

C>(I_o)/(fΔV_o)*(V_(o_(max)) -V_i _(min))/(V_(o_(max)))>2/(10*10^3 *1)*(55-18)/55>134.5 uF

5.4 Verficação

Com os componentes de cada modo de operação obtidos, utiliza-se aqueles com o maior valor para cobrir todo o funcionamento do sistema.

Novas considerações:

- L>2.78 mH
- C>135.1 uF

Calcula-se o ripple máximo da corrente do indutor e da tensão de saída com base nas equações anteriores.

5.4.1 Buck

2.78*10^(-3) =1/(10*10^3 *Δi_L)*(15-(15^2)/30)→Δi_(L_(max)) =0.27 A

135.1*10^(-6) =0.27/(8*10*10^3 *ΔV_o)→ΔV_(o_(max)) =0.025 V

5.4.2 Buck-Boost

2.78*10^(-3) =1/(10*10^3 *Δi_L)*37.5/(1+37.5/30)→Δi_(L_(max)) =0.6 A

135.1*10^(-6) =2/(10*10^3 *ΔV_o)*37.5/(37.5+18)→ΔV_(o_(max)) =1 V

5.4.2 Boost

2.78*10^(-3) =1/(10*10^3 *Δi_L)*(27.5-(27.5^2)/55)→Δi_(L_(max)) =0.49 A

135.1*10^(-6) =2/(10*10^3 *ΔV_o)*(55-18)/55→ΔV_(o_(max)) =1 V

Por fim, verificou-se que os valores estão dentro do considerado para esse design.

5.4.3 Resumo Final

As informações adquiridas do design até o momento são resumidas na Tabela X a seguir.

Tabela X: Gráfico do Duty Cycle por Região de Operação

Modo de operação | Faixa de operação (V) | Duty Cycle | Vi/Vo | Δi_L _(max) (A) | ΔV_o _(max) (V)
Buck | V_i =[18,30]V_o =[6,24] | D=[0.2,0.8] | 0.2≤(V_i)/(V_o)<0.8 | 0.27 | 0.025
Buck-Boost | V_i =[18,30]V_o =[14.4,37.5] | D=[0.4,0.5] | 0.8≤(V_i)/(V_o)≤1.25 | 0.6 | 1
Boost | V_i =[18,30]V_o =[22.5,55] | D=[0.2,0.8] | 1.25<(V_i)/(V_o)≤5 | 0.49 | 1

5.5 Implementação Simulink

O circuito base do conversor foi implementado em um subsistema no Simulink, conforme ilustrado na Figura X.

Figura X: Subsistema do Conversor Buck-Boost Implementada

Fonte: Autor (Simulink)

O subsistema possui duas entradas: o sinal de fonte (Source Signal - SS) e as quatro chaves multiplexadas (SW). Suas quatro saídas são: Tensão de Saída (Output Voltage - OV), Corrente de Saída (Output Current - OC), Tensão do Indutor (Inductor Voltage - v_L) e Corrente do Indutor (Inductor Current - i_L). Os quatro modos de funcionamento do conversor são definidos pelo estado das quatro chaves e seus respectivos ciclos de trabalho (Duty Cycle). Uma vez que existem quatro modos distintos, são necessários dois bits para representá-los. A Tabela X, a seguir, sumariza a lógica de ativação de cada chave, utilizando A e B como entradas lógicas.

Tabela X: Lógica de Ativação dos Switches

Mode | AB | SW1 | SW2 | SW3 | SW4
Buck | 00 | D | 1 - D | 1 | 0
Buck-boost | 01 | D | 1 - D | 1 - D | D
Boost | 11 | 1 | 0 | 1 - D | D
Off | 10 | 0 | 0 | 0 | 0

Com base nos princípios de sistemas digitais, é possível simplificar a lógica de acionamento de cada chave, resultando nas equações apresentadas a seguir.

SW1=AD+AB SW2=AD SW3=AB+BD SW4=BD | (X)

Onde:

- SWx=lógica de ativação do switch
- A=entrada lógica
- B=entrada lógica
- D=saída do PWM
- D=saída complementar do PWM

Com base nas relações apresentadas, é possível implementar um subsistema no Simulink para controlar o funcionamento de cada chave, utilizando as entradas A, B e D, conforme a Figura X.

Figura X: Subsistema de Ativação dos Switches Implementada


Fonte: Autor (Simulink)

O modo de operação, tanto o atual quanto o futuro, é determinado pela relação entre a Tensão de Entrada e a Tensão de Referência. Essa relação é detalhada na Tabela X a seguir.

Tabela X: Lógica do Modo de Operação

Modo de operação | Vi/Vo
Buck | 1.25<(V_i)/(V_o)≤5
Buck-Boost | 0.8≤(V_i)/(V_o)≤1.25
Boost | 0.2≤(V_i)/(V_o)<0.8

A Tabela X indica que o modo de funcionamento será Buck quando a Tensão de Entrada exceder 125% da Tensão de Referência. Por outro lado, o modo de funcionamento será Boost quando a Tensão de Entrada estiver abaixo de 80% da Tensão de Referência. Essa relação pode ser expressa conforme a equação lógica abaixo.

X=(V_i)/(V_o)>1.25 Y=(V_i)/(V_o)>0.8 | (X)

Onde:

- X,Y=saída lógica do modo de operação
- V_i =tensão de entrada
- V_o =tensão de saída

A Tabela X, a seguir, sumariza a lógica dos modos de funcionamento conforme as saídas lógicas da Equação X.

Tabela X: Lógica de Escolha dos Modos de Operação

XY | Buck | Buck-Boost | Boost
00 | 0 | 0 | 1
01 | 0 | 1 | 0
11 | 1 | 0 | 0
10 | X | X | X

Com a aplicação de conceitos de sistemas digitais, é possível simplificar essa relação, resultando nas equações lógicas apresentadas a seguir.

Buck=X Buck-Boost=XY Boost=Y | (X)

A lógica descrita pode ser implementada no Simulink por meio do subsistema ilustrado na Figura X.

Figura X: Subsistema de Escolha de Modos Implementada

Fonte: Autor (Simulink)

Com a determinação do modo de operação, o próximo passo é o cálculo do Ciclo de Trabalho (Duty Cycle). Embora cada modo possua seu Duty Cycle calculado, apenas o valor correspondente ao modo ativo será empregado no acionamento das chaves. Conforme previamente estabelecido nas Equações X, Y e Z, o cálculo requer apenas a Tensão de Entrada e a Tensão de Referência, conforme a Figura X.

Figura X: Equações do Ciclo de Trabalho Implementada


Fonte: Autor (Simulink)

Os valores de A e B, previamente definidos na Tabela X, são anexados juntamente ao respectivo valor de D por meio de um multiplexador (MUX). Para determinar qual valor será utilizado, o resultado do subsistema anterior é empregado em conjunto com comparadores lógicos, direcionando o valor para as variáveis A, B e D através de um demultiplexador (DEMUX), conforme ilustrado abaixo.

Figura X: Direcionamento dos Valores A, B e D Implementada


Fonte: Autor (Simulink)

Dado que apenas um dos comparadores estará ativo em determinado momento, A e B podem ser calculados por meio de uma porta OR, enquanto D pode ser obtido por uma soma simples, conforme a Figura X

Figura X: Valor Final de A e B Implementada

Fonte: Autor (Simulink)

Para fins de controle, a variável D pode ser somada a uma entrada externa (D_FIS), conforme a Figura X. Adicionalmente, o ciclo de trabalho (Duty Cycle) é limitado entre 0.2 e 0.8.

Figura X: Valor Final de D Implementada

Fonte: Autor (Simulink)

Desse modo, conforme ilustrado na Figura X, obtém-se o subsistema responsável pela determinação da variável D do sistema.

Figura X: Subsistema Final para o Cálculo do Ciclo de Trabalho Implementada


Fonte: Autor (Simulink)

Com as variáveis A, B e D devidamente determinadas, o funcionamento das chaves (Switches) também é definido, tornando o sistema apto para operação em malha aberta.

Para a visualização do erro e de sua variação, é necessário um subsistema. O erro pode ser caracterizado pela diferença entre a Tensão de Saída e a Tensão de Referência, e sua variação, pela diferença entre o erro atual e o anterior, considerando o uso de valores discretos. Para otimizar a visualização do desempenho, será empregado um erro normalizado, conforme as equações a seguir.

E[n]=(V_o -V_r)/(|V_o -V_r |+1) | (X)
dE[n]=E[n]-E[n-1] | (X)

Onde:

- E[n]=erro atual
- V_o =tensão de saída atual
- V_r =tensão de referência atual
- dE[n]=variação do erro
- E[n-1]=erro anterior

O subsistema implementado no Simulink pode ser visualizado na Figura X abaixo.

Figura X: Subsistema do Erro Normalizado Implementado

Fonte: Autor (Simulink)

O resultado final do sistema em malha aberta, bem como a visualização do erro obtida a partir da união dos subsistemas, pode ser observado na Figura X.

Figura X: Sistema em Malha Aberta Implementado


Fonte: Autor (Simulink)

Agora é possível realizar uma simulação contemplando todas as combinações possíveis de tensão de entrada e saída, descritas a seguir.
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

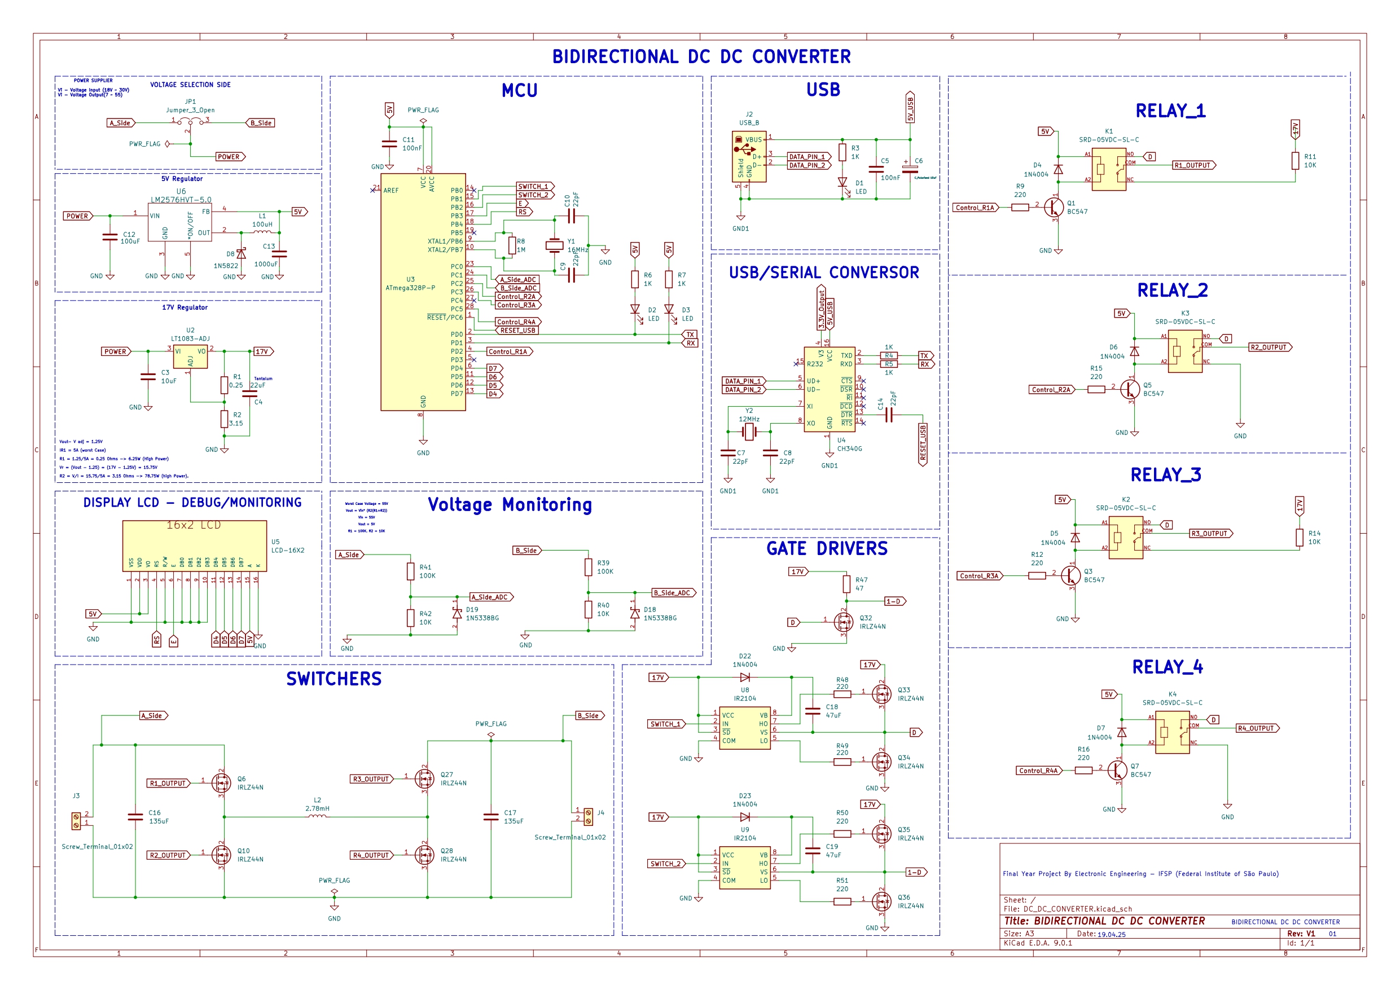
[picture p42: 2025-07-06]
03 - Hadware/01 - Schematic/Schematic Final Version DC DC CONVERTER_page-0001.jpg

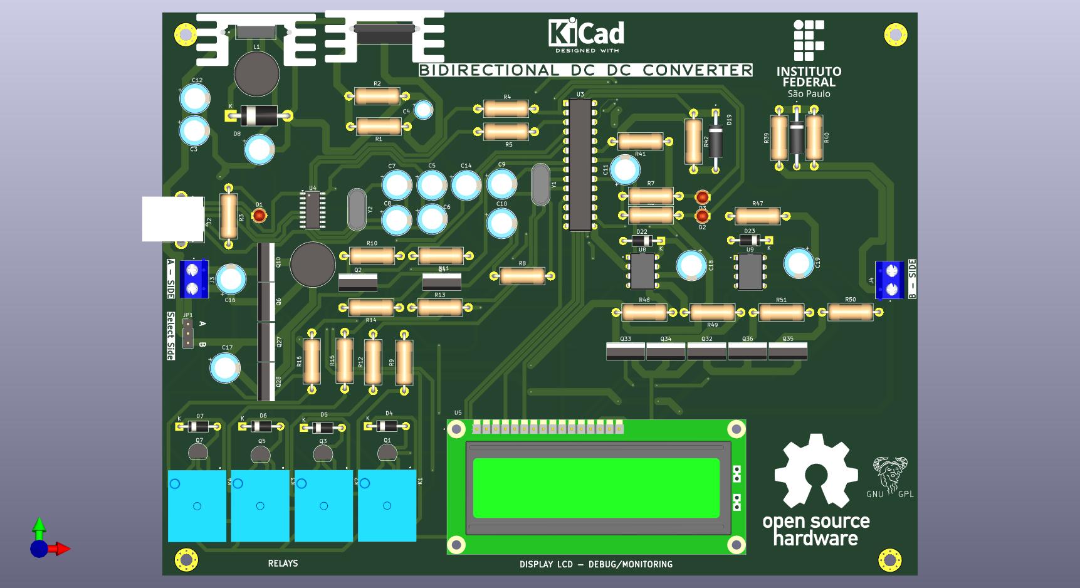
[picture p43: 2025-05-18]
03 - Hadware/06 - 3D View/DC_DC_CONVERTER_TOP.jpg

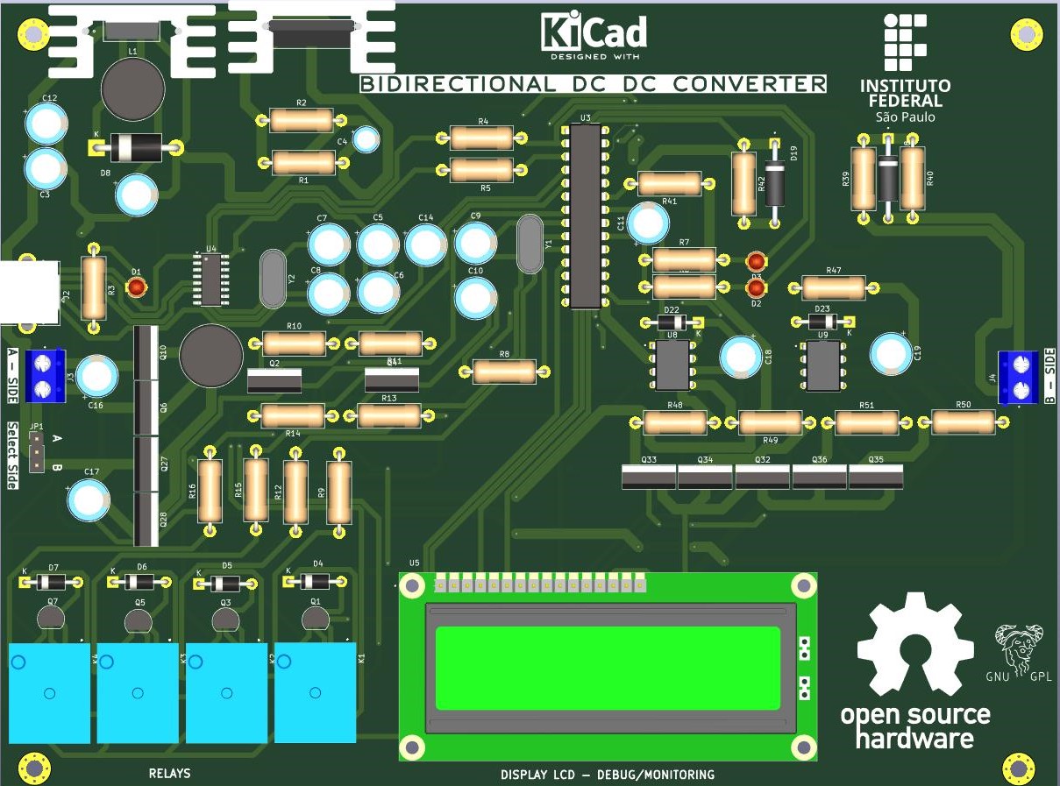
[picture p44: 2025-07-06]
03 - Hadware/06 - 3D View/Figura 3D_1.jpg

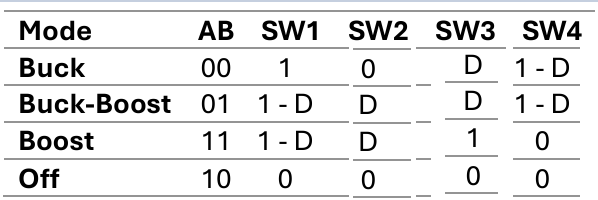
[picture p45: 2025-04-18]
06 - Proteus Simulation/Modo_Texas_ReversoSide.png

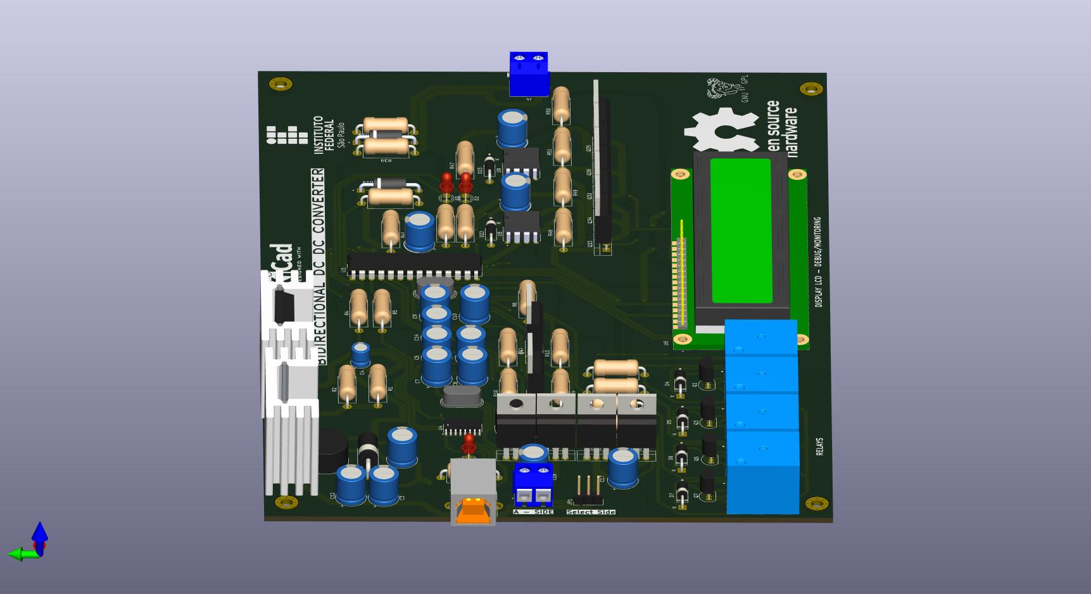
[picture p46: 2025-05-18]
03 - Hadware/06 - 3D View/DC_DC_CONVERTER_TOP3.jpg

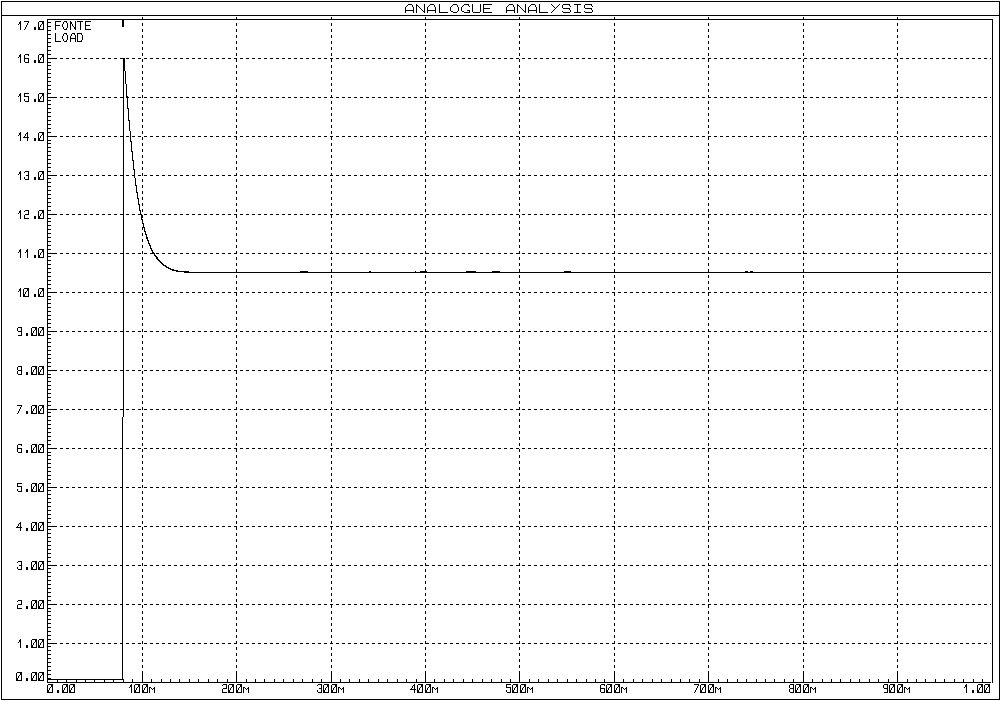
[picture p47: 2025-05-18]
09 - Pictures/Curve_buck.bmp

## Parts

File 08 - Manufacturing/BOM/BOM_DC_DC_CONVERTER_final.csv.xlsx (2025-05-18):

Reference | Value | Qty | Description_1 | Picure | Onde Comprar
C3 | 10uF | 1 |  |  | https://www.baudaeletronica.com.br
C4 | 22uF | 1
C5 | 100nF | 1
C6 | C_Polarized 10uF | 1
C7 | 22pF | 1
C8 | 22pF | 1
C9 | 22pF | 1
C10 | 22pF | 1
C11 | 100nF | 1
C12 | 100uF | 1
C13 | 1000uF | 1
C14 | 22pF | 1
C16 | 135uF | 1
C17 | 135uF | 1
C18 | 47uF | 1
C19 | 47uF | 1
D1 | LED | 1
D2 | LED | 1
D3 | LED | 1
D4 | 1N4004 | 1
D5 | 1N4004 | 1
D6 | 1N4004 | 1
D7 | 1N4004 | 1
D8 | 1N5822 | 1
D18 | 1N5338BG | 1 | Diode Zener Single 5.1V 5% 5W 2-Pin Case 017AA-01 Bulk
D19 | 1N5338BG | 1 | Diode Zener Single 5.1V 5% 5W 2-Pin Case 017AA-01 Bulk
D22 | 1N4004 | 1
D23 | 1N4004 | 1
J2 | USB_B | 1 | Módulo Adaptador USB B para DIP |  | https://www.baudaeletronica.com.br/produto/modulo-adaptador-usb-b-para-dip.html
J3 | Screw_Terminal_01x02 | 1
J4 | Screw_Terminal_01x02 | 1
JP1 | Jumper_3_Open | 1
K1 | SRD-05VDC-SL-C | 1 | 5V Trigger Relay Module For Arduino And Raspberry Pi 5V Trigger Relay Module For Arduino And Raspberry Pi
K2 | SRD-05VDC-SL-C | 1 | 5V Trigger Relay Module For Arduino And Raspberry Pi 5V Trigger Relay Module For Arduino And Raspberry Pi
K3 | SRD-05VDC-SL-C | 1 | 5V Trigger Relay Module For Arduino And Raspberry Pi 5V Trigger Relay Module For Arduino And Raspberry Pi
K4 | SRD-05VDC-SL-C | 1 | 5V Trigger Relay Module For Arduino And Raspberry Pi 5V Trigger Relay Module For Arduino And Raspberry Pi
L1 | 100uH | 1
L2 | 2.78mH | 1 | Indutor Toroidal 470uH 3A |  | https://www.autocorerobotica.com.br/indutor-toroidal-470uh-3a
Q1 | BC547 | 1
Q2 | IRLZ44N | 1
Q3 | BC547 | 1
Q4 | IRLZ44N | 1
Q5 | BC547 | 1
Q6 | IRLZ44N | 1
Q7 | BC547 | 1
Q10 | IRLZ44N | 1 | Transistor IRFZ44N - MOSFET de canal N TO-220 |  | https://www.saravati.com.br/transistor-irfz44n-mosfet-de-canal-n-to-220.html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
Q27 | IRLZ44N | 1 | Transistor IRFZ44N - MOSFET de canal N TO-220 |  | https://www.saravati.com.br/transistor-irfz44n-mosfet-de-canal-n-to-220.html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
Q28 | IRLZ44N | 1 | Transistor IRFZ44N - MOSFET de canal N TO-220 |  | https://www.saravati.com.br/transistor-irfz44n-mosfet-de-canal-n-to-220.html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
Q32 | IRLZ44N | 1 | Transistor IRFZ44N - MOSFET de canal N TO-220 |  | https://www.saravati.com.br/transistor-irfz44n-mosfet-de-canal-n-to-220.html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
Q33 | IRLZ44N | 1 | Transistor IRFZ44N - MOSFET de canal N TO-220 |  | https://www.saravati.com.br/transistor-irfz44n-mosfet-de-canal-n-to-220.html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
Q34 | IRLZ44N | 1 | Transistor IRFZ44N - MOSFET de canal N TO-220 |  | https://www.saravati.com.br/transistor-irfz44n-mosfet-de-canal-n-to-220.html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
Q35 | IRLZ44N | 1 | Transistor IRFZ44N - MOSFET de canal N TO-220 |  | https://www.saravati.com.br/transistor-irfz44n-mosfet-de-canal-n-to-220.html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
Q36 | IRLZ44N | 1 | Transistor IRFZ44N - MOSFET de canal N TO-220 |  | https://www.saravati.com.br/transistor-irfz44n-mosfet-de-canal-n-to-220.html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
R1 | 0.25 | 1
R2 | 3.15 | 1
R3 | 1K | 1
R4 | 1K | 1
R5 | 1K | 1
R6 | 1K | 1
R7 | 1K | 1
R8 | 1M | 1
R9 | 220 | 1
R10 | 220 | 1
R11 | 10K | 1
R12 | 220 | 1
R13 | 220 | 1
R14 | 10K | 1
R15 | 220 | 1
R16 | 220 | 1
R39 | 100K | 1
R40 | 10K | 1
R41 | 100K | 1
R42 | 10K | 1
R47 | 47 | 1
R48 | 220 | 1
R49 | 220 | 1
R50 | 220 | 1
R51 | 220 | 1
U2 | LT1083-ADJ | 1
U3 | ATmega328P-P | 1 | Arduino Uno R3 + Cabo USB 2.0 - A-B |  | https://www.baudaeletronica.com.br/produto/arduino-uno-r3.html
U4 | CH340G | 1 | Módulo Conversor USB 2.0 para TTL CH340G - 6 PINOS |  | https://www.eletrogate.com/modulo-conversor-usb-20-para-rs232-ttl-ch340g-6-pinos?gad_source=1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
U5 | LCD-16X2 | 1 | Display LCD 16x2 (Verde) |  | https://www.baudaeletronica.com.br/produto/display-lcd-16x2-verde.html
U6 | LM2576HVT-5.0 | 1 | Ci Regulador de tensão LM2576HVT-5.0 TO220 - National |  | https://www.acheicomponentes.com.br/ci-regulador-de-tensao-lm2576hvt-5-0
U8 | IR2104 | 1 | Circuito Integrado IR2103 DIP-8 - Cód. Loja 4995 - IR |  | https://www.multcomercial.com.br/circuito-integrado-ir2103-dip-08-cod-loja-4995-ir.html?gad_source=1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
U9 | IR2104 | 1 | Circuito Integrado IR2103 DIP-8 - Cód. Loja 4995 - IR |  | https://www.multcomercial.com.br/circuito-integrado-ir2103-dip-08-cod-loja-4995-ir.html?gad_source=1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
Y1 | 16MHz | 1 | Cristal Oscilador 16MHz - Caneca Baixa |  | https://www.baudaeletronica.com.br/produto/cristal-oscilador-16mhz-caneca-baixa.html?gad_source=1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
Y2 | 12MHz | 1

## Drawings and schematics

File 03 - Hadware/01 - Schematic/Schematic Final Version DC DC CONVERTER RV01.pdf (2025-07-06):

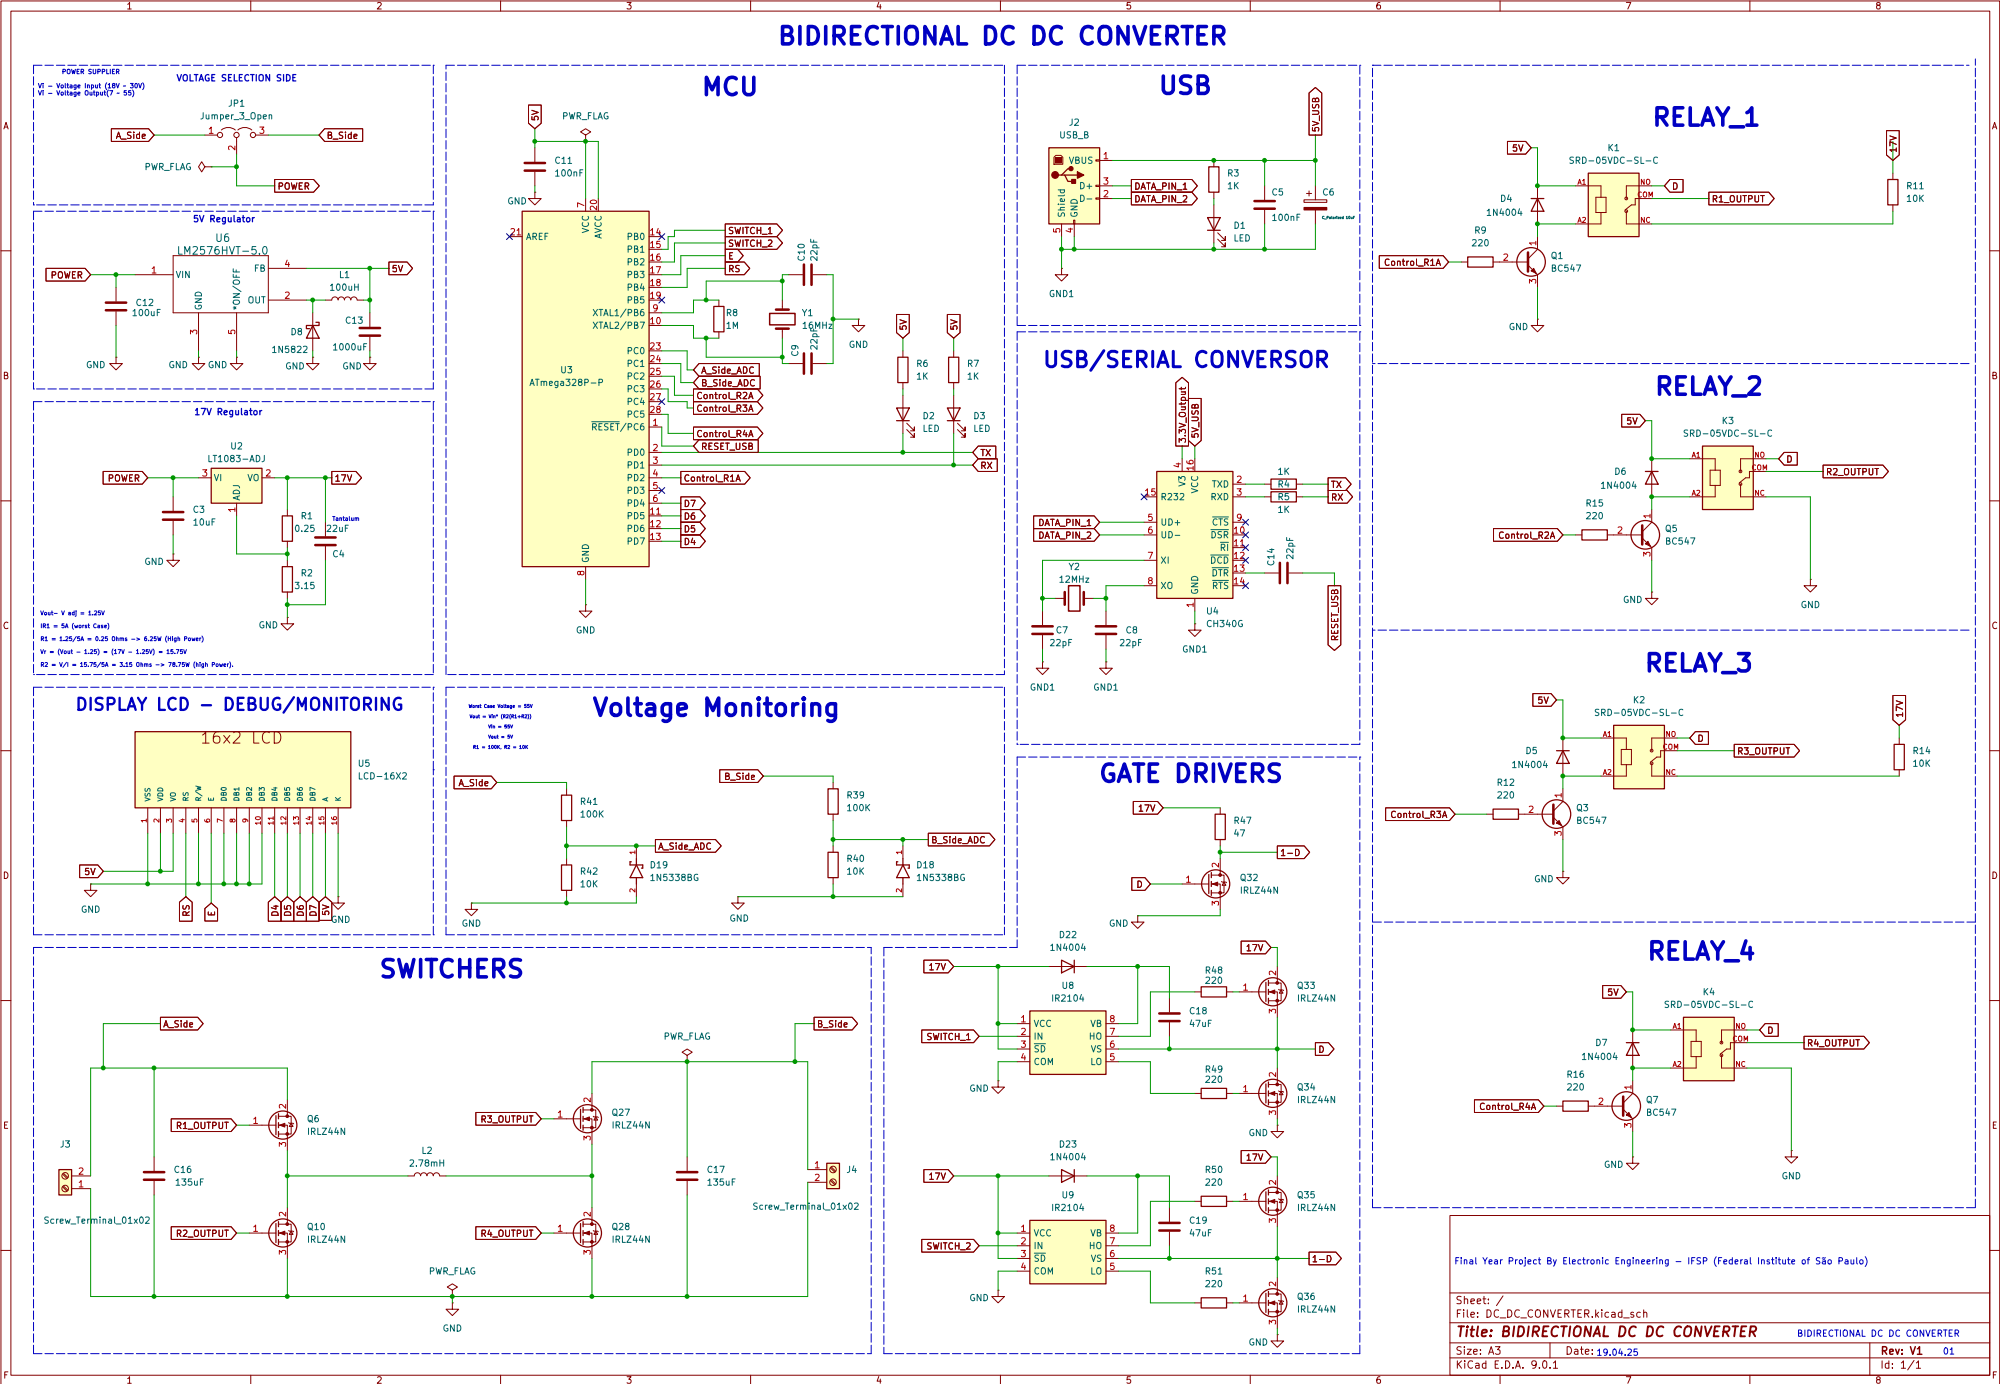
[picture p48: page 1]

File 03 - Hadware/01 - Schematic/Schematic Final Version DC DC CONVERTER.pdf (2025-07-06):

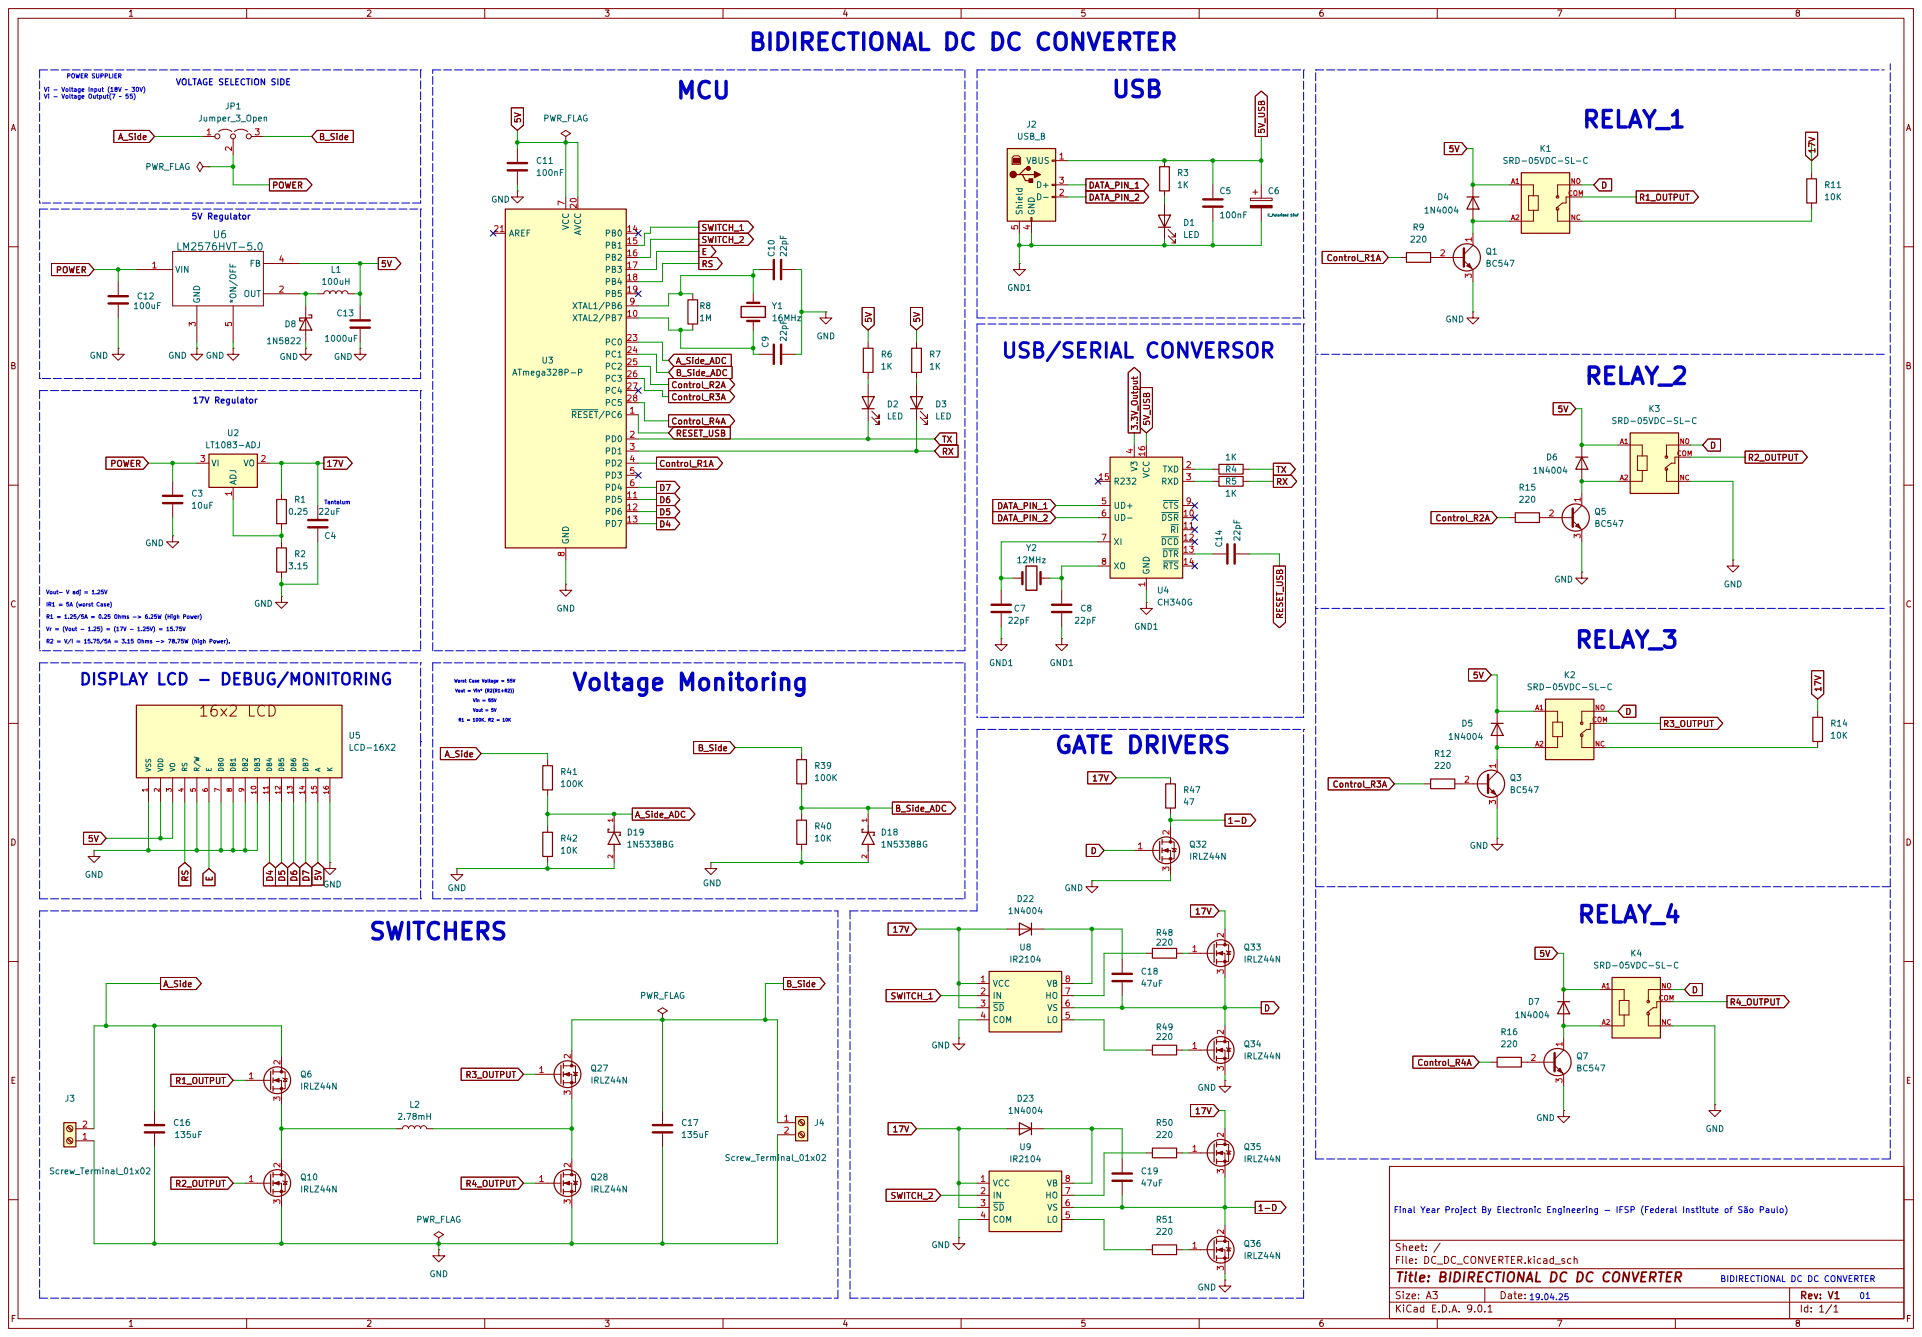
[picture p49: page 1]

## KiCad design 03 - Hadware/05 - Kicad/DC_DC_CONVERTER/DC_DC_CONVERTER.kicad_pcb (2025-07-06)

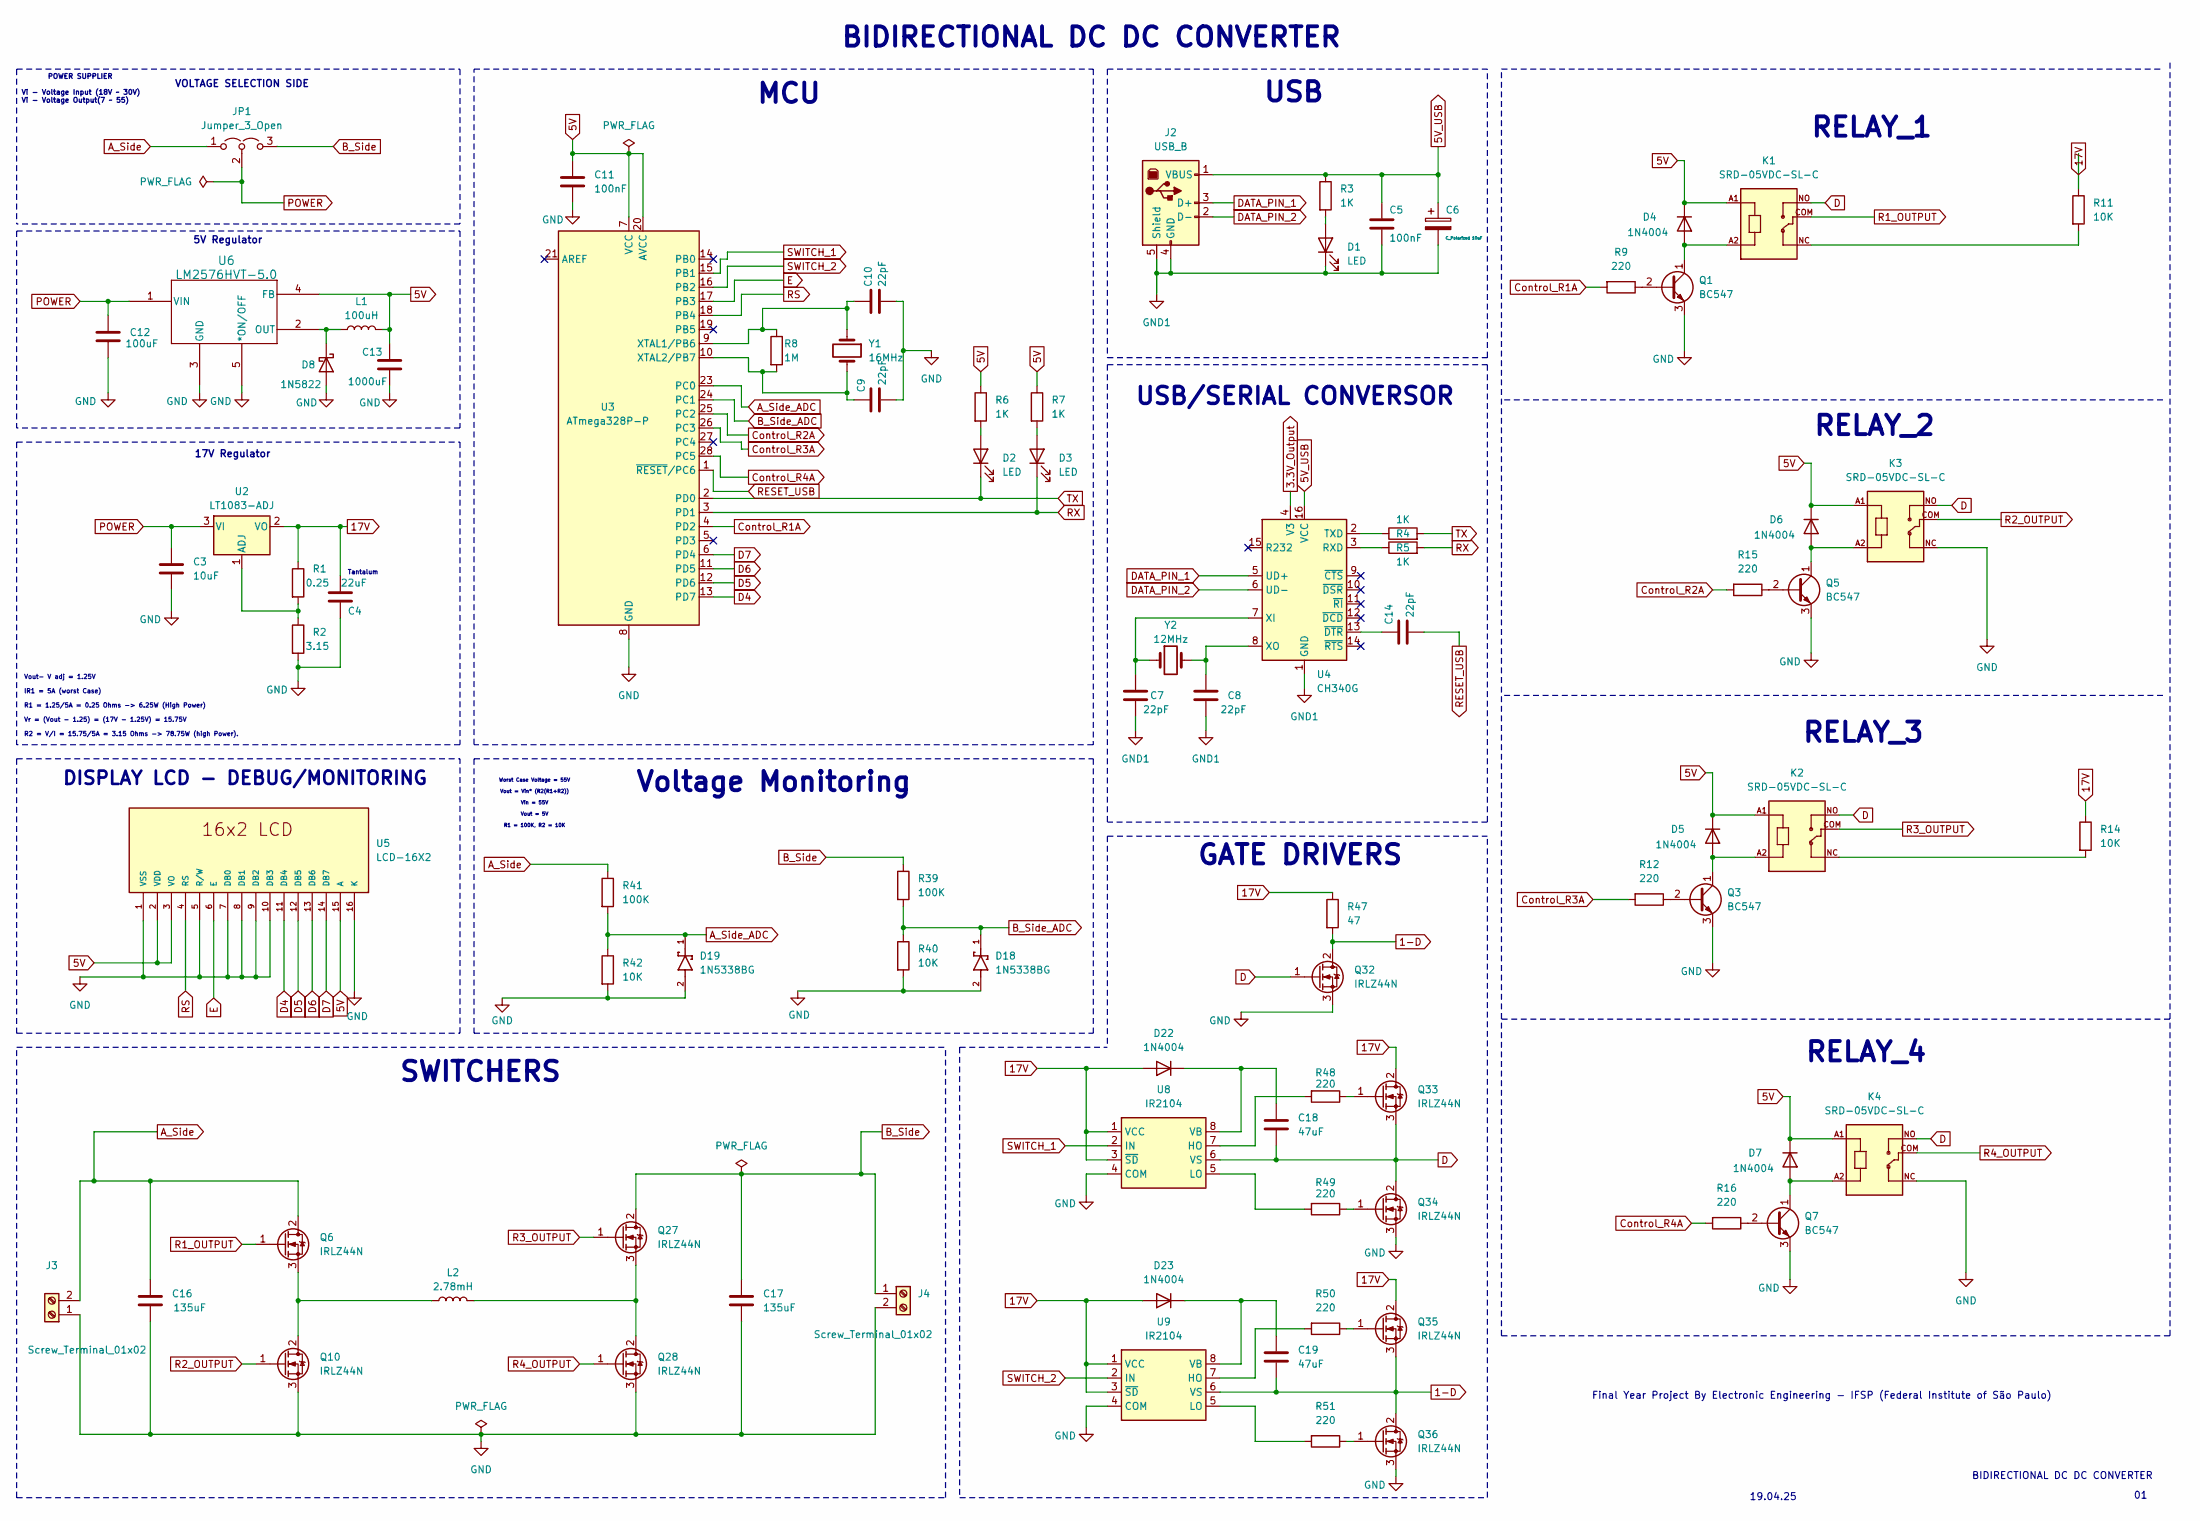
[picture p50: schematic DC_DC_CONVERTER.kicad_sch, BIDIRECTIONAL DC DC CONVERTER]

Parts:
C3: 10uF; CP_Radial_D8.0mm_P5.00mm
C4: 22uF; CP_Radial_D5.0mm_P2.50mm
C5, C11: 100nF; CP_Radial_D8.0mm_P5.00mm
C6: C_Polarized 10uF; CP_Radial_D8.0mm_P5.00mm
C7, C8, C9, C10, C14: 22pF; CP_Radial_D8.0mm_P5.00mm
C12: 100uF; CP_Radial_D8.0mm_P5.00mm
C13: 1000uF; CP_Radial_D8.0mm_P5.00mm
C16, C17: 135uF; CP_Radial_D8.0mm_P5.00mm
C18, C19: 47uF; CP_Radial_D8.0mm_P5.00mm
D1, D2, D3: LED; LED_D3.0mm
D4, D5, D6, D7, D22, D23: 1N4004; D_DO-41_SOD81_P10.16mm_Horizontal
D8: 1N5822; D_DO-201AD_P15.24mm_Horizontal
D18, D19: 1N5338BG; DIOAD1543W101L863D368; PARTREV O
J2: USB_B; USB_B_OST_USB-B1HSxx_Horizontal
J3, J4: Screw_Terminal_01x02; HANDSON_KF301-2P
JP1: Jumper_3_Open; PinHeader_1x03_P2.54mm_Vertical
K1, K2, K3, K4: SRD-05VDC-SL-C; RELAY_SRD-05VDC-SL-C
L1: 100uH; L_Radial_D12.0mm_P6.00mm_Murata_1900R
L2: 2.78mH; L_Radial_D12.0mm_P6.00mm_Murata_1900R
Q1, Q3, Q5, Q7: BC547; TO-92_Inline
Q6, Q10, Q27, Q28, Q32, Q33, Q34, Q35, Q36: IRLZ44N; TO-220-3_Vertical
R1: 0.25; R_Axial_DIN0414_L11.9mm_D4.5mm_P15.24mm_Horizontal
R2: 3.15; R_Axial_DIN0414_L11.9mm_D4.5mm_P15.24mm_Horizontal
R3, R4, R5, R6, R7: 1K; R_Axial_DIN0414_L11.9mm_D4.5mm_P15.24mm_Horizontal
R8: 1M; R_Axial_DIN0414_L11.9mm_D4.5mm_P15.24mm_Horizontal
R9, R12, R15, R16, R48, R49, R50, R51: 220; R_Axial_DIN0414_L11.9mm_D4.5mm_P15.24mm_Horizontal
R11, R14, R40, R42: 10K; R_Axial_DIN0414_L11.9mm_D4.5mm_P15.24mm_Horizontal
R39, R41: 100K; R_Axial_DIN0414_L11.9mm_D4.5mm_P15.24mm_Horizontal
R47: 47; R_Axial_DIN0414_L11.9mm_D4.5mm_P15.24mm_Horizontal
U2: LT1083-ADJ; TO-3P_P_LIT
U3: ATmega328P-P; DIP-28_W7.62mm
U4: CH340G; SOIC-16_3.9x9.9mm_P1.27mm
U5: LCD-16X2; MODULE_LCD-16X2; PARTREV N/A
U6: LM2576HVT-5.0; T05A_TEX
U8, U9: IR2104; DIP762W45P254L988H533Q8
Y1: 16MHz; Crystal_HC49-4H_Vertical
Y2: 12MHz; Crystal_HC49-4H_Vertical

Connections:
1-D: C19.2, Q32.2 (D), Q35.3 (S), Q36.2 (D), R47.2, U9.6 (VS)
3.3V_Output: U4.4 (V3)
5V: C11.1, C13.1, D4.1 (K), D5.1 (K), D6.1 (K), D7.1 (K), K1.A1, K2.A1, K3.A1, K4.A1, L1.2, R6.1, R7.1, U3.7 (VCC), U3.20 (AVCC), U5.2 (VDD), U5.3 (VO), U5.15 (A), U6.4 (FB)
5V_USB: C5.1, C6.1, J2.1 (VBUS), R3.1, U4.16 (VCC)
17V: C4.1, D22.2 (A), D23.2 (A), Q33.2 (D), Q35.2 (D), R1.1, R11.1, R14.1, R47.1, U2.2 (VO), U8.1 (VCC), U8.3 (~SD), U9.1 (VCC), U9.3 (~SD)
A_Side: C16.1, J3.2, JP1.1 (A), Q6.2 (D), R41.1
A_Side_ADC: D19.1, R41.2, R42.1, U3.23 (PC0)
B_Side: C17.1, J4.1, JP1.3 (B), Q27.2 (D), R39.1
B_Side_ADC: D18.1, R39.2, R40.1, U3.24 (PC1)
Control_R1A: R9.2, U3.4 (PD2)
Control_R1B: U3.5 (PD3); also elsewhere on the board
Control_R2A: R15.2, U3.25 (PC2)
Control_R3A: R12.2, U3.26 (PC3)
Control_R3B: U3.27 (PC4); also elsewhere on the board
Control_R4A: R16.2, U3.28 (PC5)
D: C18.2, K1.NO, K2.NO, K3.NO, K4.NO, Q32.1 (G), Q33.3 (S), Q34.2 (D), U8.6 (VS)
D4: U3.13 (PD7), U5.11 (DB4)
D5: U3.12 (PD6), U5.12 (DB5)
D6: U3.11 (PD5), U5.13 (DB6)
D7: U3.6 (PD4), U5.14 (DB7)
DATA_PIN_1: J2.3 (D+), U4.5 (UD+)
DATA_PIN_2: J2.2 (D-), U4.6 (UD-)
E: U3.17 (PB3), U5.6 (E)
GND: C3.2, C4.2, C9.2, C10.2, C11.2, C12.2, C13.2, C16.2, C17.2, D8.2 (A), D18.2, D19.2, J3.1, J4.2, K3.NC, K4.NC, Q1.3 (E), Q3.3 (E), Q5.3 (E), Q7.3 (E), Q10.3 (S), Q28.3 (S), Q32.3 (S), Q34.3 (S), Q36.3 (S), R2.2, R40.2, R42.2, U3.8 (GND), U3.22 (GND), U5.1 (VSS), U5.5 (R/W), U5.7 (DB0), U5.8 (DB1), U5.9 (DB2), U5.10 (DB3), U5.16 (K), U6.3 (GND), U6.5 (*ON/OFF), U8.4 (COM), U9.4 (COM); also elsewhere on the board
GND1: C5.2, C6.2, C7.2, C8.2, D1.1 (K), J2.4 (GND), J2.5 (Shield), U4.1 (GND)
unnamed: D1.2 (A), R3.2
unnamed: D2.2 (A), R6.2
unnamed: D3.2 (A), R7.2
unnamed: D4.2 (A), K1.A2, Q1.1 (C)
unnamed: D5.2 (A), K2.A2, Q3.1 (C)
unnamed: D6.2 (A), K3.A2, Q5.1 (C)
unnamed: D7.2 (A), K4.A2, Q7.1 (C)
unnamed: D8.1 (K), L1.1, U6.2 (OUT)
unnamed: C18.1, D22.1 (K), U8.8 (VB)
unnamed: C19.1, D23.1 (K), U9.8 (VB)
unnamed: Q1.2 (B), R9.1
unnamed 36: K1.NC, R11.2; also elsewhere on the board
unnamed: Q3.2 (B), R12.1
unnamed 39: K2.NC, R14.2; also elsewhere on the board
unnamed: Q5.2 (B), R15.1
unnamed: Q7.2 (B), R16.1
unnamed: L2.1, Q6.3 (S), Q10.2 (D)
unnamed: L2.2, Q27.3 (S), Q28.2 (D)
unnamed: Q33.1 (G), R48.1
unnamed: Q34.1 (G), R49.1
unnamed: Q35.1 (G), R50.1
unnamed: Q36.1 (G), R51.1
unnamed: R1.2, R2.1, U2.1 (ADJ)
unnamed: C10.1, R8.1, U3.9 (XTAL1/PB6), Y1.1
unnamed: C9.1, R8.2, U3.10 (XTAL2/PB7), Y1.2
unnamed: R5.1, U4.3 (RXD)
unnamed: R4.1, U4.2 (TXD)
unnamed: C7.1, U4.7 (XI), Y2.1
unnamed: C8.1, U4.8 (XO), Y2.2
unnamed: C14.1, U4.13 (~DTR)
unnamed: R48.2, U8.7 (HO)
unnamed: R49.2, U8.5 (LO)
unnamed: R50.2, U9.7 (HO)
unnamed: R51.2, U9.5 (LO)
POWER: C3.1, C12.1, JP1.2 (C), U2.3 (VI), U6.1 (VIN)
R1_OUTPUT: K1.COM, Q6.1 (G)
R2_OUTPUT: K3.COM, Q10.1 (G)
R3_OUTPUT: K2.COM, Q27.1 (G)
R4_OUTPUT: K4.COM, Q28.1 (G)
RESET_USB: C14.2, U3.1 (~RESET/PC6)
RS: U3.18 (PB4), U5.4 (RS)
RX: D3.1 (K), R5.2, U3.3 (PD1)
SWITCH_1: U3.15 (PB1), U8.2 (IN)
SWITCH_2: U3.16 (PB2), U9.2 (IN)
TX: D2.1 (K), R4.2, U3.2 (PD0)

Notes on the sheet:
17V Regulator
Final Year Project By Electronic Engineering - IFSP (Federal Institute of São Paulo)
DISPLAY LCD - DEBUG/MONITORING
19.04.25
MCU
Tantalum
Worst Case Voltage = 55V Vout = Vin* (R2(R1+R2)) Vin = 55V Vout = 5V R1 = 100K, R2 = 10K
VOLTAGE SELECTION SIDE
RELAY_4
POWER SUPPLIER Vi - Voltage Input (18V ~ 30V) Vi - Voltage Output(7 ~ 55)
BIDIRECTIONAL DC DC CONVERTER
USB/SERIAL CONVERSOR
SWITCHERS
Voltage Monitoring
5V Regulator
BIDIRECTIONAL DC DC CONVERTER
RELAY_3
RELAY_1
Vout- V adj = 1.25V IR1 = 5A (worst Case) R1 = 1.25/5A = 0.25 Ohms -> 6.25W (High Power) Vr = (Vout - 1.25) = (17V - 1.25V) = 15.75V R2 = V/I = 15.75/5A = 3.15 Ohms -> 78.75W (high Power).
USB
RELAY_2
GATE DRIVERS

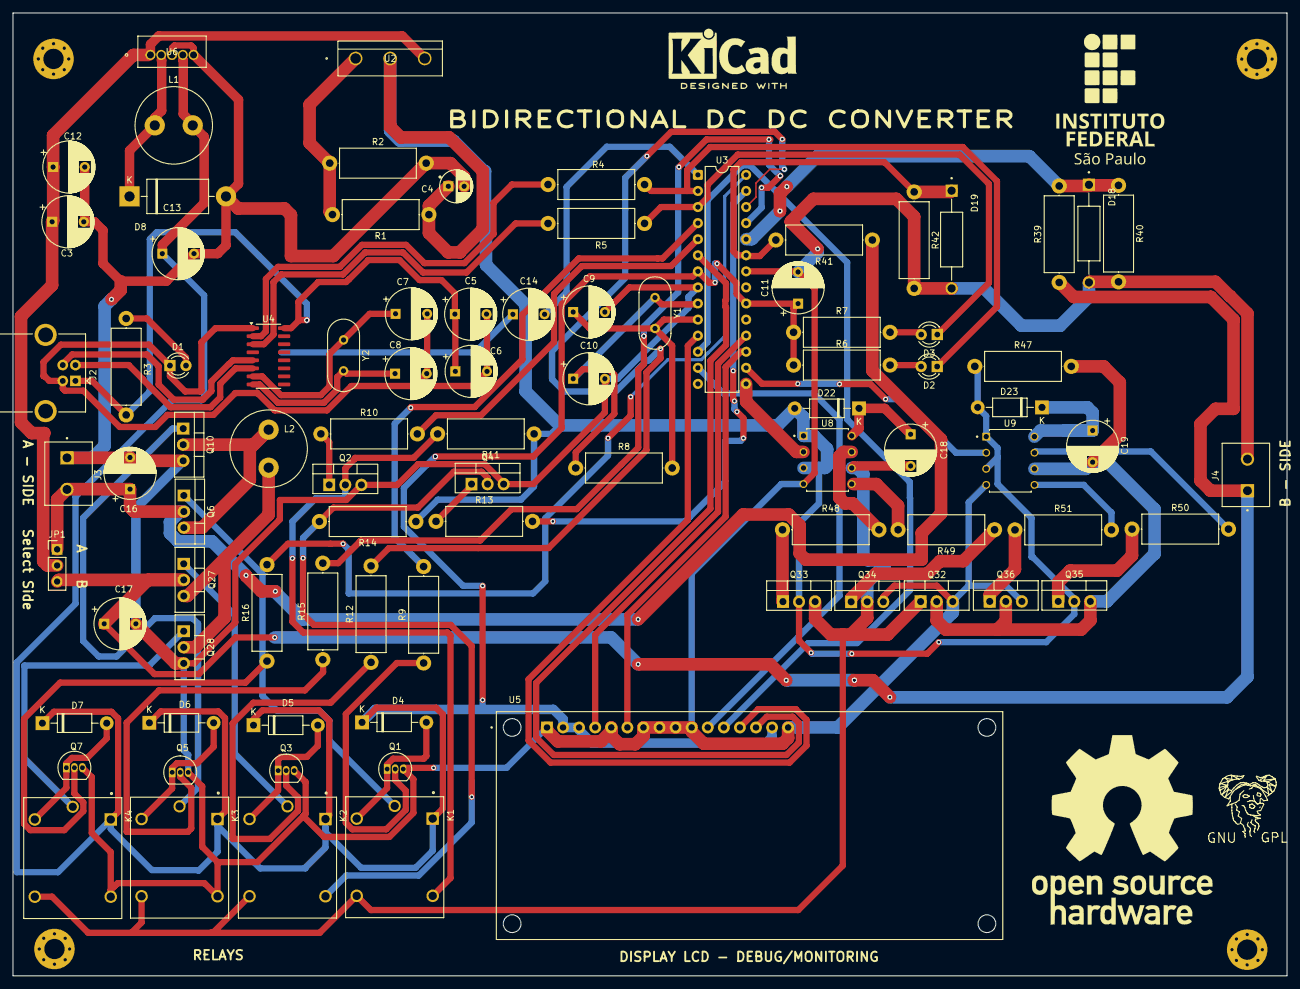
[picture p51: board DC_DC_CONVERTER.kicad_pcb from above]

Board: 2 copper layers, 201.3 x 152.1 mm, 87 parts (0 on the bottom side), 71 nets.

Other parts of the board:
Q2, Q4: IRLZ44N; TO-220-3_Vertical
R10, R13: 220; R_Axial_DIN0414_L11.9mm_D4.5mm_P15.24mm_Horizontal

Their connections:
Control_R1B: R10.2; also elsewhere on the board
Control_R3B: R13.2; also elsewhere on the board
GND: Q2.3 (S), Q4.3 (S); also elsewhere on the board
unnamed 36: Q2.2 (D); also elsewhere on the board
unnamed: Q2.1 (G), R10.1
unnamed 39: Q4.2 (D); also elsewhere on the board
unnamed: Q4.1 (G), R13.1

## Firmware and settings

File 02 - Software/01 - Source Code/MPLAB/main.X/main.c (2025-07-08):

//--------------------------------------------------------------
// Define aliases
#define F_CPU 16000000      // Microcontroller frequency

//Include header librarys
#include <avr/io.h>         // Definitions of the specified component
#include <util/delay.h>     // Use delay functions
#include <avr/interrupt.h>  // Use interruptions
#include <avr/pgmspace.h> 	// Write data to flash memory
#include <stdio.h>			// Use sprintf functions
#include <math.h>			// Use math functions
#include <stdbool.h>		// Use boolean variables
#include <stdint.h>

// Global variables
volatile bool a, b;
volatile unsigned int x[3] = {0};
volatile float ref, source, output, error, duty, fis_duty = 0;

// Include header files
#include "LCD.h" 			// Use the LCD
#include "ADC.h"			// Use the ADC
#include "lcd_setup.h"      // Setup and use the LCD
#include "sensor_sub.h"     // Sensor subsystem
#include "error_sub.h"      // Error subsystem
#include "lut_setup.h"      // Control setup and subsystem
#include "mode_setup.h"     // Mode setup and subsystem
#include "pwm_setup.h"		// PWM setup
#include "timer_setup.h"	// Time interruption setup
//--------------------------------------------------------------
int main(void){
	// Initializes peripherals
	lcd_setup();
	inicializa_ADC();
	mode_setup();
	pwm_setup();
	timer_setup();
	
    // Turn on interruptions
    sei();
    
    // Initializes system
	sensor_sub();
	error_sub();
	fis_output();
	mode_sub();
//------------------------------
    while(1){
	lcd_sub();
	}
//------------------------------
}
//--------------------------------------------------------------
ISR(TIMER2_COMPA_vect){
	sensor_sub();
	error_sub();
	fis_output();
	mode_sub();
}
//--------------------------------------------------------------

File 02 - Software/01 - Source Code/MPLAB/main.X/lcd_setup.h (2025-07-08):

//--------------------------------------------------------------
void lcd_setup(){
	// Define pins as output
	DDRD |= (1<<PD2) | (1<<PD3);		// E (D2), RS (D3)
	DDRD |= (1<<PD4) | (1<<PD5) | (1<<PD6) | (1<<PD7);	// Data path
	
	// Initializes the LCD
	inic_LCD_4bits();				// From "LCD.h" header
	cmd_LCD(0x01,0);				// Clear the LCD
}
//--------------------------------------------------------------
void lcd_sub(){
	char buffer[6] = "";
	
	sprintf(buffer, "%.1f", ref);
	cmd_LCD(0x80,0);
	escreve_LCD(buffer);
	
	sprintf(buffer, "%.1f", source);
	cmd_LCD(0x85,0);
	escreve_LCD(buffer);
	
	cmd_LCD(0x8A,0);
	if(!b)escreve_LCD("-");
	else if(a)escreve_LCD("+");
	else escreve_LCD("*");
	
	sprintf(buffer, "%.1f", output);
    cmd_LCD(0x8C,0);
	escreve_LCD(buffer);
	
	sprintf(buffer, "%.1f", error);
    cmd_LCD(0xC0,0);
	escreve_LCD(buffer);
	
	sprintf(buffer, "%.2f", fis_duty);
    cmd_LCD(0xC5,0);
	escreve_LCD(buffer);
	
	sprintf(buffer, "%.2f", duty);
    cmd_LCD(0xCB,0);
	escreve_LCD(buffer);
}
//--------------------------------------------------------------

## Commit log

2025-01-06 Add Button
2025-01-09 Teste vinculãção de contas
2025-02-13 Add arduino in proteus simulation
2025-02-15 add gate driver circuit in proteus
2025-02-23 Add lista de abreviatures 23.02.25
2025-03-02 Moved the folder labview arduino
2025-03-05 add bidirectional circuit in conversor 04.03.25
2025-03-06 Replaced IRF540N Mosfet with IRLZ44N Mosfet - Less Rds(on) 05.03.25
    [Protheus_Simulation_Firmware.ino]
2025-03-06 Replaced inductor 22uH with inductor 47uH 05.03.25
    [Protheus_Simulation_Firmware.ino]
2025-03-07 Upate title of monograph add Four Switch 06.03.25
2025-04-12 replace IRF540N by IRLZ44N in gate driver circuit 12.04.25
2025-04-19 update folder org
    [DC_DC_CONVERTER.kicad_pcb, DC_DC_CONVERTER.kicad_sch]
2025-05-04 Schematic final version 04.05.25
    [DC_DC_CONVERTER.kicad_pcb, DC_DC_CONVERTER.kicad_sch, Power_Side_sch.kicad_sch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]
2025-05-18 release pires 18.05.25 update: Schematic/Layout/Priteus simulation/Matlab Simulation/Monogroph
    [BOM_DC_DC_CONVERTER_final.csv.xlsx, DC_DC_CONVERTER.csv, DC_DC_CONVERTER.kicad_pcb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]
2025-07-06 add picture folder
    [DC_DC_CONVERTER.kicad_pcb, DC_DC_CONVERTER.kicad_sch]
2025-07-06 add circuit picture
2025-07-06 add buck boost picture switches
